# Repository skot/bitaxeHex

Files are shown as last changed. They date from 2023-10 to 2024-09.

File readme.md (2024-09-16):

Warning: the bitaxeHex is unfinished. there may be hardware and firmware bugs. Please see The bitaxeHex channel on the [OSMU Discord](https://discord.gg/osmu) for the latest status

> Closed Source is Antithetical to Bitcoin

# Presenting: The bitaxeHex
bitaxeHex is a follow on to the [bitaxe](https://github.com/skot/bitaxe) that incorporates six BM1366 ASICs from the Antminer S19XP

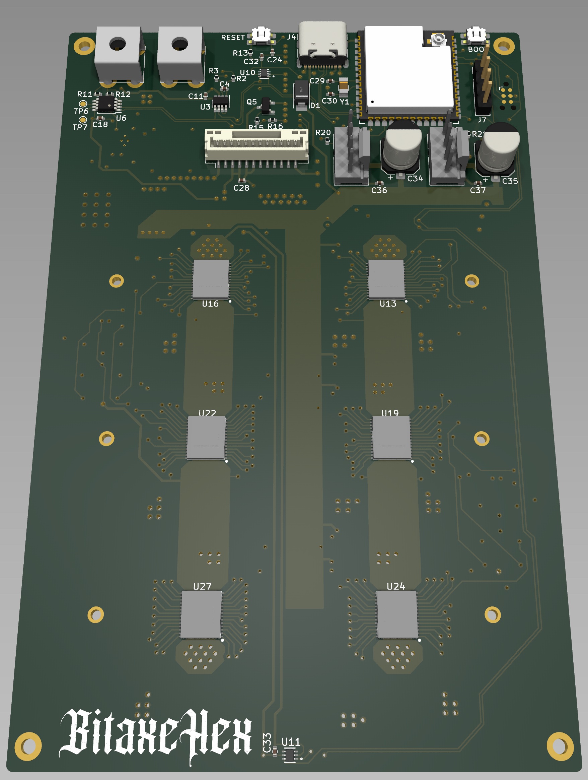
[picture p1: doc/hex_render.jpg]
bitaxeHex render


## Goals
- **Standalone**: can mine directly to your pool over WiFi. No External computer needed.
- **Embedded**: low cost, low maintenance, high availability, high reliability, low power.
- **ASIC**: based on the very efficient BM1366 from Bitmain.
- **Versatile**: solo/pool mining, autotune power/heat/efficiency.
- **Open Source**: All design files are provided.

## Features
- **ESP32-S3-WROOM-1** wifi microcontroller on board
- **TI TPS546D24ARVFR** buck regulator steps down the 12V input to power the chain of BM1366
- **TMP1075** measures inlet and outlet PCB temperature.
- **Microchip EMC2302** Controls dual fans
- Header for optional status LCD

## BM1366
- The BM1366 is a undocumented SHA256 mining ASIC from Bitmain. It's mostly used in the Antminer S19XP and S19K Pro
- Bitmain claims the BM1366 has 21.5 W/TH efficiency
- The BM1366 is available (new) for around $15 each.

## Current Status
- v304 This is going to be the official release candidate, but boards have not been produced yet, this version is not final.
- Power draw is around 50W @12V.
- ESP32 miner firmware will configure the power supply to run at the proper voltage.
- This is an _advanced_ build! If you don't have experience building boards, you should probably go build a single ASIC bitaxe first to get the technique down.

## Notes
- Beware that overclocking doesn't produce a higher hash rate on this board, it only causes more heat generation.
- If you decide to build a pre-release board, be sure to order 2 oz. copper on both the internal and external layers.
- The recommended heatsink is not anodized and very conductive on all surfaces. This _should_ be OK as the ASIC tops are not known to be conductive, but this needs some more investigation.

## Revision List
- v304 is a work in progress, some capacitor changes, additional features
- v303 has some improvements in the layout and the 33R inline resistors have been removed.
- V302 is the current working version of this board.  If you want to build this, pull down this git tag.
- V301 does not work, the power supply maintains voltage, but overheats in a drastic way
- V300 does not work, the power supply cannot maintain voltage when a load is applied

## Hardware
- [BM1366 from NBTC on AliExpress](https://www.aliexpress.us/item/3256803471845503.html). Both the `AL` and `AG` variants have been known to work.
- [Heatsink](https://www.aliexpress.us/item/3256805608902122.html) 90mm long variant. This will need to have threaded M3 mounting holes added. See the KiCad board file for the pattern
- [Fans](https://www.amazon.com/Noctua-NF-A8-PWM-Premium-Quiet/dp/B00NEMG62M) At least one 80x80mm 12V 4-pin fan. Like the Noctua NF-A8 PWM. Possibly two.
- [Enclosure](https://www.aliexpress.us/item/3256806064761702.html) (several sellers) 130mm long variant. The bitaxeHex needs to be run inside an enclosure to force air through the heatsink and effectively cool the BM1366s
- The TPS546 can potentially benefit from a [small self-adhesive heatsink](https://www.amazon.com/gp/product/B093V6RK58/) on the top of the package.
- All of the parts on the board are listed in the KiCad BOM

## Software
- [ESP-Miner-multichip](https://github.com/bitaxeorg/esp-miner-multichip) a fork of esp-miner to support multiple ASICs like on the bitaxeHex.

## Power Supply Requirements
- bitaxeHex takes 12V DC input via screw terminals. Power supply should be capable of 100W
  - This [120W Brick](https://www.amazon.com/gp/product/B07PWZQ33N) technically works, but gets a little warmer than it should. You'll need to change the end.
  - 12V 15A 110V AliExpress [Bare PSU](https://www.aliexpress.us/item/3256805439916551.html)

## Building
- Check out [building.md](building.md) for PCB ordering tips
- Check out [assembly.md](assembly.md) for assembly tips

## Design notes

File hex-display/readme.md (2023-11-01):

# BitaxeHex display adapter board
This adapater board provides a connection from the BitaxeHex to a 
172x320 SPI interface ST7789 Drive OLED graphic display.  This is 
intended for use on the [bitaxeHex](https://github.com/skot/bitaxeHex).
Currently, the firmware to drive it has not been developed, so this is 
provided in order to facilitate that effort.

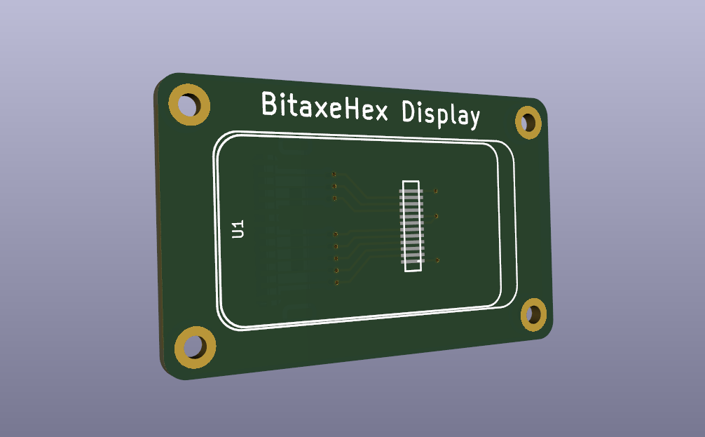
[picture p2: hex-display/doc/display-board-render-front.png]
bitaxeHex display front

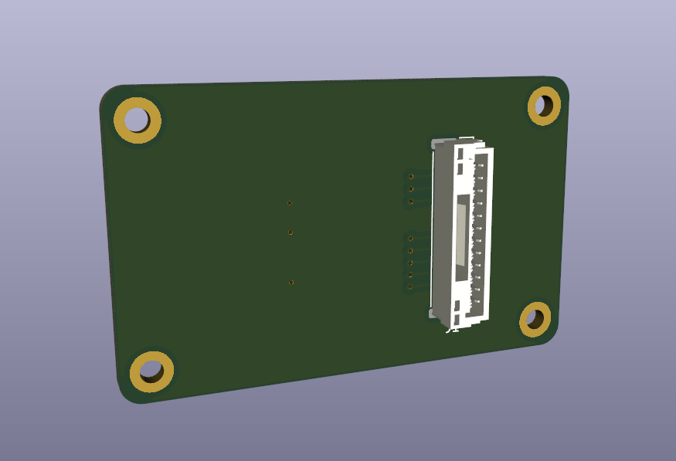
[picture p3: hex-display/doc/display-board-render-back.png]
bitaxeHex display back


The cable to connect it is constructed with a pair of JST-GH 12-pin housings, and 
cables that run straight through.  

## Parts
- [172x320 OLED display](https://www.aliexpress.us/item/3256804691627769.html)
- [JST-GH 12-pin housing](https://www.digikey.com/en/products/detail/jst-sales-america-inc/GHR-12V-S/807824)
- [JST-GH pre-crimped wires](https://www.digikey.com/en/products/detail/jst-sales-america-inc/AGHGH28K305/6009450)

To construct the cable:
- qty 12 of the pre-crimped cables
- qty 2 of the JST-GH housings

Insert the cables into the housings with the locking pin facing the same direction (both towards you)

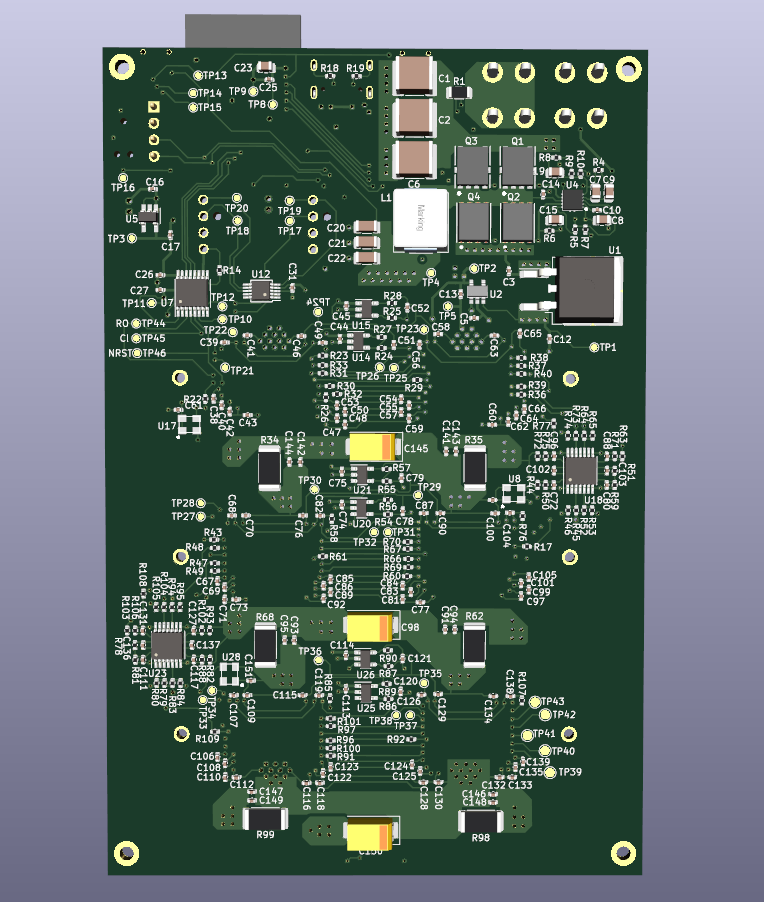
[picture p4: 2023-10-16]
doc/render-back.png

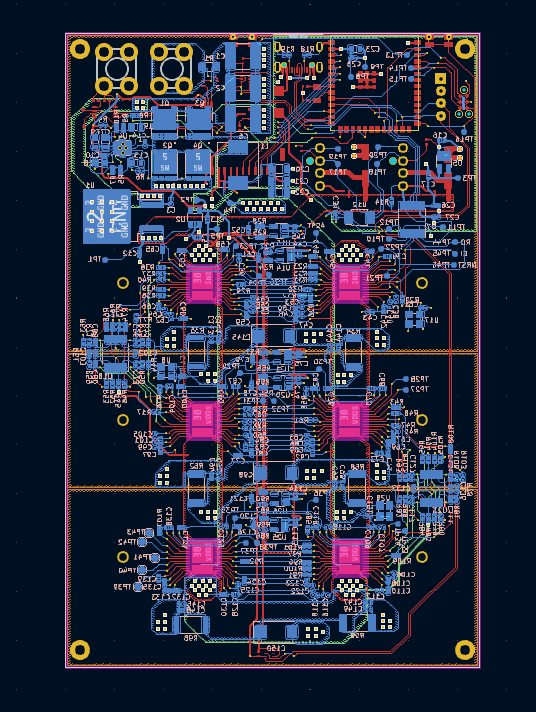
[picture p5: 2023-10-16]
doc/pcb-snapshot.png

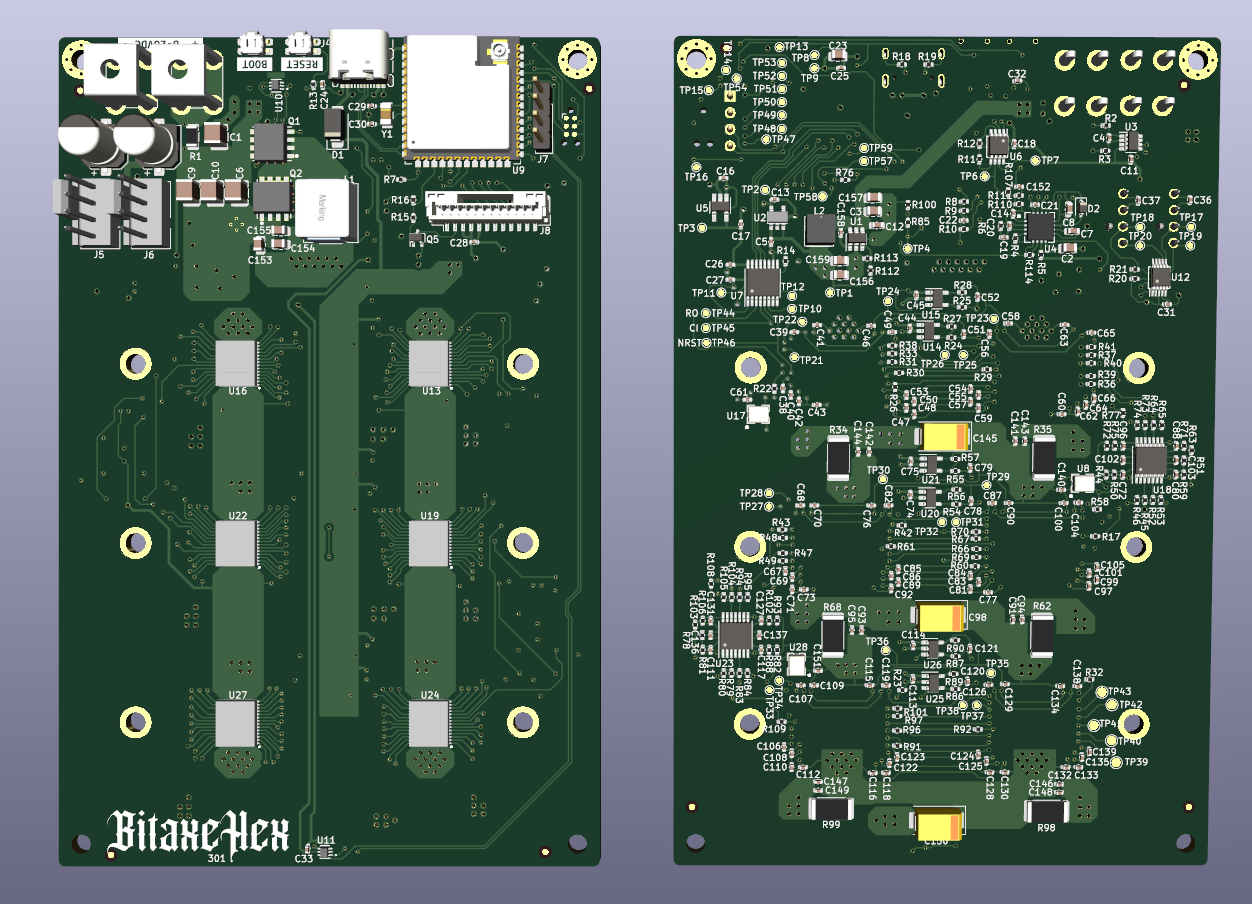
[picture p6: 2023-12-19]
doc/bitaxeHex-301-render.png

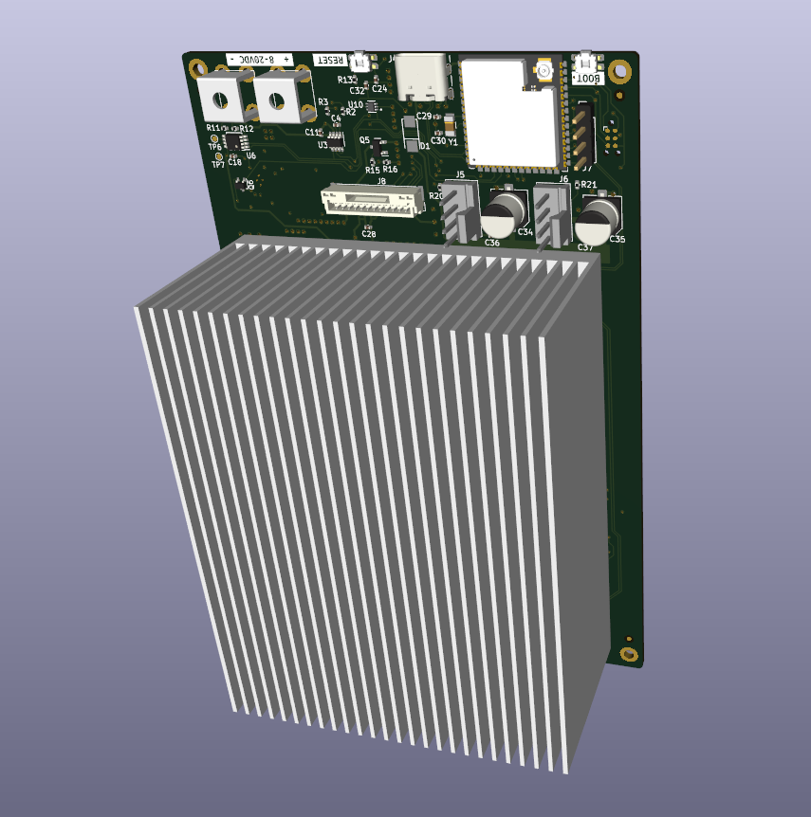
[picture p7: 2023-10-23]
doc/render1-with-heatsink.png

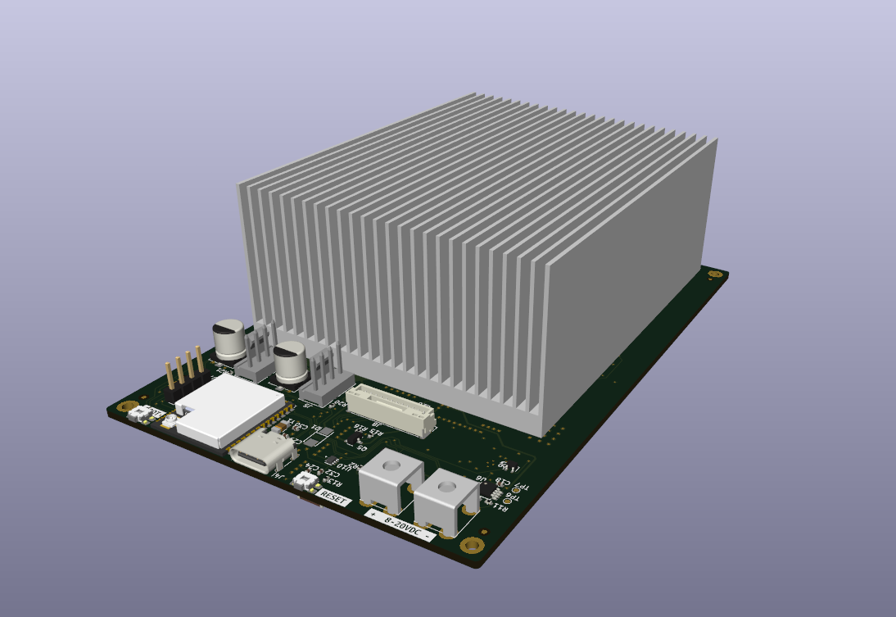
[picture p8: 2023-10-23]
doc/render2-with-heatsink.png

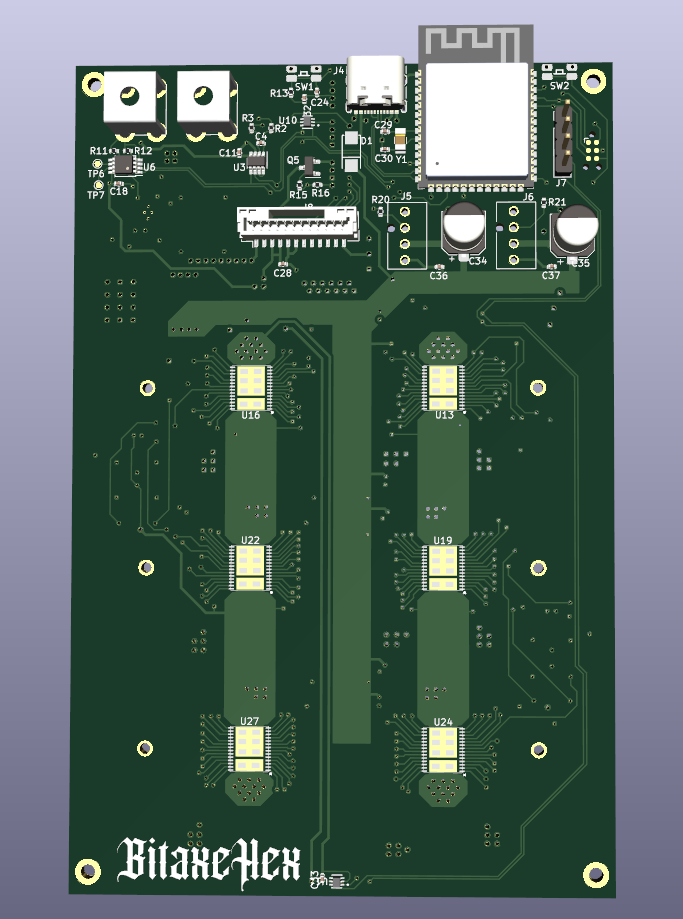
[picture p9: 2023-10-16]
doc/render-front.png

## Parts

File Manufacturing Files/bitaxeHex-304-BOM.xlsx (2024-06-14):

 | Bitaxe Hex v304 BOM
Qty | Reference | Value | Footprint | DK | PARTNO
5 | C1, C3, C18, C20, C31 | 10uF | Capacitor_SMD:C_0805_2012Metric | 490-18664-1-ND | GRM21BR61H106ME43L
1 | C2 | 4.7nF | Capacitor_SMD:C_0402_1005Metric | 490-1309-1-ND | GRM155R71E472KA01D
4 | C4, C7, C8, C10 | 22uF | Capacitor_SMD:C_1206_3216Metric | 445-6000-1-ND | C3216X5R1E226M160AB
1 | C5 | 1uF | Capacitor_SMD:C_0603_1608Metric | 490-1550-1-ND | GRM188R60J105KA01D
1 | C6 | 0.1uF | Capacitor_SMD:C_0603_1608Metric | 478-KGM15BR71H104KTCT-ND | KGM15BR71H104KT
2 | C9, C154 | 47uF | Capacitor_SMD:C_1206_3216Metric | 445-C3216X5R1E476M160DCCT-ND | C3216X5R1E476M160DC
91 | C11, C19, C21, C25, C32, C45, C46, C47, C48, C49, C52, C53, C54, C55, C56, C57, C58, C59, C61, C63, C64, C65, C66, C67, C69, C70, C71, C72, C74, C75, C76, C77, C78, C79, C80, C81, C83, C85, C86, C87, C88, C89, C90, C91, C92, C94, C96, C97, C98, C99, C100, C102, C103, C104, C105, C107, C108, C109, C110, C112, C113, C114, C115, C116, C117, C118, C119, C120, C123, C124, C125, C126, C127, C128, C129, C131, C133, C134, C135, C136, C137, C138, C139, C141, C143, C144, C145, C146, C148, C149, C150 | 1uF | Capacitor_SMD:C_0402_1005Metric | 587-5514-1-ND | EMK105BJ105MV-F
19 | C12, C33, C50, C51, C60, C62, C73, C82, C84, C93, C95, C106, C111, C121, C122, C130, C132, C142, C147 | 0.1uF | Capacitor_SMD:C_0402_1005Metric | 478-KGM05AR71C104KHCT-ND | KGM05AR71C104KH
1 | C13 | 100nF | Capacitor_SMD:C_0402_1005Metric | 490-6321-1-ND | GRM155R71A104KA01D
2 | C14, C15 | 1uF | Capacitor_SMD:C_0805_2012Metric | 587-1291-1-ND | TMK212BJ105KG-T
2 | C16, C26 | 2.2nF | Capacitor_SMD:C_0402_1005Metric | 490-8257-1-ND | GRM155R61H222KA01D
1 | C17 | 4.7uF | Capacitor_SMD:C_0402_1005Metric | 490-14306-1-ND | GRM155R61A475MEAAD
1 | C22 | 1nF | Capacitor_SMD:C_0805_2012Metric | 311-1127-1-ND | CC0805KRX7R9BB102
1 | C23 | 100nF | Capacitor_SMD:C_0805_2012Metric | 478-KGM21NR71E104KTCT-ND | KGM21NR71E104KT
1 | C24 | 100pF | Capacitor_SMD:C_0402_1005Metric | 732-7431-1-ND | 885012000000
3 | C27, C28, C29 | 47uF | Capacitor_SMD:C_1210_3225Metric | 445-1405-1-ND | C3225X5R0J476M250AA
2 | C30, C151 | 100uF | Capacitor_SMD:C_1210_3225Metric | 490-10534-1-ND | GRM32EE70J107ME15L
7 | C34, C35, C38, C39, C40, C43, C44 | 311-3342-1-ND | Capacitor_SMD:C_0402_1005Metric | 478-KGM05AR71C104KHCT-ND | KGM05AR71C104KH
2 | C41, C42 | 220uF | Capacitor_SMD:CP_Elec_6.3x7.7 | 732-8422-1-ND | 865080000000
3 | C68, C101, C140 | 330uF | Capacitor_Tantalum_SMD:CP_EIA-7343-31_Kemet-D_Pad2.25x2.55mm_HandSolder | 718-1028-1-ND | 293D337X9010E2TE3
6 | C152, C153, C160, C161, C162, C163 | 0.01uF | Capacitor_SMD:C_0402_1005Metric | 478-KGM05AR70J103KHCT-ND | KGM05AR70J103KH
1 | J1 | XT30 | bitaxe:XT30PW-M | ~ | XT30PW-M
1 | J3 | Conn_02x05_Odd_Even | Connector_PinHeader_2.54mm:PinHeader_2x05_P2.54mm_Vertical
1 | J6 | Conn_01x06 | Connector_PinHeader_2.54mm:PinHeader_1x06_P2.54mm_Vertical
1 | J7 | USB_C_Receptacle_USB2.0 | Connector_USB:USB_C_Receptacle_GCT_USB4105-xx-A_16P_TopMnt_Horizontal | 2073-USB4105-GF-ACT-ND | USB4105-GF-A
2 | J8, J9 | Conn_01x04 | bitaxe:470531000 | WM4330-ND | 470531000
1 | L1 | 8.2 uH | bitaxe:74438357082 | 732-11745-1-ND | 78438357082
1 | L2 | 680nH | bitaxe:L_Coilcraft_XAL1010-XXX | 2457-XAL1010-681MED-ND | XAL1010-681MED
3 | R1, R2, R3 | 0R | Resistor_SMD:R_0402_1005Metric | 311-0.0JRCT-ND | RC0402JR-070RL
2 | R4, R5 | 17.8K | Resistor_SMD:R_0402_1005Metric | RMCF0402FT17K8CT-ND | RMCF0402FT17K8
22 | R6, R17, R18, R26, R27, R28, R35, R36, R43, R44, R48, R49, R52, R53, R57, R58, R61, R62, R70, R71, R74, R75 | 10k | Resistor_SMD:R_0402_1005Metric | -- mixed values -- | -- mixed values --
1 | R7 | 31.6K | Resistor_SMD:R_0402_1005Metric | YAG3115CT-ND | RC0402FR-0731K6L
1 | R8 | 12.7K | Resistor_SMD:R_0402_1005Metric | YAG2964CT-ND | RC0402FR-0712K7L
2 | R9, R16 | 1.37K | Resistor_SMD:R_0402_1005Metric | YAG3035CT-ND | RC0402FR-071K37L
1 | R10 | 26.1K | Resistor_SMD:R_0402_1005Metric | 311-26.1KLRCT-ND | RC0402FR-0726K1L
1 | R11 | 115k | Resistor_SMD:R_0402_1005Metric | YAG2956CT-ND | RC0402FR-07115KL
4 | R12, R20, R30, R32 | 22.1k | Resistor_SMD:R_0402_1005Metric | 311-22.1KLRCT-ND | RC0402FR-0722K1L
1 | R13 | 10R | Resistor_SMD:R_0402_1005Metric | 311-10.0LRCT-ND | RC0402FR-0710RL
1 | R14 | 1R | Resistor_SMD:R_1206_3216Metric | CSR1206FT1R00CT-ND | CSR1206FT1R00
1 | R15 | 49.9R | Resistor_SMD:R_0402_1005Metric | 311-49.9LRCT-ND | RC0402FR-0749R9L
3 | R19, R29, R31 | 7.87k | Resistor_SMD:R_0402_1005Metric | 311-7.87KLRCT-ND | RC0402FR-077K87L
1 | R21 | 20k | Resistor_SMD:R_0402_1005Metric | 311-20.0KLRCT-ND | RC0402FR-0720KL
4 | R22, R23, R78, R79 | 5.1k | Resistor_SMD:R_0402_1005Metric | 13-RC0402FR-135K1LCT-ND | RC0402FR-135K1L
2 | R24, R25 | 5.6k | Resistor_SMD:R_0402_1005Metric | 13-RC0402FR-135K6LCT-ND | RC0402FR-135K6L
3 | R33, R46, R68 | 2k | Resistor_SMD:R_0402_1005Metric | YAG2303CT-ND | RT0402BRD072KL
18 | R34, R37, R42, R45, R47, R50, R51, R54, R55, R56, R59, R60, R67, R69, R72, R73, R76, R77 | 1k | Resistor_SMD:R_0402_1005Metric | 311-1.00KLRCT-ND | RC0402FR-071KL
2 | SW1, SW2 | SWITCH-SPST | bitaxe:TL3340-switch | EG4627CT-ND | TL3340AF160QG
1 | U1 | LMR54410 | Package_TO_SOT_SMD:SOT-23-6 | 296-LMR54410DBVRCT-ND | LMR54410FDBVR
1 | U2 | RT9080-33GJ5 | bitaxe:RT9080-33GJ5 | 1028-1509-1-ND | RT9080-33GJ5
1 | U3 | TPS546D24ARVFR | bitaxe:LQFN40-CLIP | 296-TPS546D24ARVFRCT-ND | TPS546D24ARVFR
1 | U4 | MIC5504 | Package_TO_SOT_SMD:SOT-23-5_HandSoldering | 576-4879-1-ND | MIC5504-1.8YM5-TR
1 | U5 | SN74AVC4T774 | Package_SO:TSSOP-16_4.4x5mm_P0.65mm | 296-24739-1-ND | SN74AVC4T774PWR
1 | U6 | ESP32-S3-WROOM-1 | bitaxe:ESP32-S3-WROOM-1U | 1965-ESP32-S3-WROOM-1U-N16R8CT-ND | ESP32-S3-WROOM-1U-N16R8
2 | U7, U8 | TMP1075 | bitaxe:HVSSOP-8_3x3mm_P0.65mm | 296-TMP1075DGKRCT-ND | TMP1075DGKR
1 | U9 | EMC2302 | Package_SO:MSOP-10_3x3mm_P0.5mm | EMC2302-2-AIZL-CT-ND | EMC2302-2-AIZL-TR
3 | U10, U17, U23 | SGM2036-0v8 | Package_TO_SOT_SMD:TSOT-23-5
3 | U11, U16, U24 | SGM2036-1v8 | Package_TO_SOT_SMD:TSOT-23-5
4 | U12, U13, U22, U25 | BM1366_mode1 | bitaxe:BM1366
3 | U14, U19, U26 | 25MHz | bitaxe:O 25,0-JO32-B-1V3-1-T1-LF | 1908-O250-JO32-B-1V3-1-T1-LFCT-ND | O 25,0-JO32-B-1V3-1-T1-LF
2 | U15, U21 | TLV3544 | Package_SO:TSSOP-14_4.4x5mm_P0.65mm | 296-45352-1-ND | TLV3544IPWR
2 | U18, U20 | BM1366_mode0 | bitaxe:BM1366

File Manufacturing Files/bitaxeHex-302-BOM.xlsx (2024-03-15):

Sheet: bitaxeHex
Bitaxe Hex v302 BOM
Qty | Reference(s) | Value | Footprint | DK | PARTNO
1 | R1 | DNP | Resistor_SMD:R_0402_1005Metric
1 | R2 | 17.8K | Resistor_SMD:R_0402_1005Metric | RMCF0402FT17K8TR-ND | RMCF0402FT17K8TR
1 | R3 | DNP | Resistor_SMD:R_0402_1005Metric
1 | R4 | 17.8K | Resistor_SMD:R_0402_1005Metric | RMCF0402FT17K8TR-ND | RMCF0402FT17K8
1 | R5 | 10K | Resistor_SMD:R_0402_1005Metric | RMCF0402FT10K0TR-ND | RMCF0402FT10K0
1 | R6 | 31.6K | Resistor_SMD:R_0402_1005Metric | YAG3115TR-ND | RC0402FR-0731K6L
1 | R7 | DNP | Resistor_SMD:R_0402_1005Metric
1 | R10 | 26.1K | Resistor_SMD:R_0402_1005Metric | 311-26.1KLRTR-ND | RC0402FR-0726K1L
22 | R15, R18, R22, R28, R29, R30, R47, R48, R59, R60, R67, R68, R75, R76, R81, R82, R86, R87, R100, R101, R105, R106 | 10k | Resistor_SMD:R_0402_1005Metric | 311-10KJRCT-ND | RC0402JR-0710KL
1 | R8 | 12.7K | Resistor_SMD:R_0402_1005Metric | YAG2964CT-ND | RC0402FR-0712K7L
2 | R9, R17 | 1.37K | Resistor_SMD:R_0402_1005Metric | YAG3035CT-ND | RC0402FR-071K37L
10 | R11, R31, R32, R33, R54, R55, R57, R88, R89, R90 | 115k | Resistor_SMD:R_0402_1005Metric | YAG2956CT-ND | RC0402FR-07115KL
2 | R12, R20 | 22.1k | Resistor_SMD:R_0402_1005Metric | 311-22.1KLRCT-ND | RC0402FR-0722K1L
1 | R13 | 10R | Resistor_SMD:R_0402_1005Metric | 311-10.0LRCT-ND | RC0402FR-0710RL
1 | R14 | 1R | Resistor_SMD:R_1206_3216Metric | CSR1206FT1R00CT-ND | CSR1206FT1R00
1 | R16 | 49.9R | Resistor_SMD:R_0402_1005Metric | 311-49.9LRCT-ND | RC0402FR-0749R9L
1 | R19 | 7.87k | Resistor_SMD:R_0402_1005Metric | 311-7.87KLRCT-ND | RC0402FR-077K87L
1 | R21 | 20k | Resistor_SMD:R_0402_1005Metric | 311-20.0KLRCT-ND | RC0402FR-0720KL
19 | R23, R46, R52, R58, R62, R66, R71, R74, R77, R79, R80, R84, R85, R94, R99, R102, R104, R107, R108 | 1k | Resistor_SMD:R_0402_1005Metric | 311-1.00KLRCT-ND | RC0402FR-071KL
2 | R24, R25 | 5.1k | Resistor_SMD:R_0402_1005Metric | 13-RC0402FR-135K1LCT-ND | RC0402FR-135K1L
2 | R26, R27 | 5.6k | Resistor_SMD:R_0402_1005Metric | 13-RC0402FR-135K6LCT-ND | RC0402FR-135K6L
3 | R34, R56, R91 | 402K | Resistor_SMD:R_0402_1005Metric | YAG3151CT-ND | RC0402FR-07402KL
20 | R35, R36, R37, R41, R43, R44, R45, R49, R50, R51, R61, R69, R70, R72, R78, R83, R92, R93, R95, R103 | 33 | Resistor_SMD:R_0402_1005Metric | 311-33.0LRCT-ND | RC0402FR-0733RL
6 | R38, R39, R63, R65, R96, R98 | 1 | Resistor_SMD:R_2512_6332Metric | CRM2512-JW-1R0ELFCT-ND | CRM2512-JW-1R0ELF
3 | R40, R64, R97 | 2k | Resistor_SMD:R_0402_1005Metric | YAG2303CT-ND | RT0402BRD072KL
6 | R42, R53, R73, R109, R110, R111 | 0 | Resistor_SMD:R_0402_1005Metric | 311-0.0JRCT-ND | RC0402JR-070RL
1 | C1 | 4.7nF | Capacitor_SMD:C_0402_1005Metric | 490-1309-1-ND | GRM155R71E472KA01D
2 | C2, C29 | 180uF | Capacitor_SMD:CP_Elec_6.3x5.9 | P16479CT-ND | 16SVPF180M
5 | C3, C11, C19, C20, C30 | 10uF | Capacitor_SMD:C_0805_2012Metric | 490-18664-1-ND | GRM21BR61H106ME43L
4 | C4, C7, C8, C10 | 22uF | Capacitor_SMD:C_1210_3225Metric | 490-3889-1-ND | GRM32ER61E226KE15L
1 | C5 | 1uF | Capacitor_SMD:C_0603_1608Metric | 490-1550-1-ND | GRM188R60J105KA01D
1 | C6 | 0.1uF | Capacitor_SMD:C_0603_1608Metric | 478-KGM15BR71H104KTCT-ND | KGM15BR71H104KT
99 | C9, C17, C21, C24, C31, C45, C46, C47, C48, C51, C52, C53, C54, C55, C56, C57, C58, C59, C61, C63, C64, C65, C66, C67, C69, C70, C71, C72, C74, C75, C76, C77, C78, C79, C80, C81, C83, C85, C86, C87, C88, C89, C90, C91, C92, C93, C94, C96, C98, C99, C100, C101, C102, C104, C105, C106, C107, C108, C110, C111, C112, C113, C114, C116, C117, C118, C119, C120, C121, C122, C123, C124, C125, C128, C129, C130, C131, C132, C133, C134, C135, C137, C139, C140, C141, C142, C143, C144, C145, C146, C148, C150, C151, C152, C153, C154, C156, C157, C158 | 1uF | Capacitor_SMD:C_0402_1005Metric | 587-5514-1-ND | EMK105BJ105MV-F
27 | C12, C32, C33, C34, C35, C38, C39, C40, C43, C44, C49, C50, C60, C62, C73, C82, C84, C95, C97, C109, C115, C126, C127, C136, C138, C149, C155 | 0.1uF | Capacitor_SMD:C_0402_1005Metric | 478-KGM05AR71C104KHCT-ND | KGM05AR71C104KH
1 | C13 | 100nF | Capacitor_SMD:C_0402_1005Metric | 490-6321-1-ND | GRM155R71A104KA01D
2 | C14, C15 | 1uF | Capacitor_SMD:C_0805_2012Metric | 587-1291-1-ND | TMK212BJ105KG-T
2 | C16, C26 | 2.2nF | Capacitor_SMD:C_0402_1005Metric | 490-8257-1-ND | GRM155R61H222KA01D
1 | C18 | 4.7uF | Capacitor_SMD:C_0402_1005Metric | 490-14306-1-ND | GRM155R61A475MEAAD
1 | C22 | 1nF | Capacitor_SMD:C_0805_2012Metric | 311-1127-1-ND | CC0805KRX7R9BB102
1 | C23 | 100nF | Capacitor_SMD:C_0805_2012Metric | 478-KGM21NR71E104KTCT-ND | KGM21NR71E104KT
1 | C25 | 100pF | Capacitor_SMD:C_0402_1005Metric | 732-7431-1-ND | 885012005013
2 | C27, C28 | 47uF | Capacitor_SMD:C_1210_3225Metric | 490-6539-1-ND | GRM32ER61C476KE15L
2 | C41, C42 | 220uF | Capacitor_SMD:CP_Elec_6.3x7.7 | 732-8422-1-ND | 865080345012
3 | C68, C103, C147 | 330uF | Capacitor_Tantalum_SMD:CP_EIA-7343-31_Kemet-D_Pad2.25x2.55mm_HandSolder | 718-1028-1-ND | 293D337X9010E2TE3
1 | L1 | 8.2 uH | bitaxe:74438357082 | 732-11745-1-ND | 78438357082
1 | L2 | 680nH | Inductor_SMD:L_Coilcraft_XAL1010-XXX | 2457-XAL1010-681MED-ND | XAL1010-681MED
1 | Q1 | 2N7002K | Package_TO_SOT_SMD:SOT-323_SC-70 | 2N7002KWCT-ND | 2N7002KW
1 | D1 | SS310 | Diode_SMD:D_SMA | SK310A-LTPMSCT-ND | SK310A-LTP
1 | U1 | LMR54410 | Package_TO_SOT_SMD:SOT-23-6 | 296-LMR54410DBVRCT-ND | LMR54410FDBVR
1 | U2 | RT9080-33GJ5 | bitaxe:RT9080-33GJ5 | 1028-1509-1-ND | RT9080-33GJ5
1 | U3 | TPS546D24ARVFR | bitaxe:LQFN40-CLIP | 296-TPS546D24ARVFRCT-ND | TPS546D24ARVFR
1 | U4 | MIC5504 | Package_TO_SOT_SMD:SOT-23-5_HandSoldering | 576-4879-1-ND | MIC5504-1.8YM5-TR
1 | U5 | SN74AVC4T774 | Package_SO:TSSOP-16_4.4x5mm_P0.65mm | 296-24739-1-ND | SN74AVC4T774PWR
1 | U6 | ESP32-S3-WROOM-1 | bitaxe:ESP32-S3-WROOM-1U | 1965-ESP32-S3-WROOM-1U-N16R8CT-ND | ESP32-S3-WROOM-1U-N16R8
2 | U7, U8 | TMP1075 | bitaxe:SOT5X3-6_DRL_TEX | 296-TMP1075NDRLRCT-ND | TMP1075NDRLR
1 | U9 | EMC2302 | Package_SO:MSOP-10_3x3mm_P0.5mm | EMC2302-2-AIZL-CT-ND | EMC2302-2-AIZL-TR
6 | U10, U11, U16, U17, U23, U24 | AP7331 | Package_TO_SOT_SMD:TSOT-23-5 | AP7331-WG-7DICT-ND | AP7331-WG-7
6 | U12, U13, U18, U20, U22, U25 | BM1366 | bitaxe:BM1366
3 | U14, U19, U26 | 25MHz | bitaxe:O 25,0-JO32-B-1V3-1-T1-LF | 1908-O250-JO32-B-1V3-1-T1-LFCT-ND | O 25,0-JO32-B-1V3-1-T1-LF
2 | U15, U21 | TLV3544 | Package_SO:TSSOP-14_4.4x5mm_P0.65mm | 296-45352-1-ND | TLV3544IPWR
2 | SW1, SW2 | SWITCH-SPST | bitaxe:EVQ9P701P-switch | P19095CT-ND | EVQ-9P701P
2 | J1, J2 | Screw Terminal | bitaxe:7771-screw-terminal | 36-7771-ND | 36-7771
1 | J3 | Conn_02x05 | Connector_PinHeader_2.54mm:PinHeader_2x05_P2.54mm_Vertical
1 | J4 | Connector-12x1 | bitaxe:JST_GH_BM12B-GHS-TBT_1x12-1MP_P1.25mm_Vertical | 455-BM12B-GHS-TBTCT-ND | BM12B-GHS-TBT
1 | J7 | USB_C_Receptacle | Connector_USB:USB_C_Receptacle_GCT_USB4105-xx-A_16P_TopMnt_Horizontal | 2073-USB4105-GF-ACT-ND | USB4105-GF-A
2 | J8, J9 | Conn_01x04 | bitaxe:470531000 | WM4330-ND | 470531000

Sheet: Config
Config resistors
Pin |  |  | RefDes | Code | Rvalue
MSEL2 | Rmsel2t | top | R1
 | Rmsel2b | bottom | R5 |  | 0R
VSEL | Rvselt | top | R2 | 10 | 2.05K
 | Rvselb | bottom | R6 | 0 | 4.64K
ADRSEL | Radrt | top | R3 | 6 | 10K
 | Radrb | bottom | R7 | 4 | 10K
MSEL1 | Rmsel1t | top | R4 | 2 | 205.0K
 | Rmsel1b | bottom | R10 | 15 | 82.5K

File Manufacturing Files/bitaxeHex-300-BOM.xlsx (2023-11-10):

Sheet: BOM
Qty | Ref Des | Value | DK | Manufacturer | PARTNO | DNP
3 | C1, C2, C6 | 22uF | 445-1655-1-ND |  | CKG57NX5R1H226M500JH
1 | C3 | 0.33uF | 490-GRM155R61J334ME01JCT-ND |  | GRM155R61J334ME01J
1 | C4 | 1uF | 587-5514-1-ND |  | EMK105BJ105MV-F | DNP
101 | C5, C11, C13, C16, C17, C18, C24, C38, C39, C40, C41, C42, C43, C46, C47, C48, C49, C50, C51, C52, C53, C54, C55, C56, C57, C58, C59, C60, C62, C63, C64, C65, C66, C67, C68, C69, C70, C71, C72, C73, C76, C77, C78, C79, C80, C81, C82, C83, C84, C85, C86, C87, C88, C89, C90, C92, C94, C95, C96, C97, C99, C100, C101, C103, C104, C105, C106, C107, C108, C109, C110, C111, C112, C115, C116, C117, C118, C119, C120, C121, C122, C123, C124, C125, C126, C127, C128, C129, C130, C131, C132, C133, C134, C135, C137, C138, C139, C143, C144, C148, C149 | 1uF | 587-5514-1-ND |  | EMK105BJ105MV-F
1 | C7 | 270pF | 399-C0805C271J5GAC7800CT-ND |  | C0805C271J5GAC7800
1 | C8 | 1uF | 1276-6471-1-ND |  | CL21B105KOFNNNG
1 | C9 | 5600pF | 445-6944-1-ND |  | CGA4C2C0G1H562J060AA
1 | C10 | 3300pF | 1276-1552-1-ND |  | CL05B332KB5NNNC
28 | C12, C14, C25, C26, C27, C28, C31, C32, C33, C36, C37, C44, C45, C61, C74, C75, C91, C93, C102, C113, C114, C136, C140, C141, C142, C146, C147, C151 | 0.1uF | 1292-1639-1-ND |  | 0402X104K100CT
1 | C15 | 4.7uF | 490-14466-1-ND |  | GRM21BR71C475KE51L
1 | C19 | 680pF | 311-1126-1-ND |  | CC0805KRX7R9BB681
3 | C20, C21, C22 | 10uF | 1276-6641-1-ND |  | CL31B106MOHNNNE
1 | C23 | 10uF | 1276-1096-1-ND |  | CL21A106KOQNNNE
2 | C29, C30 | 6.8pF | 399-C0402C689C5GAC7867CT-ND |  | C0402C689C5GAC7867
2 | C34, C35 | 220uF | 732-8422-1-ND |  | 865080345012
3 | C98, C145, C150 | 330uF | 718-1028-1-ND |  | 293D337X9010E2TE3
1 | D1 | SS310 | SK310A-LTPMSCT-ND |  | SK310A-LTP
1 | J1 | Screw Terminal | 36-7770-ND |  | 36-7770
1 | J2 | Conn_01x01 | A100886CT-ND |  | 63862-1
1 | J4 | USB_C_Receptacle_USB2.0 | 2073-USB4105-GF-ACT-ND |  | USB4105-GF-A
2 | J5, J6 | Conn_01x04 | WM4330-ND |  | 0470531000
1 | J8 | ST7789 176x320 | 455-BM12B-GHS-TBTCT-ND |  | BM12B-GHS-TBT
1 | L1 | 470nH | 732-7221-1-ND |  | 744373580047
2 | Q1, Q3 | NTMFS5C673NLT1G | NTMFS5C673NLT1GOSCT-ND |  | NTMFS5C673NLT1G
2 | Q2, Q4 | CSD17577Q5A | 296-39996-1-ND |  | CSD17577Q5A
1 | Q5 | BSS123 | 4530-BSS123CT-ND |  | BSS123
1 | Q6 | 2N7002K | 2N7002KWCT-ND |  | 2N7002KW
1 | R1 | 2m | 13-PA1206FRE7W0R002ZCT-ND |  | PA1206FRE7W0R002Z
5 | R2, R3, R36, R43, R70 | 0 | 311-0.0JRCT-ND |  | RC0402JR-070RL
1 | R4 | 1.33k | 311-1.33KLRCT-ND |  | RC0402FR-071K33L
1 | R5 | 100k | 311-100KJRCT-ND |  | RC0402JR-07100KL | DNP
1 | R6 | 6.49k | 311-6.49KLRCT-ND |  | RC0402FR-076K49L
20 | R7, R9, R13, R16, R22, R46, R52, R53, R64, R65, R73, R74, R79, R80, R83, R84, R94, R95, R104, R105 | 10k | 311-10KJRCT-ND |  | RC0402JR-0710KL
1 | R8 | 487 | YAG2373CT-ND |  | RC0402FR-07487RL
1 | R10 | 1.54k | YAG3040CT-ND |  | RC0402FR-071K54L
1 | R11 | 80k | 311-80.6KLRCT-ND |  | RC0402FR-0780K6L
1 | R12 | DNP |  |  |  | DNP
1 | R14 | 20K | 311-20.0KLRCT-ND |  | RC0402FR-0720KL
20 | R15, R44, R45, R50, R51, R59, R63, R71, R72, R75, R77, R78, R81, R82, R88, R93, R102, R103, R106, R108 | 1k | 311-1.00KLRCT-ND |  | RC0402FR-071KL
20 | R17, R29, R30, R31, R33, R37, R39, R40, R47, R48, R49, R61, R66, R67, R69, R92, R96, R97, R101, R109 | 33 | 311-33.0LRCT-ND |  | RC0402FR-0733RL
2 | R18, R19 | 5.1k | 13-RC0402FR-135K1LCT-ND |  | RC0402FR-135K1L
2 | R20, R21 | 5.6k | 13-RC0402FR-135K6LCT-ND |  | RC0402FR-135K6L
6 | R23, R32, R38, R41, R42, R58 | 33 | 311-33.0LRCT-ND |  | RC0402FR-0733RL | DNP
3 | R24, R54, R86 | 309k 1% | YAG3108CT-ND |  | RC0402FR-07309KL
3 | R25, R55, R87 | 69.8k 1% | YAG3216CT-ND |  | RC0402FR-0769K8L
3 | R26, R60, R91 | 2k | YAG2303CT-ND |  | RT0402BRD072KL
6 | R27, R28, R56, R57, R89, R90 | 182k 1% | YAG3015CT-ND |  | RC0402FR-07182KL
6 | R34, R35, R62, R68, R98, R99 | 1R 2W | CRM2512-JW-1R0ELFCT-ND |  | CRM2512-JW-1R0ELF
2 | SW1, SW2 | EVQ-9P701P | P19095CT-ND | G-Switch(品赞) | EVQ-9P701P
1 | U1 | uA7805 | 296-20796-1-ND |  | UA7805CKTTR
1 | U2 | RT9080-33GJ5 | 1028-1509-1-ND |  | RT9080-33GJ5
1 | U3 | INA219AID | 296-33291-5-ND | TI(德州仪器) | INA219AID
1 | U4 | TPS40305 | 296-37445-1-ND |  | TPS40305DRCR
1 | U5 | MIC5504 | 576-4879-1-ND |  | MIC5504-1.8YM5-TR
1 | U6 | DS4432U+ | DS4432U+-ND |  | DS4432U+
1 | U7 | SN74AVC4T774 | 296-24739-1-ND |  | SN74AVC4T774PWR
3 | U8, U17, U28 | 25MHz | 1908-O250-JO32-B-1V3-1-T1-LFCT-ND |  | O 25,0-JO32-B-1V3-1-T1-LF
1 | U9 | ESP32-S3-WROOM-1 | 1965-ESP32-S3-WROOM-1U-N16R8CT-ND |  | ESP32-S3-WROOM-1U-N16R8
1 | U10 | TMP1075 | 296-TMP1075NDRLRCT-ND |  | TMP1075NDRLR
1 | U11 | TMP1075 | 296-TMP1075NDRLRCT-ND |  | TMP1075NDRLR
1 | U12 | EMC2302 | EMC2302-2-AIZL-CT-ND |  | EMC2302-2-AIZL-TR
2 | U13, U24 | BM1366_mode1
6 | U14, U15, U20, U21, U25, U26 | ADP171AUJ-R7 | 505-ADP171AUJZ-R7CT-ND |  | ADP171AUJZ-R7
2 | U16, U27 | BM1366_mode1
2 | U18, U23 | TLV3544 | 296-45352-1-ND |  | TLV3544IPWR
1 | U19 | BM1366_mode0
1 | U22 | BM1366_mode0
1 | Y1 | 32.768kHz | 728-1074-1-ND |  | SC32S-7PF20PPM

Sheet: DK Order
Qty | Ref Des | DK
3 | C1, C2, C6 | 445-1655-1-ND
1 | C3 | 490-GRM155R61J334ME01JCT-ND
101 | C5, C11, C13, C16, C17, C18, C24, C38, C39, C40, C41, C42, C43, C46, C47, C48, C49, C50, C51, C52, C53, C54, C55, C56, C57, C58, C59, C60, C62, C63, C64, C65, C66, C67, C68, C69, C70, C71, C72, C73, C76, C77, C78, C79, C80, C81, C82, C83, C84, C85, C86, C87, C88, C89, C90, C92, C94, C95, C96, C97, C99, C100, C101, C103, C104, C105, C106, C107, C108, C109, C110, C111, C112, C115, C116, C117, C118, C119, C120, C121, C122, C123, C124, C125, C126, C127, C128, C129, C130, C131, C132, C133, C134, C135, C137, C138, C139, C143, C144, C148, C149 | 587-5514-1-ND
1 | C7 | 399-C0805C271J5GAC7800CT-ND
1 | C8 | 1276-6471-1-ND
1 | C9 | 445-6944-1-ND
1 | C10 | 1276-1552-1-ND
28 | C12, C14, C25, C26, C27, C28, C31, C32, C33, C36, C37, C44, C45, C61, C74, C75, C91, C93, C102, C113, C114, C136, C140, C141, C142, C146, C147, C151 | 1292-1639-1-ND
1 | C15 | 490-14306-1-ND
1 | C19 | 311-1126-1-ND
3 | C20, C21, C22 | 445-7592-1-ND
1 | C23 | 1276-1096-1-ND
2 | C29, C30 | 399-C0402C689C5GAC7867CT-ND
2 | C34, C35 | 732-8422-1-ND
3 | C98, C145, C150 | 718-1028-1-ND
1 | D1 | SK310A-LTPMSCT-ND
1 | J1 | 36-7770-ND
1 | J2 | A100886CT-ND
1 | J4 | 2073-USB4105-GF-ACT-ND
2 | J5, J6 | WM4330-ND
1 | J8 | 455-BM12B-GHS-TBTCT-ND
1 | L1 | 732-7221-1-ND
2 | Q1, Q3 | NTMFS5C673NLT1GOSCT-ND
2 | Q2, Q4 | 296-39996-1-ND
1 | Q5 | 4530-BSS123CT-ND
1 | Q6 | 2N7002KWCT-ND
1 | R1 | 13-PA1206FRE7W0R002ZCT-ND
5 | R2, R3, R36, R43, R70 | 311-0.0JRCT-ND
1 | R4 | 311-1.33KLRCT-ND
1 | R5 | 311-100KJRCT-ND
1 | R6 | 311-6.49KLRCT-ND
20 | R7, R9, R13, R16, R22, R46, R52, R53, R64, R65, R73, R74, R79, R80, R83, R84, R94, R95, R104, R105 | 311-10KJRCT-ND
1 | R8 | YAG2373CT-ND
1 | R10 | YAG3040CT-ND
1 | R11 | 311-80.6KLRCT-ND
1 | R14 | 311-20.0KLRCT-ND
20 | R15, R44, R45, R50, R51, R59, R63, R71, R72, R75, R77, R78, R81, R82, R88, R93, R102, R103, R106, R108 | 311-1.00KLRCT-ND
20 | R17, R29, R30, R31, R33, R37, R39, R40, R47, R48, R49, R61, R66, R67, R69, R92, R96, R97, R101, R109 | 311-33.0LRCT-ND
2 | R18, R19 | 13-RC0402FR-135K1LCT-ND
2 | R20, R21 | 13-RC0402FR-135K6LCT-ND
3 | R24, R54, R86 | YAG3108CT-ND
3 | R25, R55, R87 | YAG3216CT-ND
3 | R26, R60, R91 | YAG2303CT-ND
6 | R27, R28, R56, R57, R89, R90 | YAG3015CT-ND
6 | R34, R35, R62, R68, R98, R99 | 118-CR2512-F/-1R00ELFCT-ND
2 | SW1, SW2 | P19095CT-ND
1 | U1 | 296-20796-1-ND
1 | U2 | 1028-1509-1-ND
1 | U3 | 296-33291-5-ND
1 | U4 | 296-37445-1-ND
1 | U5 | 576-4879-1-ND
1 | U6 | DS4432U+-ND
1 | U7 | 296-24739-1-ND
3 | U8, U17, U28 | 1908-O250-JO32-B-1V3-1-T1-LFCT-ND
1 | U9 | 1965-ESP32-S3-WROOM-1U-N16R8CT-ND
1 | U10 | 296-TMP1075NDRLRCT-ND
1 | U11 | 296-TMP1075NDRLRCT-ND
1 | U12 | EMC2302-2-AIZL-CT-ND
2 | U13, U24
6 | U14, U15, U20, U21, U25, U26 | 505-ADP171AUJZ-R7CT-ND
2 | U16, U27
2 | U18, U23 | 296-45352-1-ND
1 | U19
1 | U22
1 | Y1 | 728-1074-1-ND

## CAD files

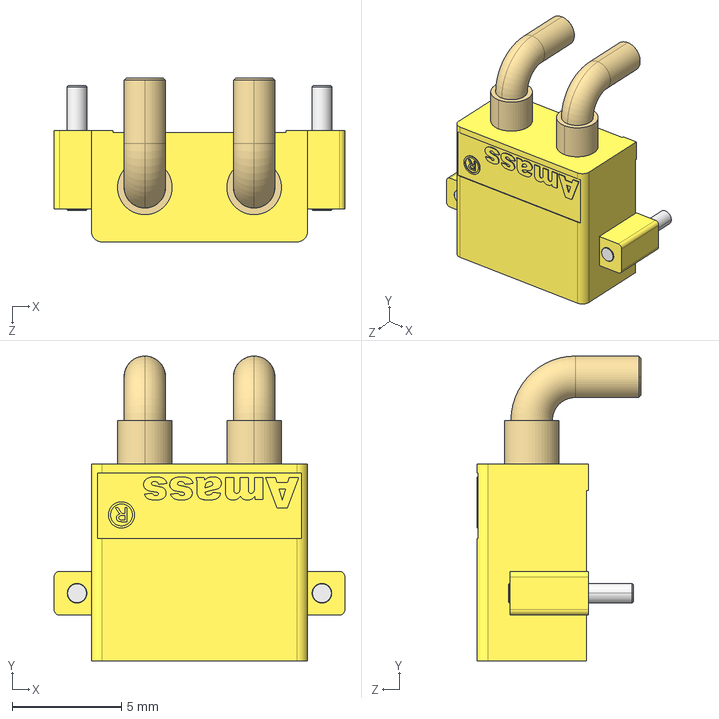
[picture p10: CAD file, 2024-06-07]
3d/XT30PW-M.stp
13.3 x 13.9 x 7.50 mm

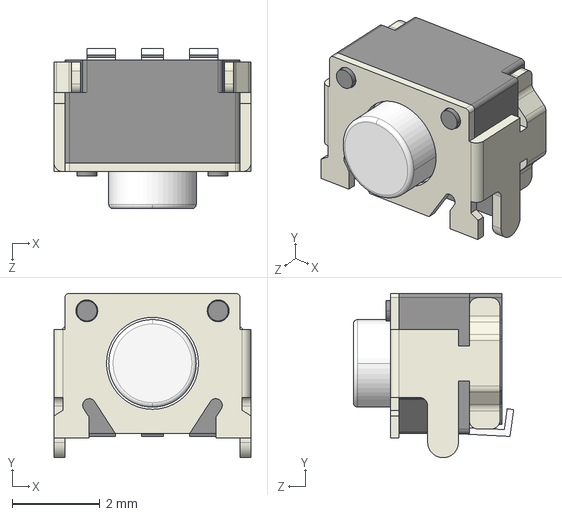
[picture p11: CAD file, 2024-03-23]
3d/TL3340AF160QG.step
4.50 x 3.76 x 3.67 mm

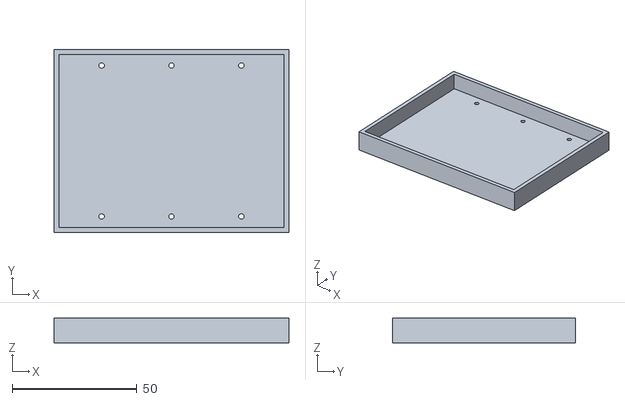
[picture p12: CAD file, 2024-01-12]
3d/heatsink-drill-guide.stl
94.2 x 73.3 x 10.0

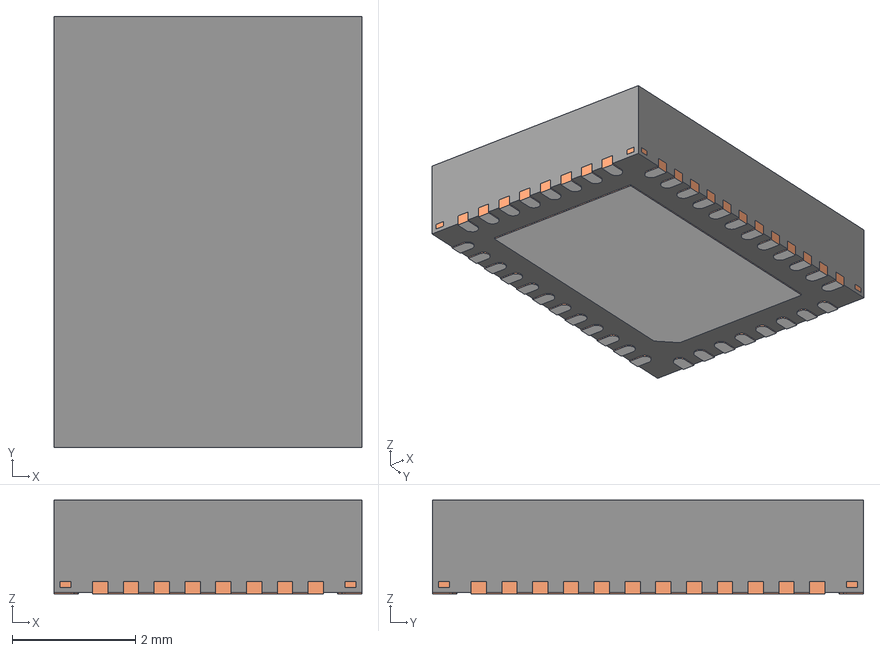
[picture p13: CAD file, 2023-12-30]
3d/RVF0040A.stp
5.00 x 7.00 x 1.52 mm
BODY-QFN
FRAME-RVF0040A
PIN1-ID

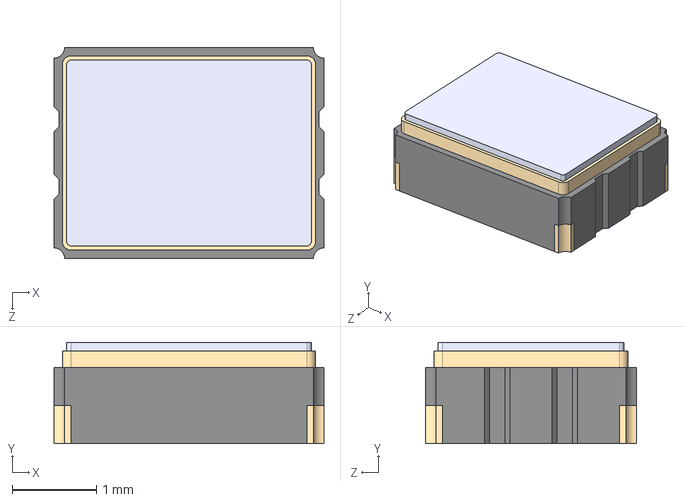
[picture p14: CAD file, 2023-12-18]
3d/3225-oscillator.step
3.20 x 1.20 x 2.50 mm

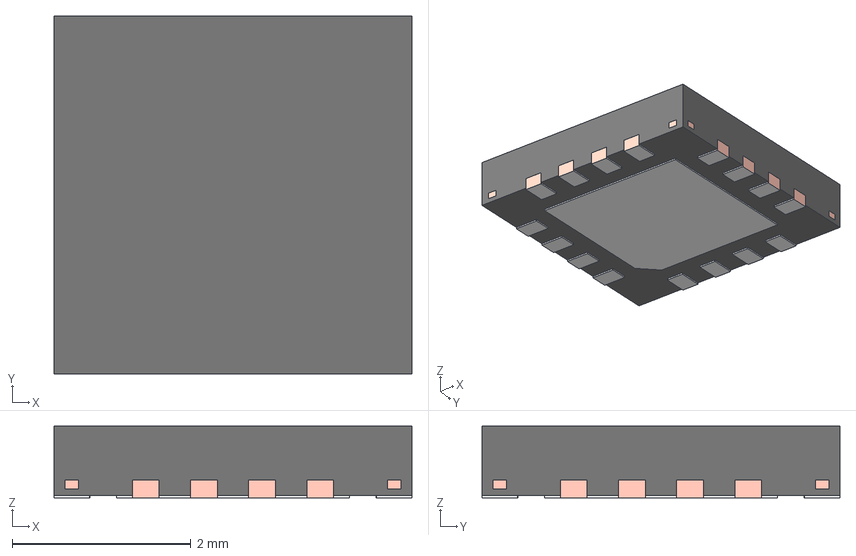
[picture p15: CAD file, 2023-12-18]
3d/RUM0016A.stp
4.00 x 4.00 x 0.8 mm
FRAME
PIN1_AREA

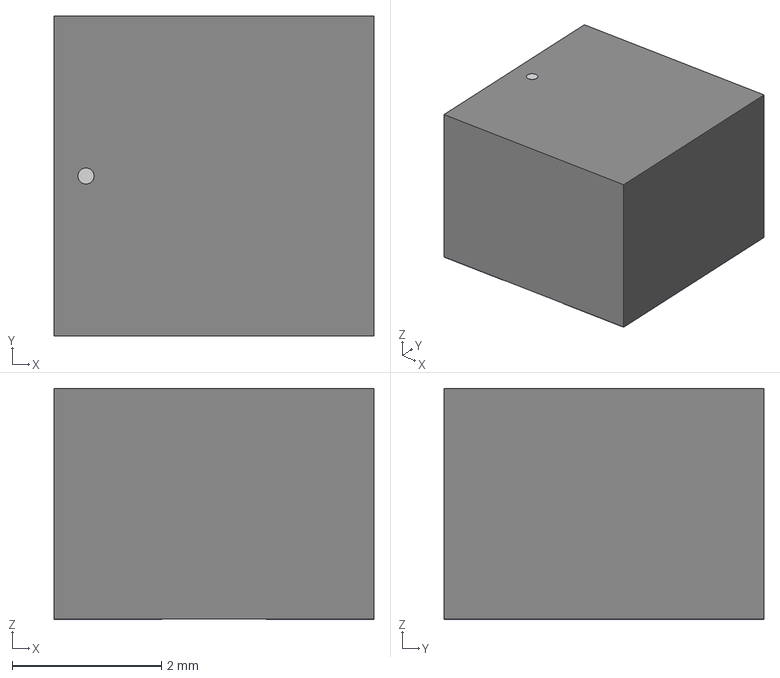
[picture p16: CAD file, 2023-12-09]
3d/IND_4030-WE-MAPI_WRE.step
4.29 x 4.29 x 3.10 mm

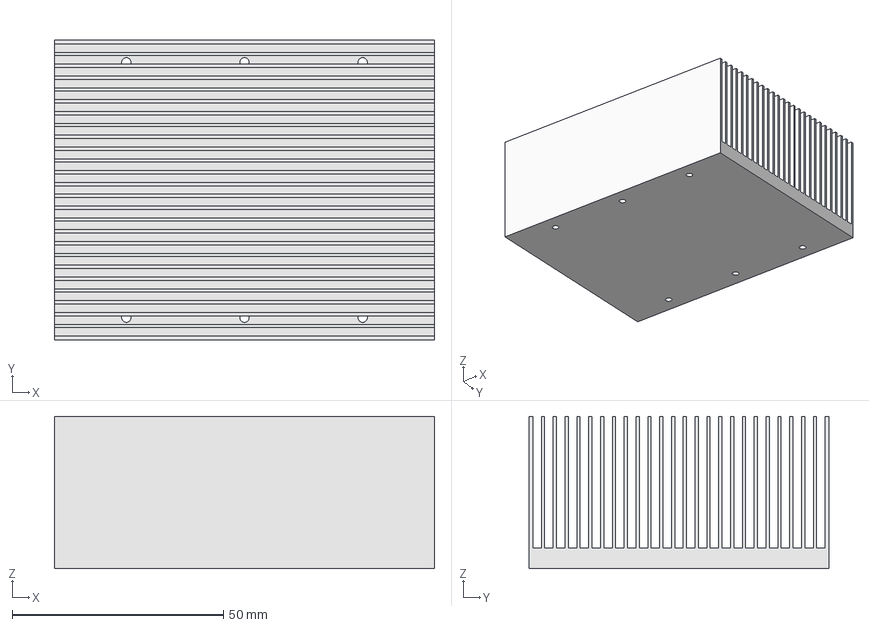
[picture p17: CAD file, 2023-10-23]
3d/heatsink.step
90.0 x 71.0 x 36.0 mm

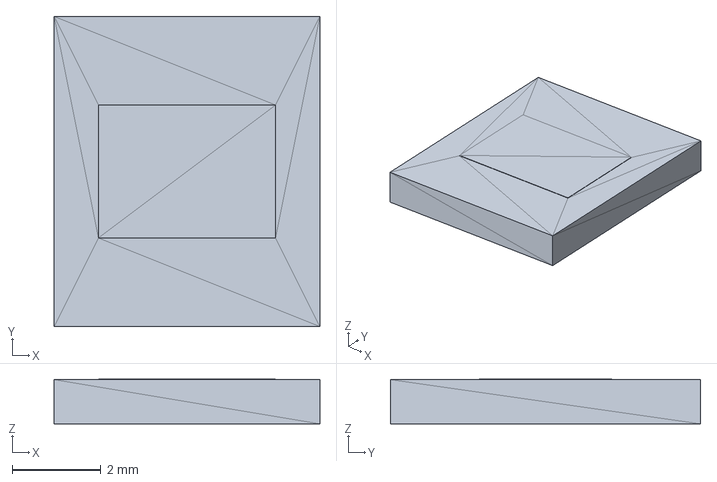
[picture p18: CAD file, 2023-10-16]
3d/bm1366.STP
6.00 x 7.00 x 1.01 mm

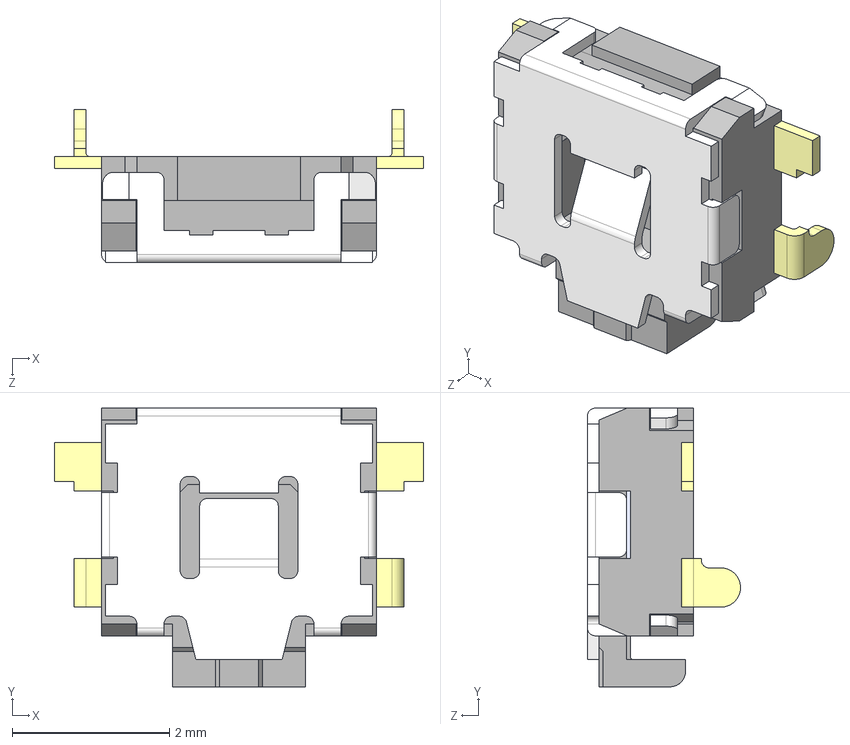
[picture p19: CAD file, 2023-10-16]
3d/EVQ-9P701P.stp
4.70 x 3.55 x 1.95 mm

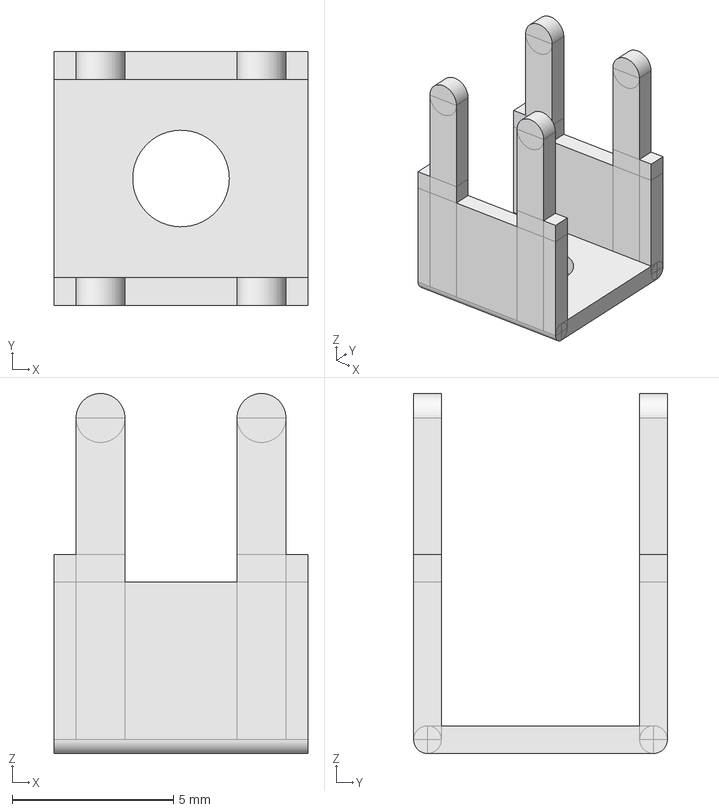
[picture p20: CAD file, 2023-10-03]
3d/7770-ScrewTerminal.step
7.88 x 7.88 x 11.2 mm

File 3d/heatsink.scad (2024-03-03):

//BitAxeHex Heatsink
module heatsink() {
  difference() {
    translate([-45,-35.5,0]) cube([90,71,36]);

    // Center cutout
    translate([-50,-1,4.8]) cube([100,2,50]);

    // minus Y cutouts
    translate([-50,-3.8,4.8]) cube([100,2,50]);
    translate([-50,-6.6,4.8]) cube([100,2,50]);
    translate([-50,-9.4,4.8]) cube([100,2,50]);
    translate([-50,-12.2,4.8]) cube([100,2,50]);
    translate([-50,-15.0,4.8]) cube([100,2,50]);
    translate([-50,-17.8,4.8]) cube([100,2,50]);
    translate([-50,-20.6,4.8]) cube([100,2,50]);
    translate([-50,-23.4,4.8]) cube([100,2,50]);
    translate([-50,-26.2,4.8]) cube([100,2,50]);
    translate([-50,-29.0,4.8]) cube([100,2,50]);
    translate([-50,-31.8,4.8]) cube([100,2,50]);
    translate([-50,-34.6,4.8]) cube([100,2,50]);

    // plus Y cutouts
    translate([-50,1.8,4.8]) cube([100,2,50]);
    translate([-50,4.6,4.8]) cube([100,2,50]);
    translate([-50,7.4,4.8]) cube([100,2,50]);
    translate([-50,10.2,4.8]) cube([100,2,50]);
    translate([-50,13.0,4.8]) cube([100,2,50]);
    translate([-50,15.8,4.8]) cube([100,2,50]);
    translate([-50,18.6,4.8]) cube([100,2,50]);
    translate([-50,21.4,4.8]) cube([100,2,50]);
    translate([-50,24.2,4.8]) cube([100,2,50]);
    translate([-50,27.0,4.8]) cube([100,2,50]);
    translate([-50,29.8,4.8]) cube([100,2,50]);
    translate([-50,32.6,4.8]) cube([100,2,50]);

    // mounting holes
    translate([0,30.25,-0.1]) cylinder(r=1.1, h=5, $fn=24);
    translate([0,-30.25,-0.1]) cylinder(r=1.1, h=5, $fn=24);
    translate([28,30.25,-0.1]) cylinder(r=1.1, h=5, $fn=24);
    translate([28,-30.25,-0.1]) cylinder(r=1.1, h=5, $fn=24);
    translate([-28,30.25,-0.1]) cylinder(r=1.1, h=5, $fn=24);
    translate([-28,-30.25,-0.1]) cylinder(r=1.1, h=5, $fn=24);
  }
}

module drill_guide() {
  difference() {
    translate([-47.1,-36.65,28]) cube([94.2,73.3,10]);     
    translate([-45.6,-35,0]) cube([91.2,70,36]);
    // mounting holes
    translate([0,30.25,35]) cylinder(r=1.1, h=5, $fn=24);
    translate([0,-30.25,35]) cylinder(r=1.1, h=5, $fn=24);
    translate([28,30.25,35]) cylinder(r=1.1, h=5, $fn=24);
    translate([28,-30.25,35]) cylinder(r=1.1, h=5, $fn=24);
    translate([-28,30.25,35]) cylinder(r=1.1, h=5, $fn=24);
    translate([-28,-30.25,35]) cylinder(r=1.1, h=5, $fn=24);
    translate([-40,-25,30]) cube([80,50,10]);
  }    
}

// For modeling
heatsink();
//drill_guide();

// For printing
//translate([0,0,38]) rotate([0,180,0]) drill_guide();

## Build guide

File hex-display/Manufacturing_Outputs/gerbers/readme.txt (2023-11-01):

BitaxeHex Display gerber files

2 copper layers
silkscreen on top only

hex-display-Edge_Cuts.gbr      -Board outline
hex-display-F_Cu.gbr           -Top copper
hex-display-B_Cu.gbr           -Bottom copper
hex-display-F_Mask.gbr         -Top solder mask
hex-display-B_Mask.gbr         -Bottom solder mask
hex-display-F_Silkscreen.gbr   -Top silkscreen
hex-display-PTH.drl            -drill plated-through holes

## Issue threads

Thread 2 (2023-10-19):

USB-C port needs clearance for plug enclosure

skot, 2023-10-19:
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

USB-C plug enclosures can be pretty chunky sometimes. I think we need some more clearance between the USB-C receptacle and the ESP32. Especially if anyones uses the built-in antenna variant.

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

benalleng, 2023-10-20:
What about using an upright receptacle?
https://www.molex.com/en-us/products/part-detail/2169890001 certainly not as many options as a standard unit but not any more expensive.

macphyter, 2023-12-17:
@benalleng This could be an option if we are desperate, but I worry a little about durability.  That looks like it could get broken with enough sideways force.  In any case, I think we have room to move the existing connector over a little.  Thanks for your comment!

macphyter, 2023-12-19:
I moved the USB-C connector away from the ESP32 as much as I could.  I think we should be good now.

macphyter, 2023-12-19:
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

Closed 2024-02-04.

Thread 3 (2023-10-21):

Extender Voltage Range

Mairex2000, 2023-10-21:
As this would be a perfect Rig for PV powered mining wouldn't it be a good idea to have a greater Voltage In Range so that it could be powered from a 24 Volt Solar System? In this system you would have lower amps and it would have a better overall performance.

skot, 2023-10-21:
That seems like a good idea to me; do you have a buck regulator in mind that can do this? We need an adjustable 4.5V output.

Mairex2000, 2023-10-22:
To be honest: No, but I think it could be worth thinking about an PV moppt tracker instead.

macphyter, 2023-12-17:
This is a cool idea... but the vast majority of users will be plugging this into a wall socket.  It also complicates the fan supply voltage, which use 12V now.  Lets put this on the back burner for now, and once things are working maybe consider doing a special "solar version"?

macphyter, 2024-06-06:
No plans for extended voltage range at this time.

Closed 2024-06-06.

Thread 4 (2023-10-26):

3d model

jeca32, 2023-10-26:
is it possible to add the 3d model of the PCB assembled with all these components in order to draw (step) the box with the cooling circuit?

jeca32, 2023-11-01:
the 3d model can be manufactured directly with KiCad

Closed 2023-11-01.

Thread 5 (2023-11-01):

Heatsink hole spacing

jeca32, 2023-11-01:
can we spread the mounting holes of the PCB Heatsink  from 60.5 mm to 59,5 mm. there is a high risk of breaking the drill bit when drilling.
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

macphyter, 2023-12-17:
The CAD model of the heatsink is not a perfect representation of the fin spacing, so those holes may or may not end up between fins.  In any case, the holes should not be drilled that deep.  Just enough to tap some threads in the base.

Closed 2024-02-04.

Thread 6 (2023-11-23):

U1 footprint is missing a pin

skot, 2023-11-23:

macphyter, 2023-12-17:
Not applicable to us now that we have changed the 5V regulator to a buck.

Closed 2023-12-17.

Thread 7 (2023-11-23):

C20-22 are the wrong footprint

skot, 2023-11-23:
footprint is 1206, part is 0805

macphyter, 2023-12-17:
Not applicable now since the entire regulator circuit has been changed.

Closed 2023-12-17.

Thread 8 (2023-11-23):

C15 is wrong part size

skot, 2023-11-23:
C15 part is 0402 and should be 0805.

it should also be a little higher voltage. BP is 6V and the part is rated for 10V

macphyter, 2023-12-17:
Not applicable since the entire regulator circuit has changed.

Closed 2023-12-17.

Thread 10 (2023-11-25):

core voltage is too high for ESP32 ADC measurement

skot, 2023-11-25:
The ESP32 measures the ASIC core voltage (TPS40305 output) via an ADC pin. 4.5V is too high to measure directly. put a voltage divider in there.

macphyter, 2023-12-17:
I changed this input to a voltage divider, and I used two 10K resistors as placeholders until I could go figure out the real values.  Looks like I forgot to set the new values.  Keeping this issue open until I do that.

skot, 2023-12-18:
How about 100k and 226k for a 0.7 voltage divider? this makes VDD_SAMPLE = 2.5V for VDD = 3.6V and VDD_SAMPLE = 3.12V for VDD = 4.5V

macphyter, 2023-12-19:
I chose 69.8K and 182K just because we are already using those values and we wouldn't have to add any unique parts to the BOM.  This gives us VDD_SAMPLE = 2.6V for VDD = 3.6V, and VDD_SAMPLE = 3.25V for VDD = 4.5V.
In any case, its a simple resistor swap to change this.

Closed 2024-03-14.

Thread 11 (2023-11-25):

change nominal TPS40305 output to 3.6V

skot, 2023-11-25:
the BM1366 wants 1.2V core voltage. for 3 in series this should be 3.6V.

the easy way to do this is change R10 from 1.54k -> 2k in the TPS40305 feedback circuit

macphyter, 2023-12-17:
The new voltage regulator has been designed with a nominal output of 3.6V.

Closed 2023-12-17.

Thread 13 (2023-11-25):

change PN for power connector to one that includes screws.

skot, 2023-11-25:
they even make cool colored screws;

[datasheet](https://mm.digikey.com/Volume0/opasdata/d220001/medias/docus/581/Metric_PCB_Screw_Terminals.pdf)

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

macphyter, 2023-12-19:
I changed the part number to the 7771 part with the non-colored screw.  The colored screws are harder to find.

Closed 2024-03-14.

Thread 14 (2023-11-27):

C8 needs higher voltage rating

skot, 2023-11-27:
it's currently rated for 16V, which is very close to the nominal 12V and no good for 20V..

macphyter, 2023-12-17:
Our core voltage regulator circuit has changed, this is no longer applicable.

Closed 2023-12-17.

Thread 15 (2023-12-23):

Fan PWM may need a 5V pullup

macphyter, 2023-12-23:
Some fans require a 5V pullup on the PWM signal.  Probably change layout to allow a 3.3V and/or 5V pullup... or maybe just a 5V pullup.  Need to look into it.

macphyter, 2024-03-14:
5V pullup is in use now.

Closed 2024-03-14.

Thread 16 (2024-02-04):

Fan connector interferes with OLED

macphyter, 2024-02-04:
The fan connector is blocking the OLED display, preventing it from sitting flush.

macphyter, 2024-03-14:
Moved the fan connector so it doesn't collide with the OLED.  Fixed in v303.

Closed 2024-03-14.

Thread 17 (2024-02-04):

Provide 3.3V to TPS546 for configuration

macphyter, 2024-02-04:
The TPS546 regulator will run on 3.3V without trying to start regulation.  This mode is used for configuring the registers in the chip.  If we route 3.3V over to AVIN on the TPS546, then we can use USB only to power up boards to flash the ESP32, and then reboot to allow the ESP32 to configure the TPS546 registers before applying main 12V power.  Probably need a diode to prevent backfeed from the 12V rail.

macphyter, 2024-03-22:
Since we are removing the USB 5V supply and diode, this will no longer be possible.  Its not a big deal, the TPS546 can still be configured using main power.  Closing this issue.

Closed 2024-03-22.

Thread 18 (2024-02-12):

Need diode on 5V regulator output

macphyter, 2024-02-12:
When USB is plugged in without the main power supply attached, 5V gets fed back through the 5V regulator to VIN.  This results in the 12V fans being powered by the USB 5V.  The 5V regulator should have a diode after the output caps to prevent this.

benjamin-wilson, 2024-02-12:
On the 205 we just removed the USB power, it also removes a part.

macphyter, 2024-03-23:
Removed USB power.

Closed 2024-03-23.

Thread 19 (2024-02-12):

rackable version !

phil31, 2024-02-12:
Hi

i just discover your project and imagin already a rackable version ..
i mean a daughter board with 8 ASICS and PSU and a connector to chain several boards ..
we can design a "mother board" with a single ESP32, a TFT screen and something to share / buffer links with each daughter boards..
maybe an FPGA, with 8 UARTs inside and some fifo ..
or use 8 software UART in the ESP32 ..?

a watercooling system maybe a better option too.. avoid some noise !

what is the actual status of your design ?

regards
phil

warchiefmarkus, 2024-03-23:
Yes, just want to say the same, 6 chips on board - not enough ! We need the ability to add a few hundreds 😁 maybe via increasing size of pcb (maybe a few level  pcbs stack?) or via adding some type of connectors to main control pcb with esp32 and ability to connect additional pcbs with Asics to it

macphyter, 2024-03-24:
These are all great ideas, but they involve a new project, not for the Hex board.  There may be projects like this down the road.  If not, feel free to start your own, its fun!

phil31, 2024-03-24:
yes ! i started my fork project with a rackable architecture ..
work in progress, will keep you in touch when/if something materializes !

but anyway, this project is for fun... no profitability expected !

regards

Closed 2024-03-24.

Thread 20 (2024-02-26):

More heatsink mounting holes

benjamin-wilson, 2024-02-26:
More mounting holes are needed to prevent pcb bending and increase mounting pressure

macphyter, 2024-03-14:
Added a center column of 3 more heatsink mounting holes on v303.

Closed 2024-03-14.

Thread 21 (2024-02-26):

Add BAP to Hex

benjamin-wilson, 2024-02-26:
Add the Bitaxe Accessory Port to the Hex so it's cross compatible with the Bitaxe

macphyter, 2024-03-23:
Removed the old display connector and replaced it with the Bitaxe Accessory Port.

Closed 2024-03-23.

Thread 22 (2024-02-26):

SMD Buttons are too small

skot, 2024-02-26:
not very practical to press. Maybe something bigger like [TL3330AF260QG](https://www.digikey.com/en/products/detail/e-switch/TL3330AF260QG/1426836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)

macphyter, 2024-03-22:
The buttons mentioned by skot were too wide to fit in the available space.  However I found some SMD buttons that have a nice round actuator and are narrow enough for the location.
https://www.digikey.com/en/products/detail/e-switch/TL3340AF160QG/1885973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
I've removed the old buttons and added theses to the PCB layout.

Closed 2024-03-22.

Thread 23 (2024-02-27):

Add Efuse

benjamin-wilson, 2024-02-27:
For power monitoring and safety

macphyter, 2024-03-24:
This is not so easy to do, given the limited amount of space around the main power input.  We'll have to think about this one.

nguyentruong190, 2024-03-28:
It is not really necessary, if needed, a fuse can be used in series with the wire
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

macphyter, 2024-06-06:
It was decided that the eFuse is too much of a burden at this point, since the TPS core voltage regulator already has shutdown capability for overcurrent and overvoltage.

Closed 2024-06-06.

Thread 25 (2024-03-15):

ESP-Miner dev status

GTCLive, 2024-03-15:
Hi Skot. Way too remarkable to fit into accurate wordings about what I think of your project, and so I'll skip that part!

I'm going to press-on and go all-in this one. Getting ready to order the components so to rig a development board to follow along. Are we good to go on the tag:hex_v302 contribs or you advise us to wait until you've ironed it out more?

Power delivery stable on the v302? All good to go?

skot, 2024-03-15:
v302 works, but it requires a number of changes. You should probably wait for v303 (master branch) which is _almost_ ready.

If you want to discuss this more, please checkout the bitaxeHex channel on the OSMU discord: https://osmu.bitaxe.org

GTCLive, 2024-03-15:
I'll crack on ordeing the passives and other core parts, however will standby for the pcbfab part as per advice. Grateful for the quick reply, Skot. Catch you guys on DS.

Closed 2024-03-15.

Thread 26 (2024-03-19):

Replace DigiKey Tape & Reel part numbers with Cut Tape ones in BOM

sarog, 2024-03-19:
The current BOM references DigiKey part numbers for Tape & Reel (TR) packages with minimum order quantities of 10,000+. They can be easily substituted with the Cut Tape (CT) ones.

| Ref | Current | Substitute |
|---|---|---|
| R2, R4 | RMCF0402FT17K8TR-ND | RMCF0402FT17K8CT-ND |
| R5 | RMCF0402FT10K0TR-ND | RMCF0402FT10K0CT-ND |
| R6 | YAG3115TR-ND | YAG3115CT-ND |
| R10 | 311-26.1KLRTR-ND | 311-26.1KLRCT-ND |

macphyter, 2024-03-24:
Done!

Closed 2024-03-24.

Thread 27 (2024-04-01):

Document efficiency compared to other ASICs

brandonros, 2024-04-01:
I don't think this is fully accurate but I wonder if something like this could be added to the README to help users understand how this ranks compared to other ASICs:

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

The bitaxeHex actually seems super efficiency from a watts/terrahash perspective if it truly can hit 3.0TH/s on 50w power consumption at the wall.

I'm not sure if the $250 estiamte to build one is accurate with power supply.

My next question would be, if it really is $250 for 3.0 TH/s, what could be done to make it more efficent from a "cost input -> hash output" perspective? What would it take to support more then 6 BM1366 on a single board? Are there currently plans to support more?

skot, 2024-04-01:
There are several other factors to consider when calculating the total $/TH/s. For example, the Compac-F requires a separate controller. All of those big industrial miners require industrial power, and likely something to mitigate the heat and noise.

brandonros, 2024-04-01:
Worded another way: why did you pick 6 ASICs on the board instead of 12 for example? What constraints were you up against? Could the "total $/TH/s" be improved significantly by simply copy and pasting/upsizing the schematic? Obviously not I'm sure.

What does a schematic that can do 12, 24, 48, 96 look like? Just for fun obviously :D

Tyberyus, 2024-04-01:
When i was Reviewing the scematic i was wondering if it would be possible to put 10 bm1366 in series. If we run them at 1.2V each. Than we could get rid of the step down Part. At least for 12v Systems. But would need 7 times more lvl shifters and some kind of fixed 12v supply. Luckily there are a lot of 12V 10A modules out there.

macphyter, 2024-05-13:
> When i was Reviewing the scematic i was wondering if it would be possible to put 10 bm1366 in series. If we run them at 1.2V each. Than we could get rid of the step down Part. At least for 12v Systems. But would need 7 times more lvl shifters and some kind of fixed 12v supply. Luckily there are a lot of 12V 10A modules out there.

Came across your comment while scrubbing issues.  This approach has been considered, but we didn't go that route for 2 reasons:
1- This was the first open source board to run multiple ASICs, and ASICs are expensive.  We didn't want to jump right into a board with lots of ASICs right away until we got some more understanding around how to run multiple ASICs.
2- Most 12V supplies are not exactly 12.0V, they tend to be close by 5% or so.  This means we wouldn't have exactly 1.2V per domain.  Also, we like having some fine control over the core voltage to provide for overclocking and rate tuning.  With an external 12V supply we don't have an easy way to control the core voltage level.

Since the time the Hex was created, there have been other projects crop up that take several different approaches to core voltage supply.  Eventually there will be someone who tries this, and it might turn out to be very effective.

macphyter, 2024-06-09:
I don't see any immediate action items here, so I'm closing this issue.

Closed 2024-06-09.

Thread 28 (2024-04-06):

bitaxeHex-303-schematic.pdf missing

GTCLive, 2024-04-06:
Hey guys, received all the passives and other components for assembly (less the BM1366 ofc). I've noticed the 303 gerbers are avail, which is great as I can get a dev board fab'd to follow-up with this project, however its ref schematic is missing. Any chance to have that uploaded or emailed?

skot, 2024-04-07:
The latest is always available in KiCad..

Closed 2024-04-07.

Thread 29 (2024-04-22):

optimize voltage regulator input and output capacitors

skot, 2024-04-22:
From a Discord chat today, there are some things on the TPS546 input and output cap filter sections that could be improved.

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

Switch electrolytic caps to ceramic. This isn't super straight forward because there aren't direct ceramic replacements for the 180uF el caps.
- Try checking the OUTPUT_CAP_TYPE = ceramic option in Webench and see what they reccommend
- check out this PDF from K1, especially the bit about Antiresonance
[emi-murata.pdf](https://github.com/skot/bitaxeHex/files/15066768/emi-murata.pdf)
- LCSC has some [100uF 16V ceramic](https://www.lcsc.com/product-detail/Multilayer-Ceramic-Capacitors-MLCC-SMD-SMT_Chinocera-HGC1210R5107M160NSVK_C7432790.html) capacitors that could work?

macphyter, 2024-06-04:
Replaced 180 uF electrolytic capacitors with 2x 100 uF ceramic capacitors.  Rearranged some regulator caps to get them out from under the heatsink.  Selected new low-ESR caps all around.
Fixed in v304.

Closed 2024-06-04.

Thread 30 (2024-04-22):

Level shifter Opamp Vs is outside recommended operating range

skot, 2024-04-22:
The [TLV3544](https://www.ti.com/lit/ds/symlink/tlv3544.pdf) used as the cross-domain level shifter is powered by VDD and -VDD which is most cases is 2.4V. The TLV3544 says the min Vs is 2.5V. (Although max operating doesn't have a min).
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

pmaxuw recommends setting Vs to 5V. This should be checked against the datasheet and/or tested.

shufps, 2024-04-23:
OP should be powered with 5V and GND. Seems Nine9Seven already tested it and confirmed that the level shifting still works.

macphyter, 2024-05-24:
Fixed on schematic and layout on v304

Closed 2024-05-24.

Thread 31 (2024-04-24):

Use fixed LDOs and get rid of some resistors.

benjamin-wilson, 2024-04-24:
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

macphyter, 2024-05-24:
Fixed on schematic and layout on v304

Closed 2024-05-24.

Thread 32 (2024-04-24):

Dedicated DC converter for each BM1366?

nikwest, 2024-04-24:
Sorry, that I use the issue tracker for this kind of generic question, but I don't know where else to put this.
I am about to build a bitaxeHex and was looking into more detail in the design and also other designs like the 0xaxe.
Everybody seems to go with a monolithic approach for providing power to all the ASICS from one source. But this doesn't seem to scale well to me. Wouldn't an approach to use a dedicated power of load regulator be more flexible and easier? Something like a 6A converter with programmable output (e.g. https://www.mouser.de/datasheet/2/1458/DS6203E_00-3104633.pdf). Costwise I don't think it makes a significant difference and it would open up the possibility to individually tune each BM1366 (not sure if that's possible at all though)?

dmillard-TD, 2024-04-29:
@nikwest Why do you think this approach doesn't scale well?  Using a dedicated DC converter for each BM1366 sounds like a nightmare to scale up.  Also, this approach follows the Bitmain design which puts 70-100 ASICs on each hashboard, that seems like it scales pretty well to me.
The hex is one of the first open source multi ASIC boards to be created, its just a starting point.  There are improvements coming in the future.

nikwest, 2024-05-03:
never mind. I guess you've been through all of that thinking before ;-)
Anyways the referenced part probably has to less Amperage anyways.

Closed 2024-05-03.

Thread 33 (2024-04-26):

update BM1366 footprint with latest from bitaxe v206 library

skot, 2024-04-26:

macphyter, 2024-05-25:
@skot I don't see a v206 in the git repo for bitaxe.  Am I missing something?

macphyter, 2024-05-31:
BM1366 footprint updated to version from Ultra 206.
Fixed on Hex v304

Closed 2024-05-31.

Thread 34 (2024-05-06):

Change the silkscreen for L1 and L2 by considering the "start of winding"

aaron3481, 2024-05-06:
Pro tips from the doc said L1 and L2 should consider the EMI issue. i.e. the "start of winding" end should attach closer to the switch node.

macphyter, 2024-05-31:
Fixed on Hex v304

Closed 2024-05-31.

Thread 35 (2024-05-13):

Change temperature sensors to a larger package

macphyter, 2024-05-13:
Some people have trouble soldering the tiny footprint of the temperature sensor.  Change the temperature sensor to this part:
https://www.digikey.com/en/products/detail/texas-instruments/TMP1075DGKR/9692553
It's the same part, but a larger footprint.  The software drivers can stay the same, no changes, and the larger footprint will be easier to solder.

macphyter, 2024-05-31:
Fixed on Hex v304

Closed 2024-05-31.

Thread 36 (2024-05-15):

Add voltage sensing to each domain in order to check voltage balance

macphyter, 2024-05-15:
Add a voltage divider on each domain core voltage, and feed it back into the ESP32 so the firmware can measure the domain voltage balance and report it to the GUI.

macphyter, 2024-05-25:
This has been added on the schematic and layout for v304

Closed 2024-05-25.

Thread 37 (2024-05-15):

Reset signals connected in parallel instead of series

macphyter, 2024-05-15:
As suggested on the Discord channel, perhaps we should connect the ASIC reset signal to each ASIC individually within the voltage domain instead of passing it through the ASIC chain.  This should avoid any delays on the reset and have all the ASICs come out of reset at the same time.

macphyter, 2024-05-25:
I eliminated all the RESET signal passthroughs on all the ASICs by connecting the signal in parallel within the domains, and directly through the level translators.  The RESET signal should get propagated to all ASICs at once now.
Fixed on Hex v304.

macphyter, 2024-05-25:
This change was reverted back to the serial passthrough reset signals.  After some discussion, it was decided that the serial passthrough reset works just fine, and there's no reason to change it.  There may even be a good reason that Bitmain uses this scheme, besides layout convenience.  In any case, there's no need to introduce risk to the design.

Closed 2024-05-25.

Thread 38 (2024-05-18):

Change power input to XT30

macphyter, 2024-05-18:
Replace the screw terminals with a PCB mount XT30

macphyter, 2024-06-04:
Added XT30 for power input.
Fixed on v304.

Closed 2024-06-04.

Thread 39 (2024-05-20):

Add pullup resistors to the I2C signals

macphyter, 2024-05-20:
It appears that the I2C signals from the ESP32 might already have pullups, but they are extremely weak.  We should add our own pullups because the I2C signal goes across the entire board from end to end.  Also, the PMBus spec calls out stronger pullups.

macphyter, 2024-05-20:
Added to v304 schematic, still needs to be added to PCB layout.

macphyter, 2024-06-04:
Finished I2C pullup resistors on PCB layout
Fixed on v304

Closed 2024-06-04.

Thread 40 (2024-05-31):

Draw voltage domain boundaries on silkscreen

macphyter, 2024-05-31:
It would aid hardware debugging if the voltage domain boundaries were shown on the silkscreen. Also point to important test points.

macphyter, 2024-06-06:
Added clearly marked testpoints for domain power and clocks.
Fixed in v304

Closed 2024-06-06.

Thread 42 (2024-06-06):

ADC inputs for domain voltage sense need dividers

macphyter, 2024-06-06:
The domain voltage sense line on the top domain could go as high as 3.6V or higher.  Need to add resistor dividers to the domain voltage sense to keep them in the range of the ESP32 ADC inputs.

macphyter, 2024-06-09:
Added resistor dividers to domain voltage sense signals to both schematic and PCB layout.
Fixed on v304.

Closed 2024-06-09.

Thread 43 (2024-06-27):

unrouted tracks on board

chenyang2151, 2024-06-27:
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

chenyang2151, 2024-06-27:
U15 /vdd1 have hole
![Uploading 屏幕截图 2024-06-27 081106.png…]()

chenyang2151, 2024-06-27:
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

chenyang2151, 2024-06-27:
U15 /vdd1 have hole

skot, 2024-06-30:
Another airwire 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

chenyang2151, 2024-07-01:
hex use espminer 2.1.9 direct？ what is named broad version ？

macphyter, 2024-07-02:
This is very strange.  Those missing connections don't show up on my KiCad DRC.  I don't know why.

macphyter, 2024-07-02:
Fixed.

chenyang2151, 2024-07-02:
the next table is not connects'

aaron3481, 2024-07-03:
same, my drc does not notice me too. we found this airwrie by eye T_X

chenyang2151, 2024-07-03:
is here
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

Closed 2024-07-02.

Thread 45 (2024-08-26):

CPL Files please

Dan-Rdd, 2024-08-26:
Hi any chance of adding the CPL files so we can just submit for assembly :)

skot, 2024-08-26:
No, these are PCB assembler specific.

Closed 2024-08-26.

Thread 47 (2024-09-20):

Heatsink mounting holes

IsaacFurlani, 2024-09-20:
There are currently no known processors with the mounting screw dimensions of 60x56mm.
This can make it difficult to find pre-existing solutions for temperature.

Some components on the gerber could be shuffled slightly to optimise for more common heatsink mounting dimensions.

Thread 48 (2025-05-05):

BOM list position 3 ceramic capacitor same as position 1 ? ? ?

andre301283, 2025-05-05:
planing for DIY HEX

why are the capacitors on position 3 not same as psotition 1 ? C34, C35, C38, C39, C40, C43, C44 are 0.1 uF as the other ones on position ... and the value in the list is missing.... instead there is  would be nice to find there... found out by the part number: KGM05AR71C104KH

Kondensator aus mehreren Keramikschichten MLCC - SMD/SMT 16V .1uF X7R 0402 10 %

this is confusing... is there something i´m gettin wrong?

by the way: do you think it´s possible to use the same curcuit board driving BM1397 instead of BM1366 ? i would try it... layout should be same.... in Antminer T17+ and S17 series the only difference on hasboard is a 33 ohm resistor between RO and RI .... layout is absolutely same... would it be possible by just configuring the cfg fimrware files?

thanks.... very thankfull for all this work !

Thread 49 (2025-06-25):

BM1366 mode versions

VoltMike, 2025-06-25:
Hello all,

what is the difference between the BM1366_mode0 and BM1366_mode1 ASICs in the BOM list?
The schematic shows completely diffrent pinouts for the both chip versions.

Is the difference in the difference given in the parts label AL and AG? If yes which one is mode_0 and mode_1?

Thx in advance.

BR
Mike

skot, 2025-06-25:
The PIN_MODE pin controls which signals are on which pins. It essentially controls which side of the chip the inputs and outputs are on. We have different schematic symbols for the two modes so that the pin names match up

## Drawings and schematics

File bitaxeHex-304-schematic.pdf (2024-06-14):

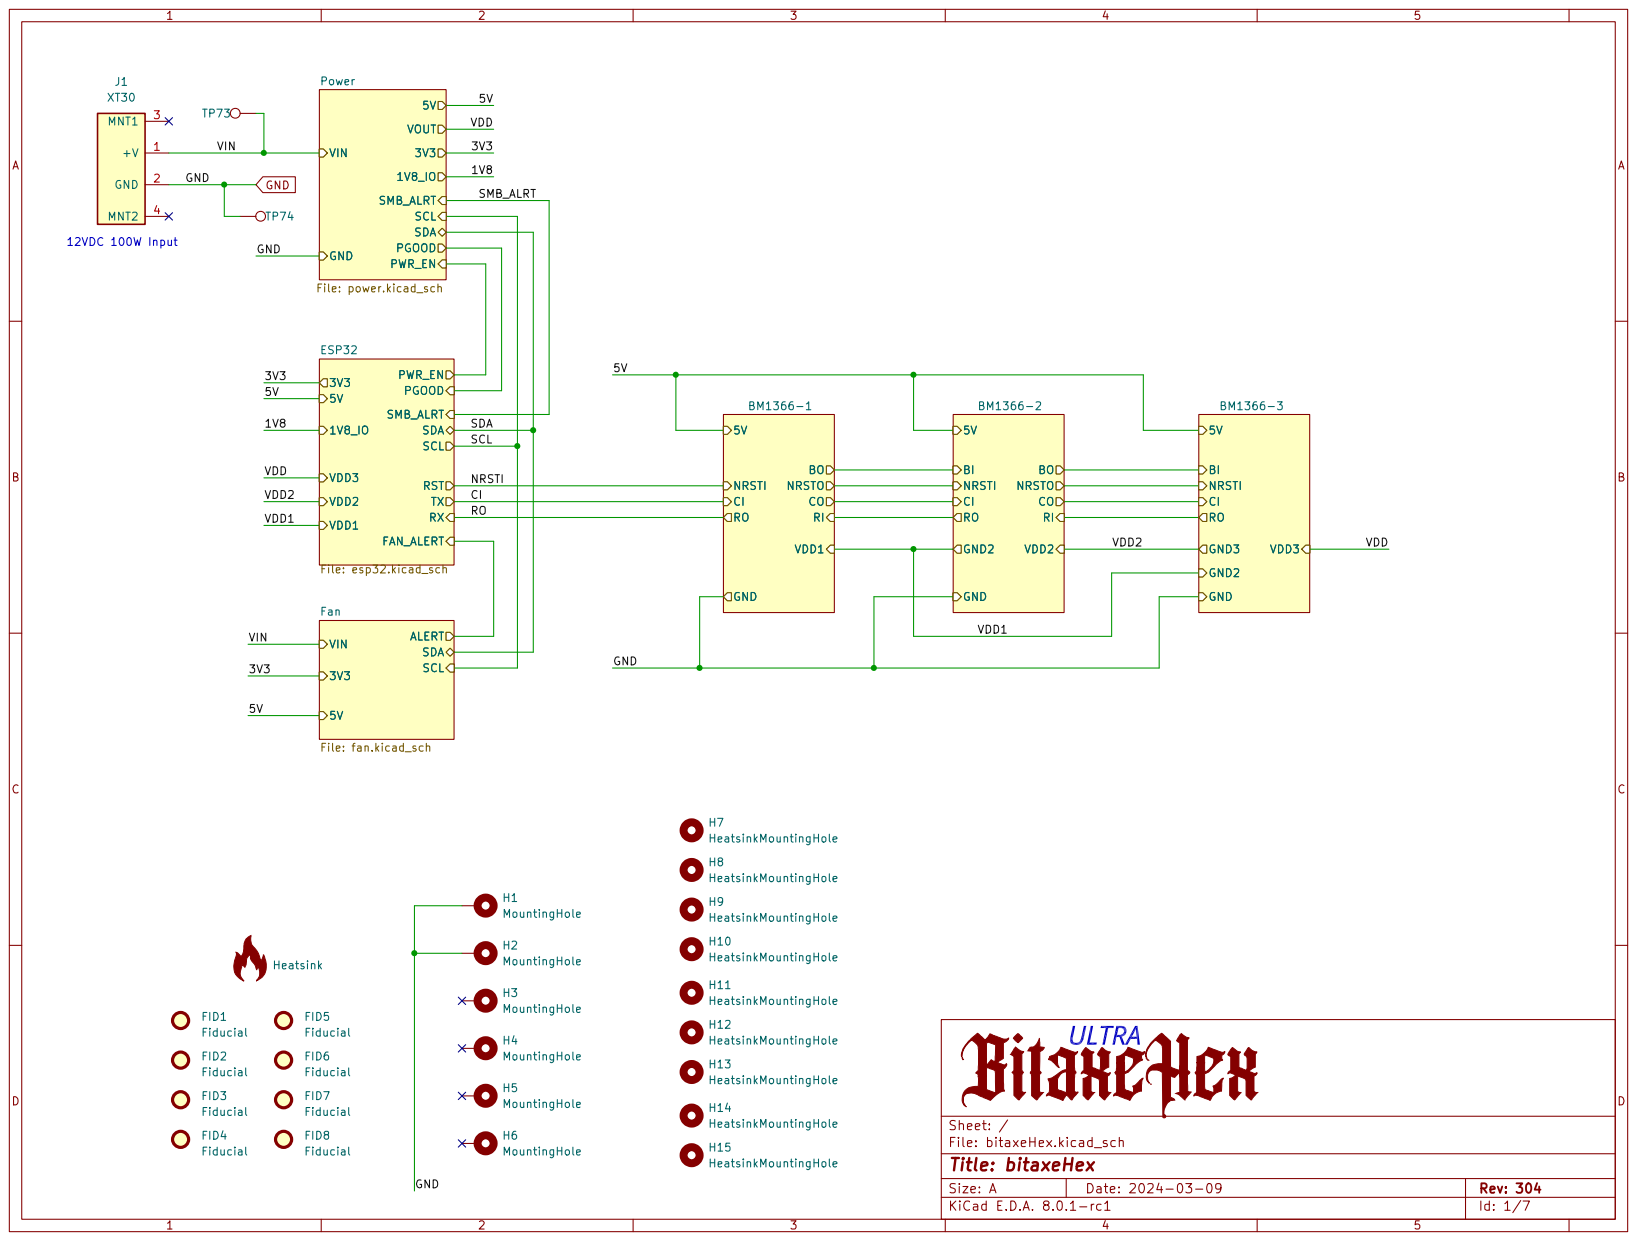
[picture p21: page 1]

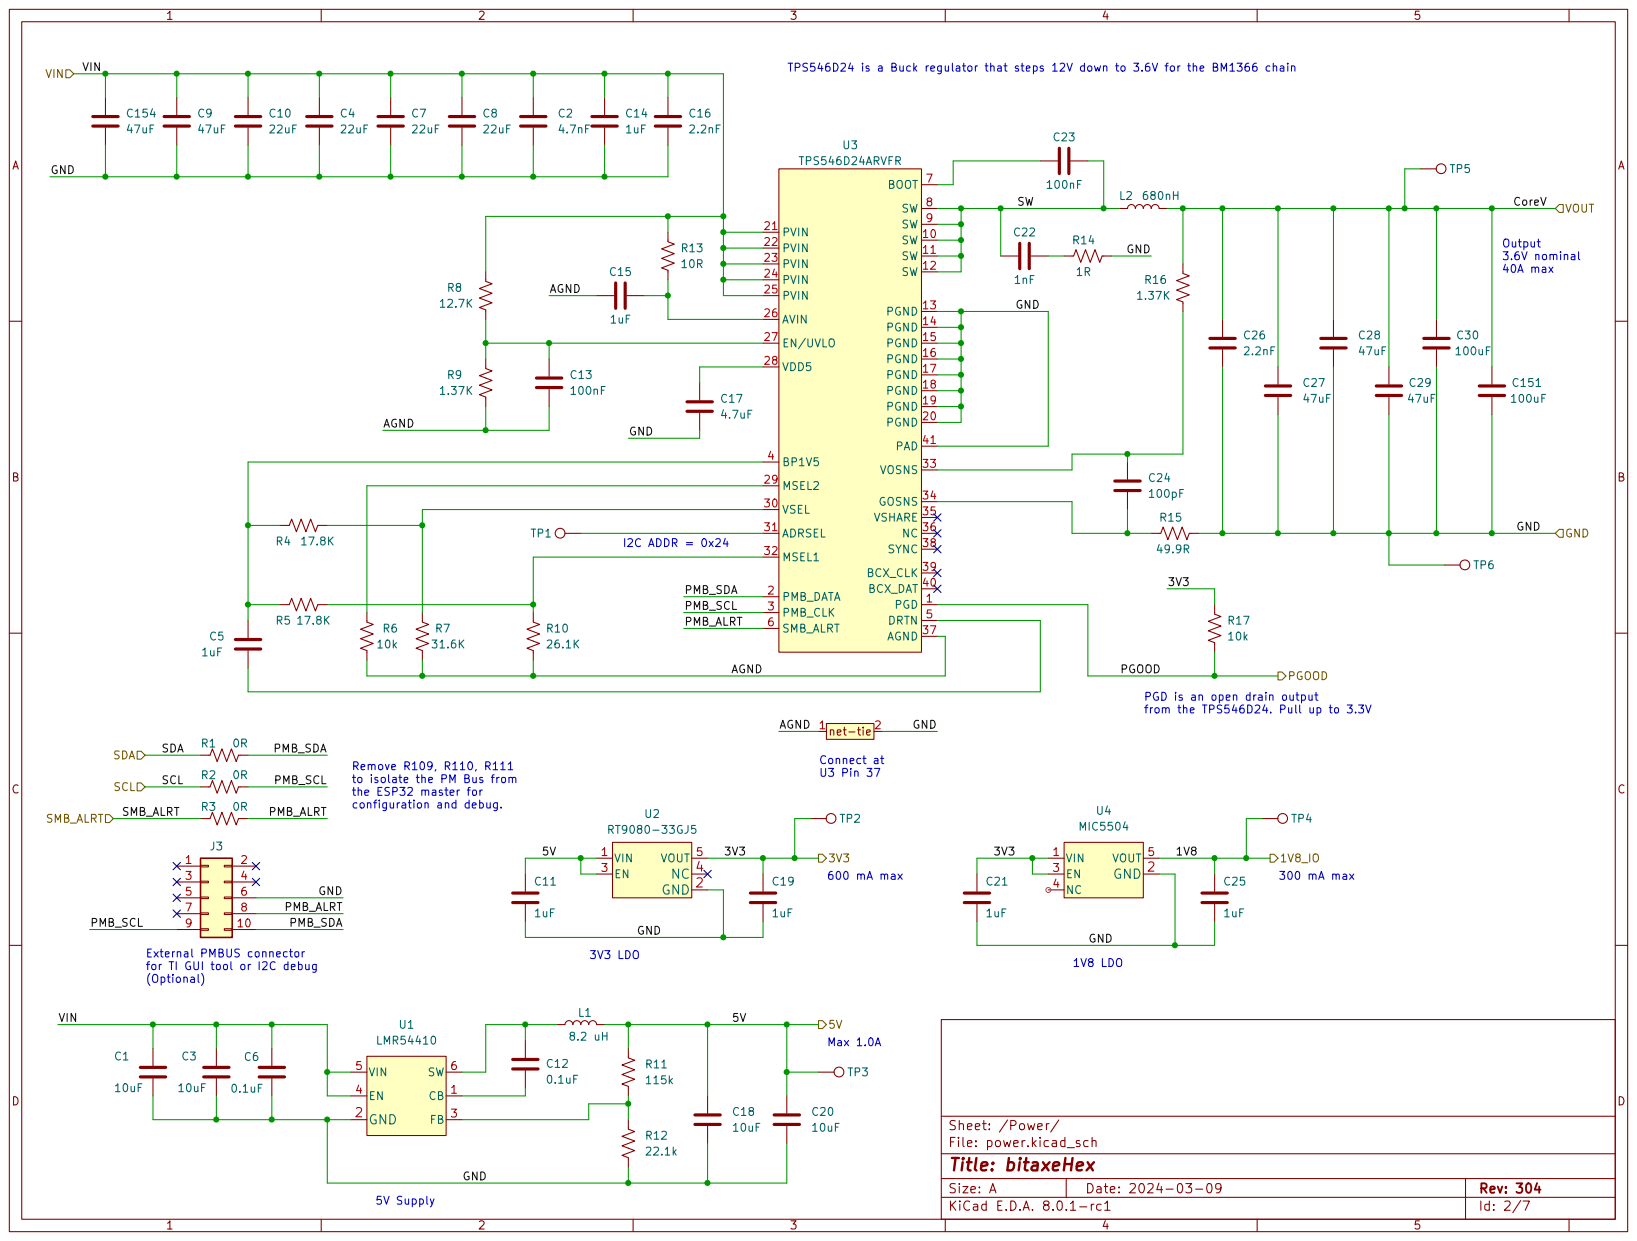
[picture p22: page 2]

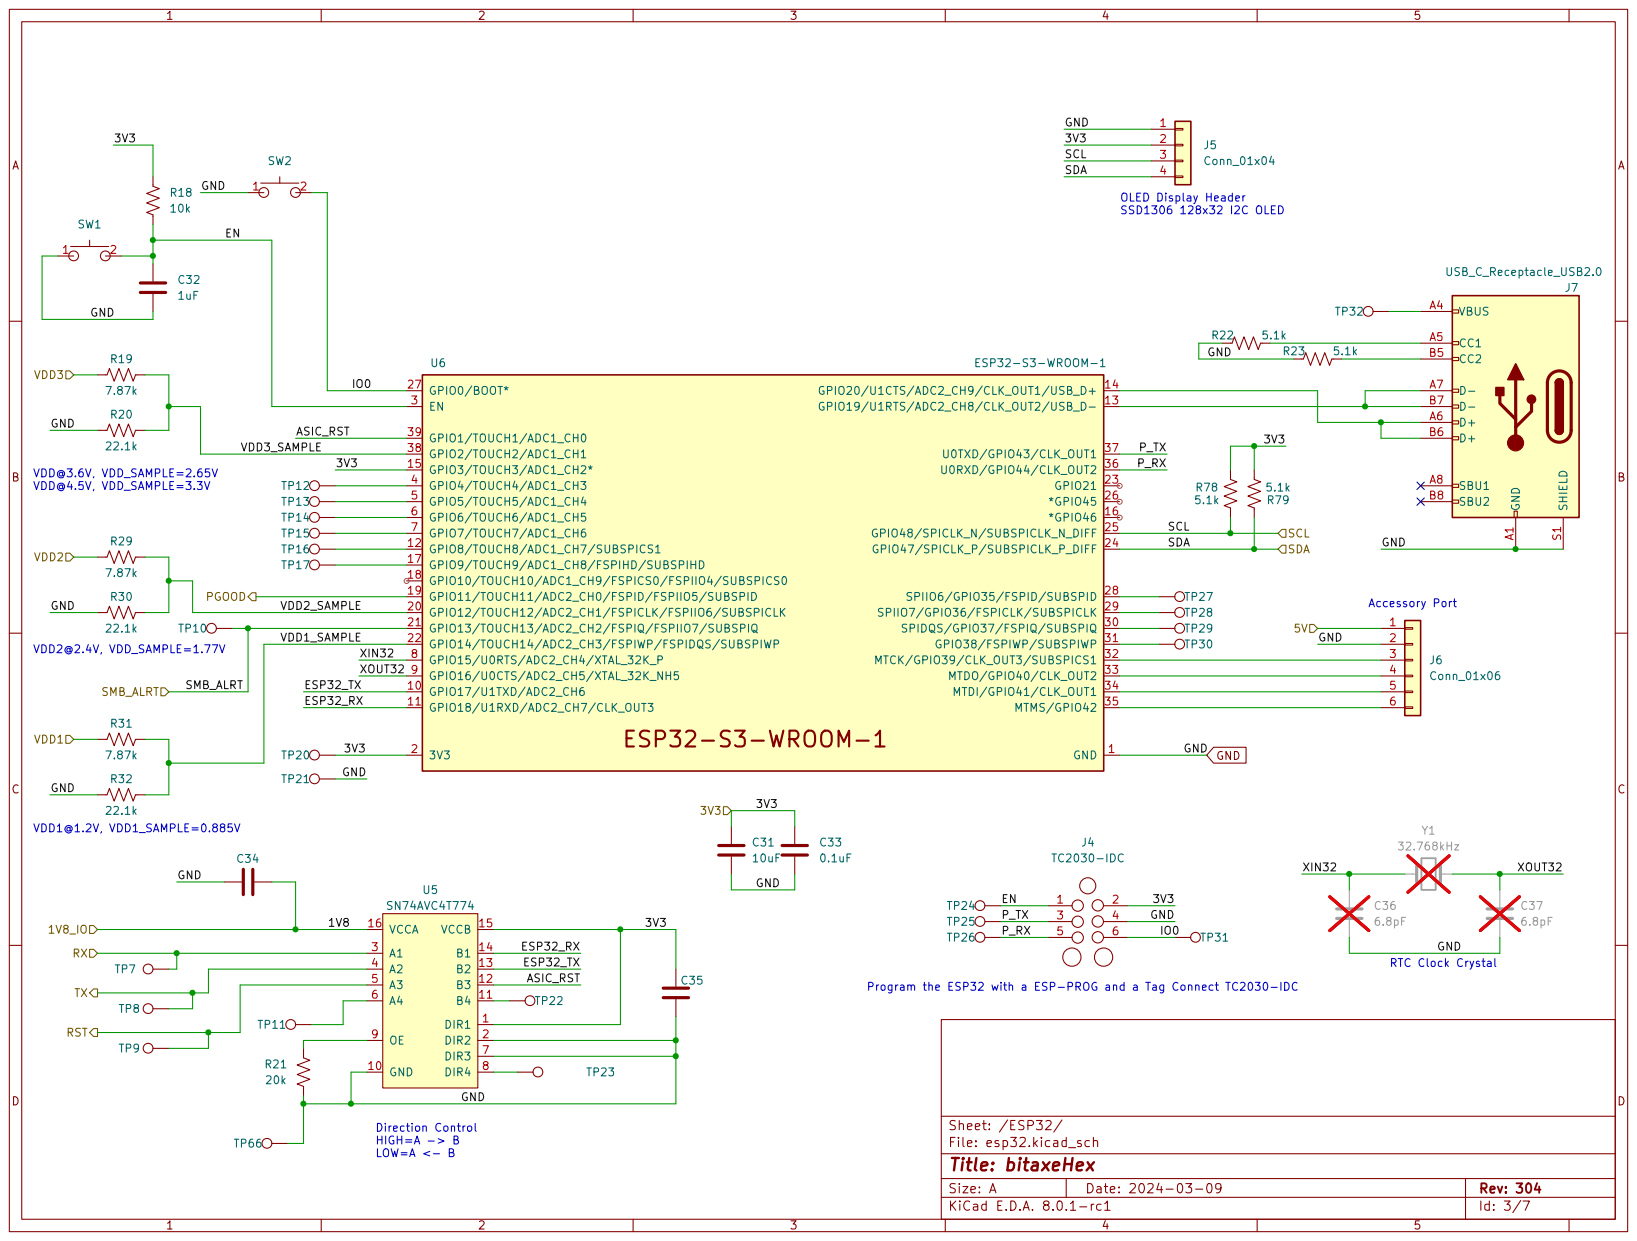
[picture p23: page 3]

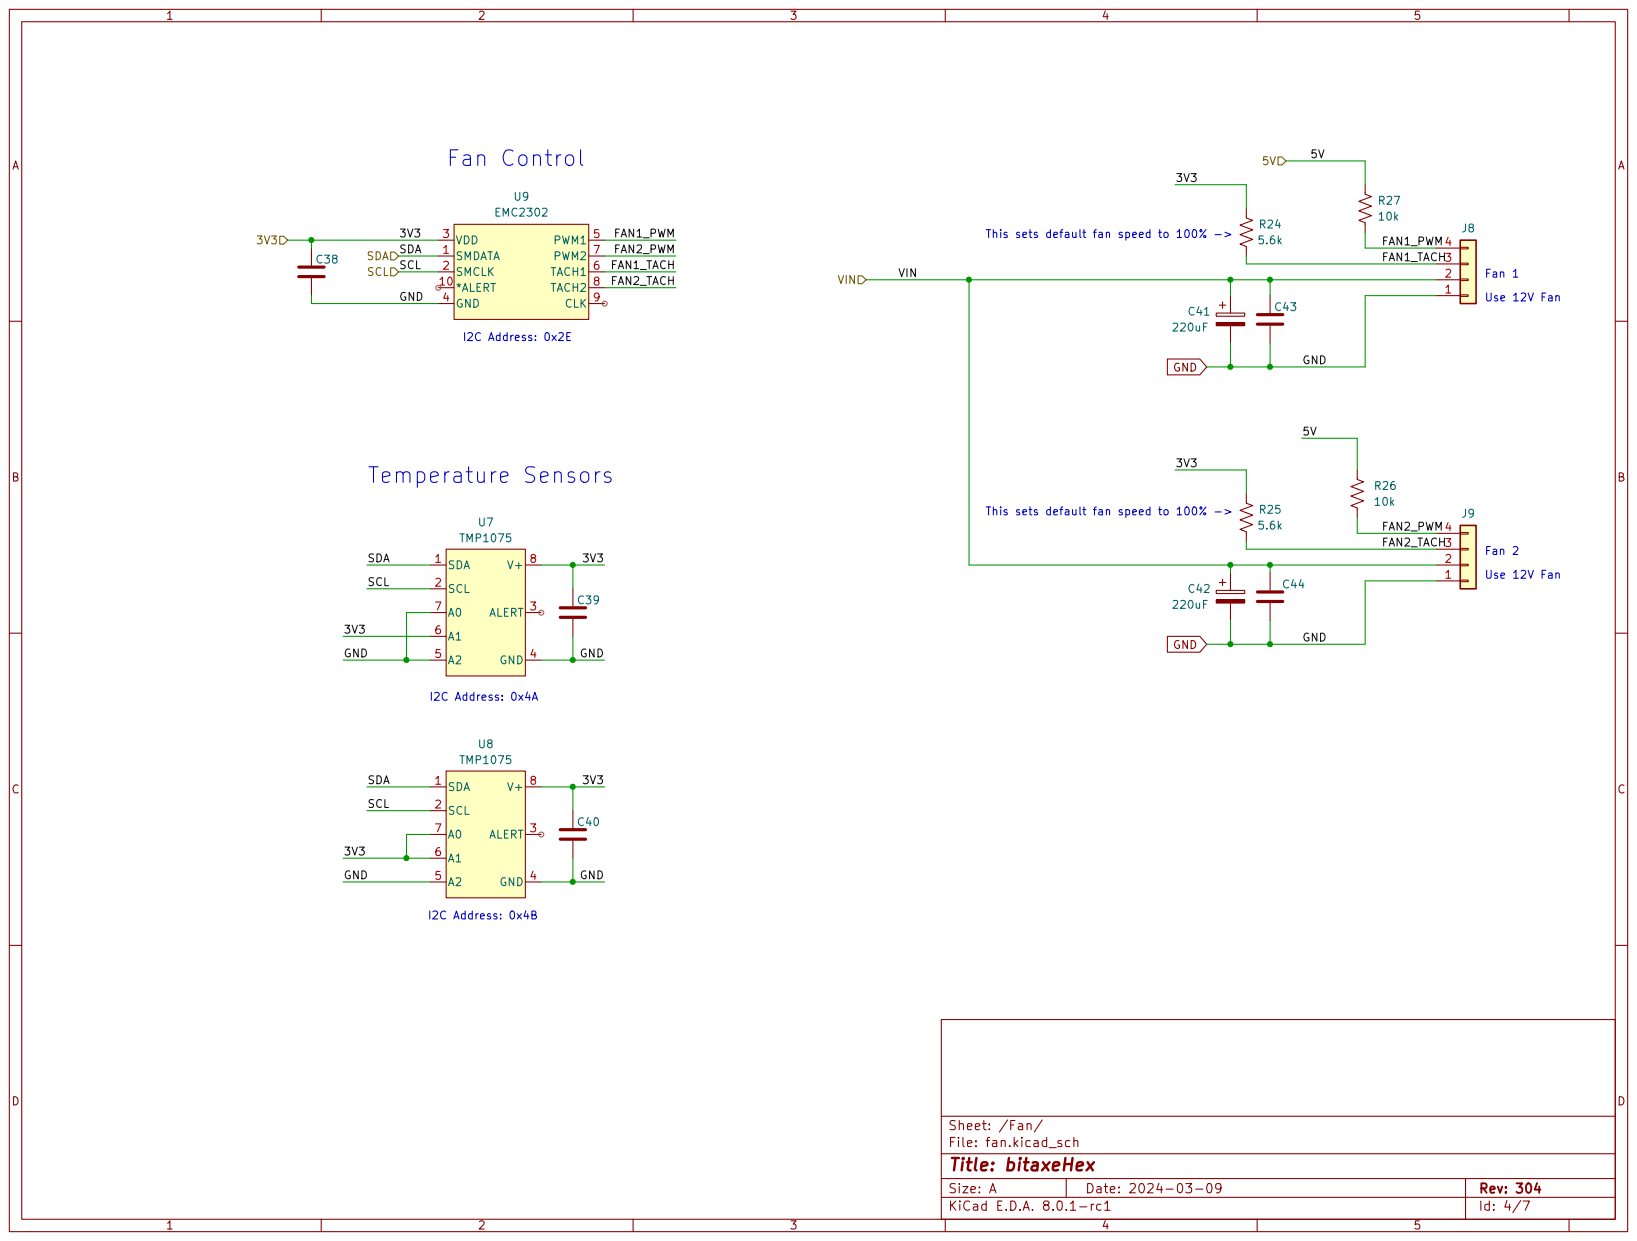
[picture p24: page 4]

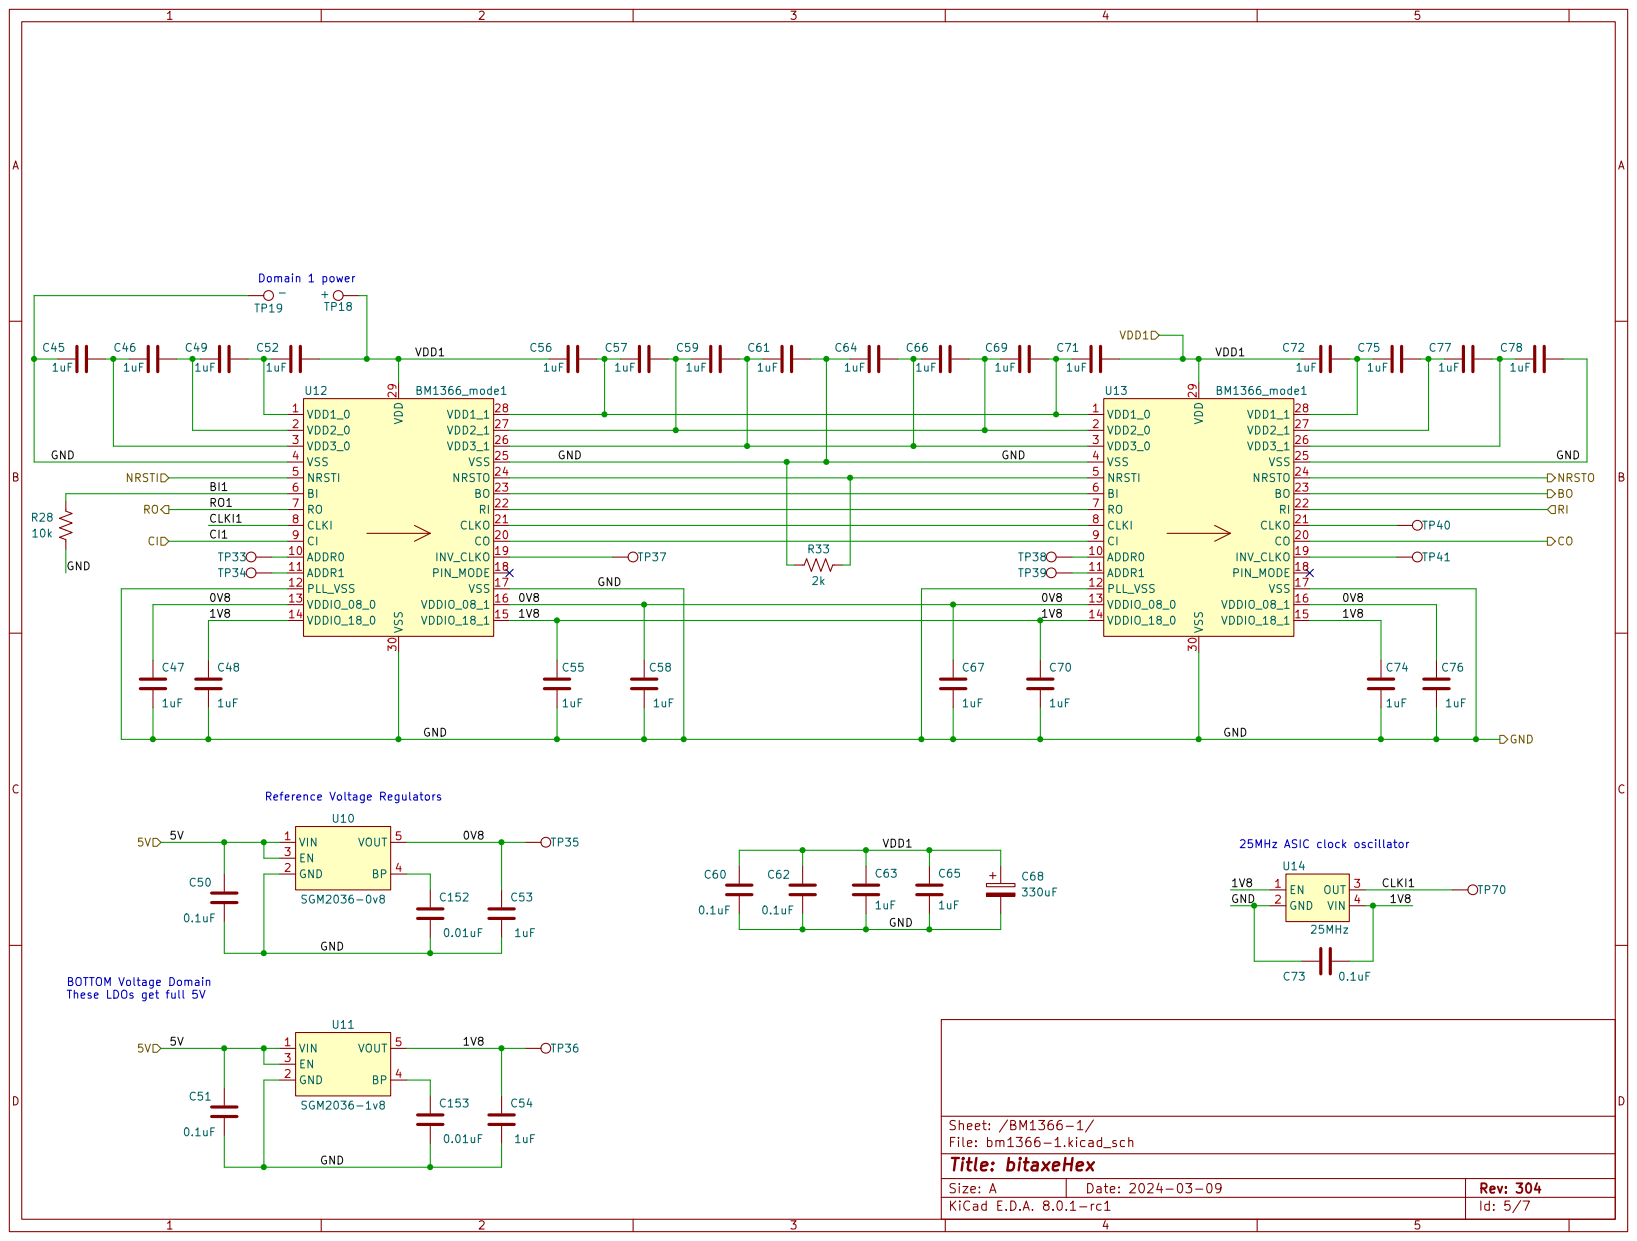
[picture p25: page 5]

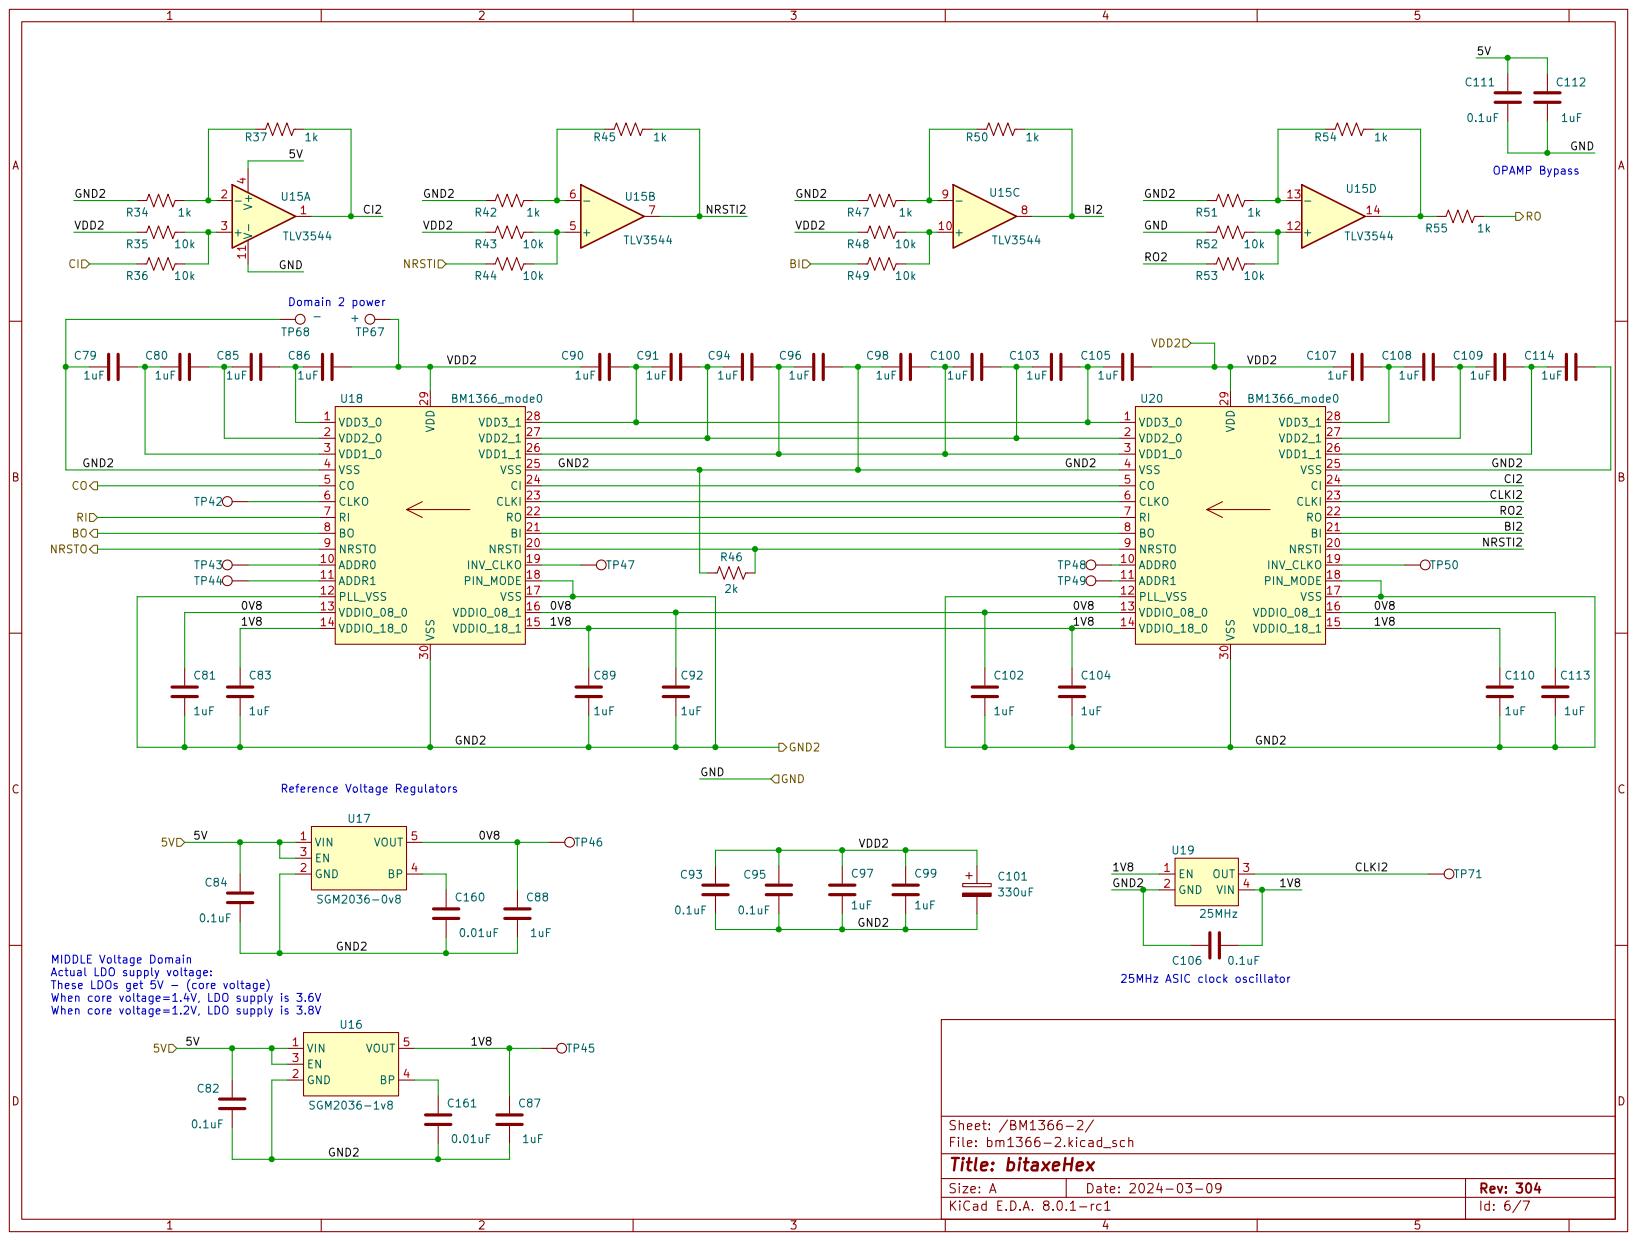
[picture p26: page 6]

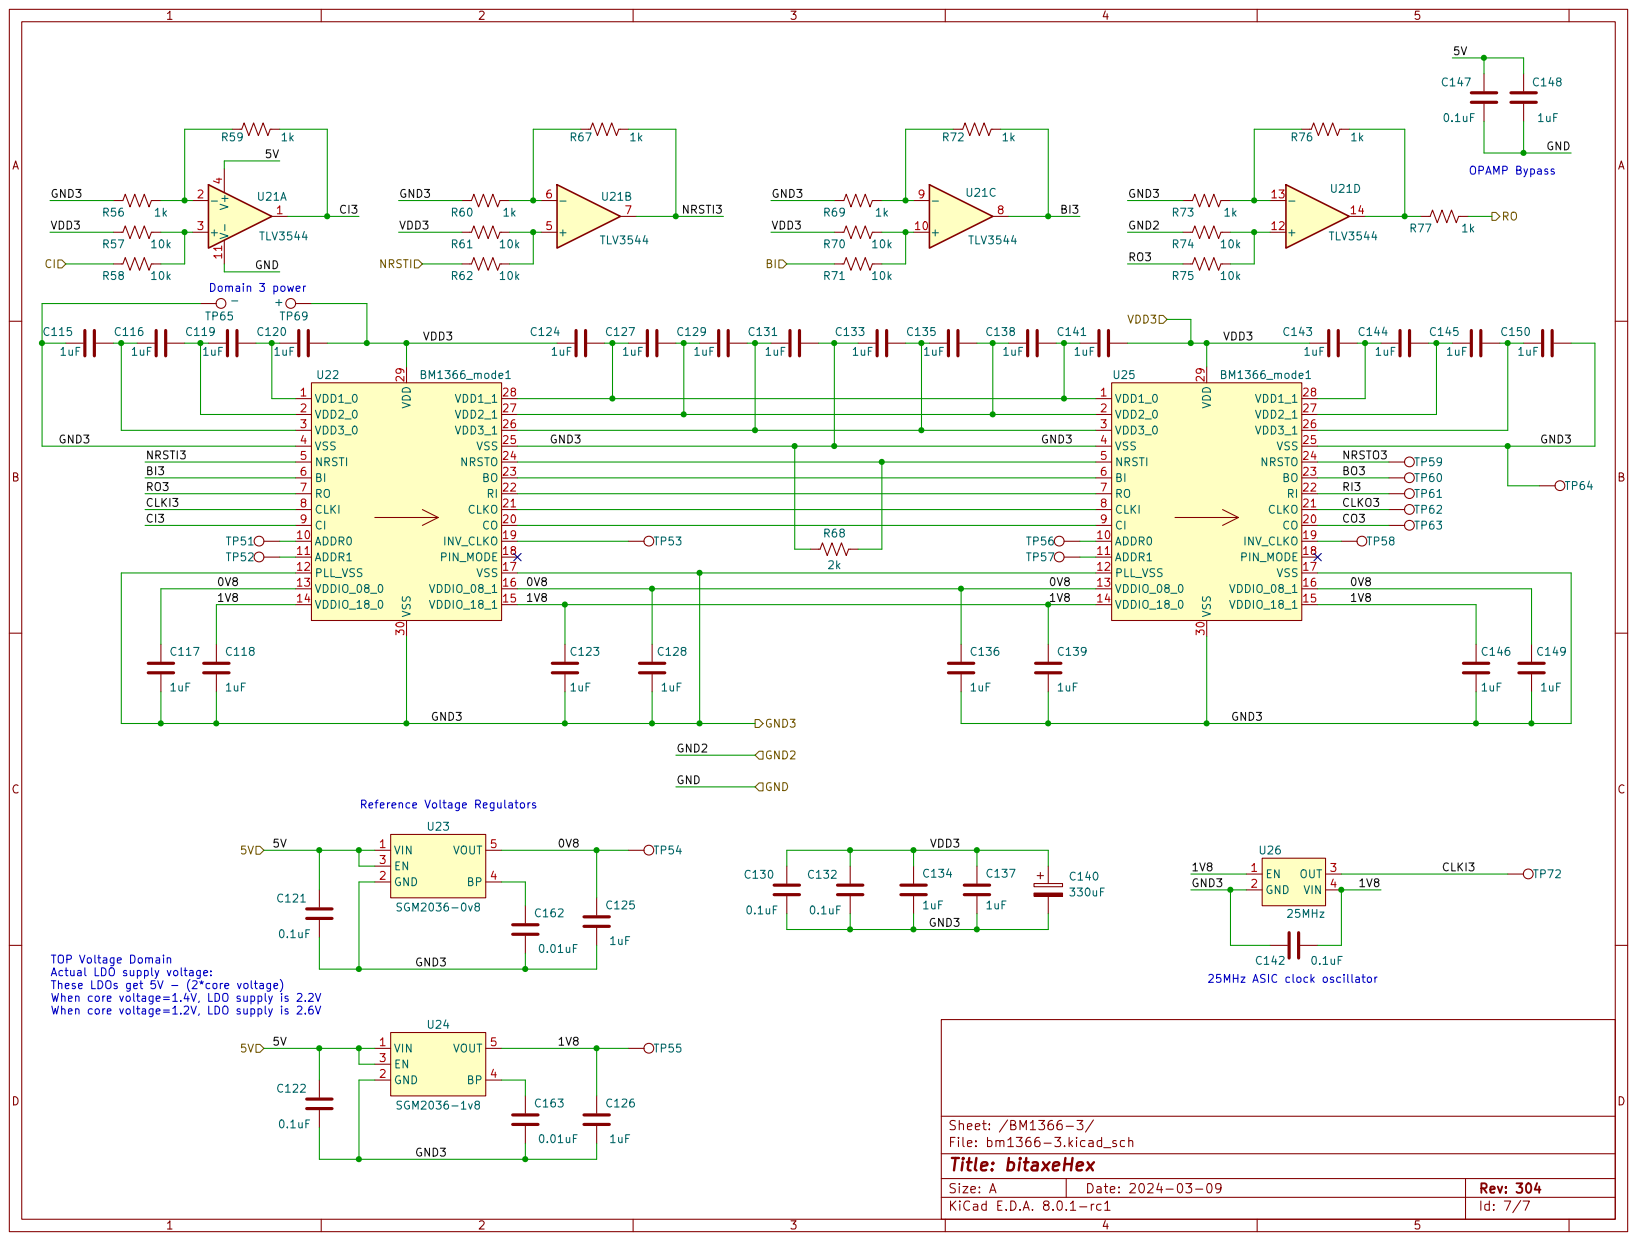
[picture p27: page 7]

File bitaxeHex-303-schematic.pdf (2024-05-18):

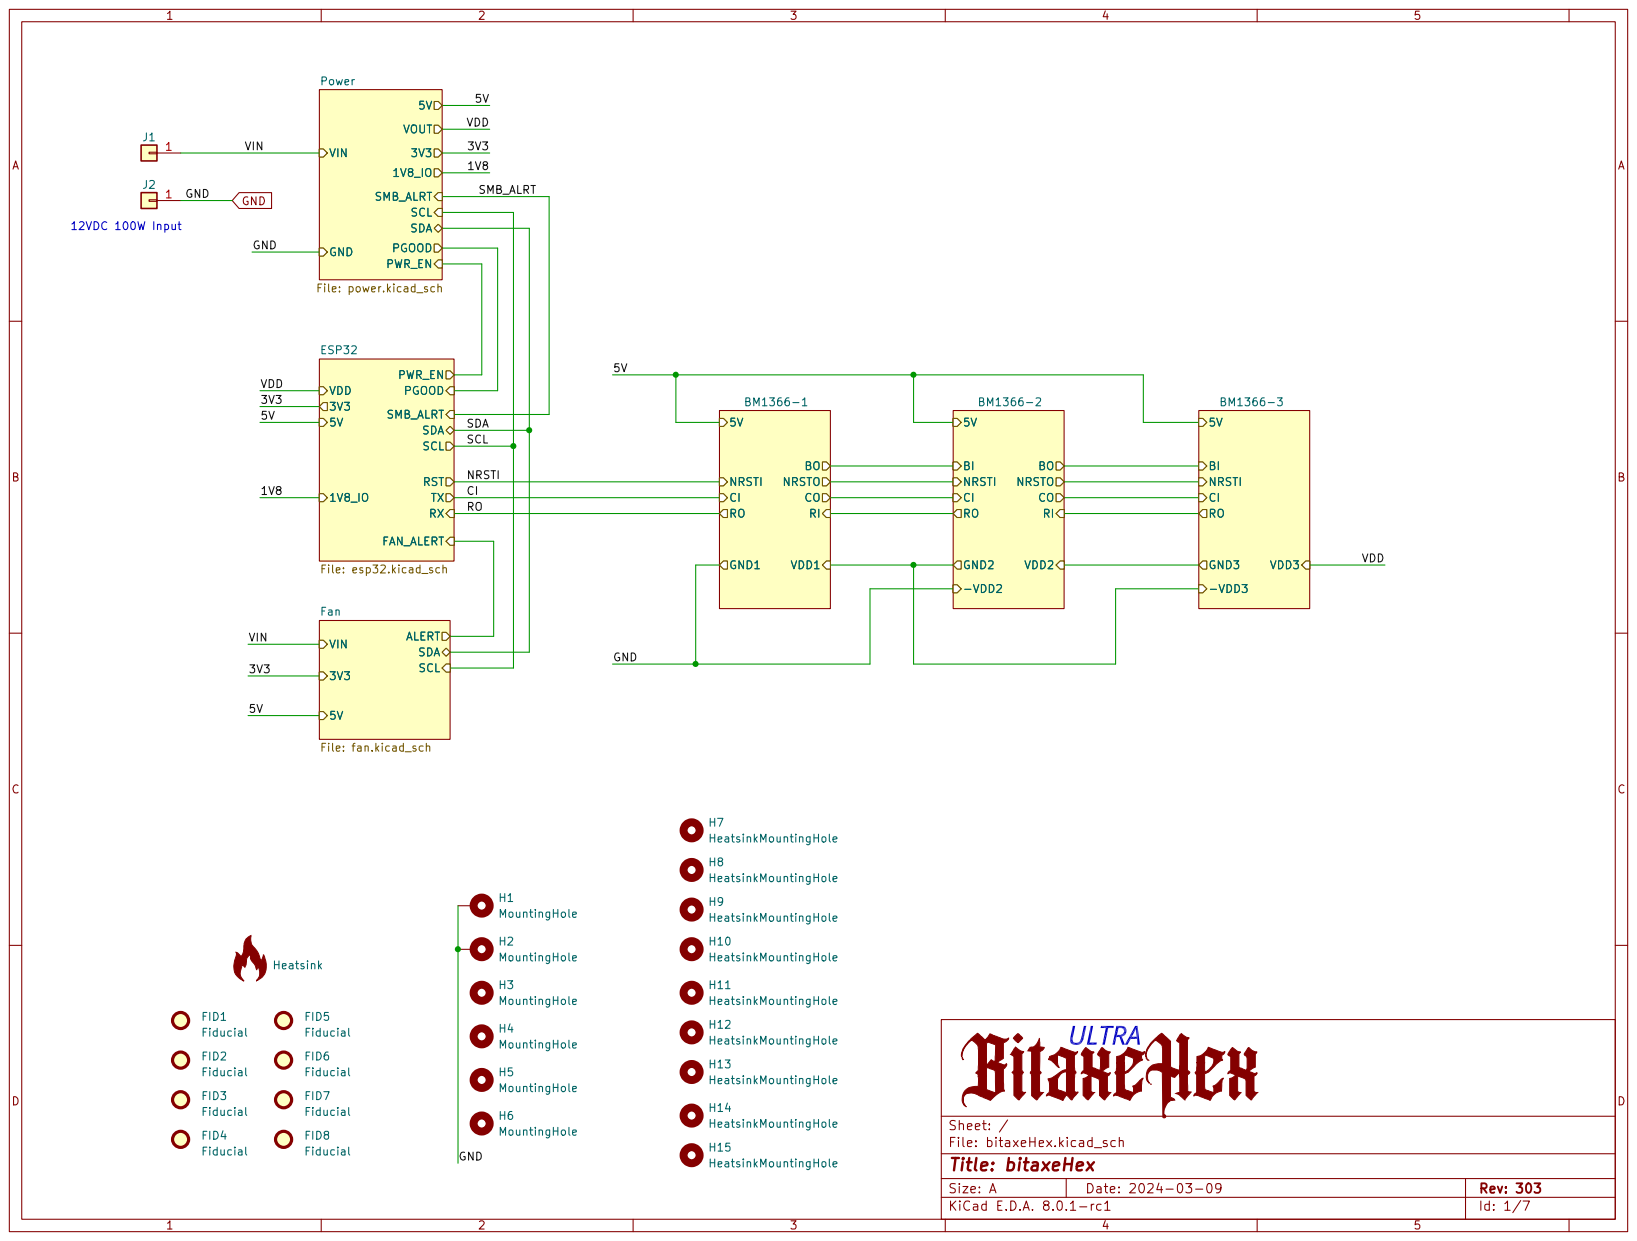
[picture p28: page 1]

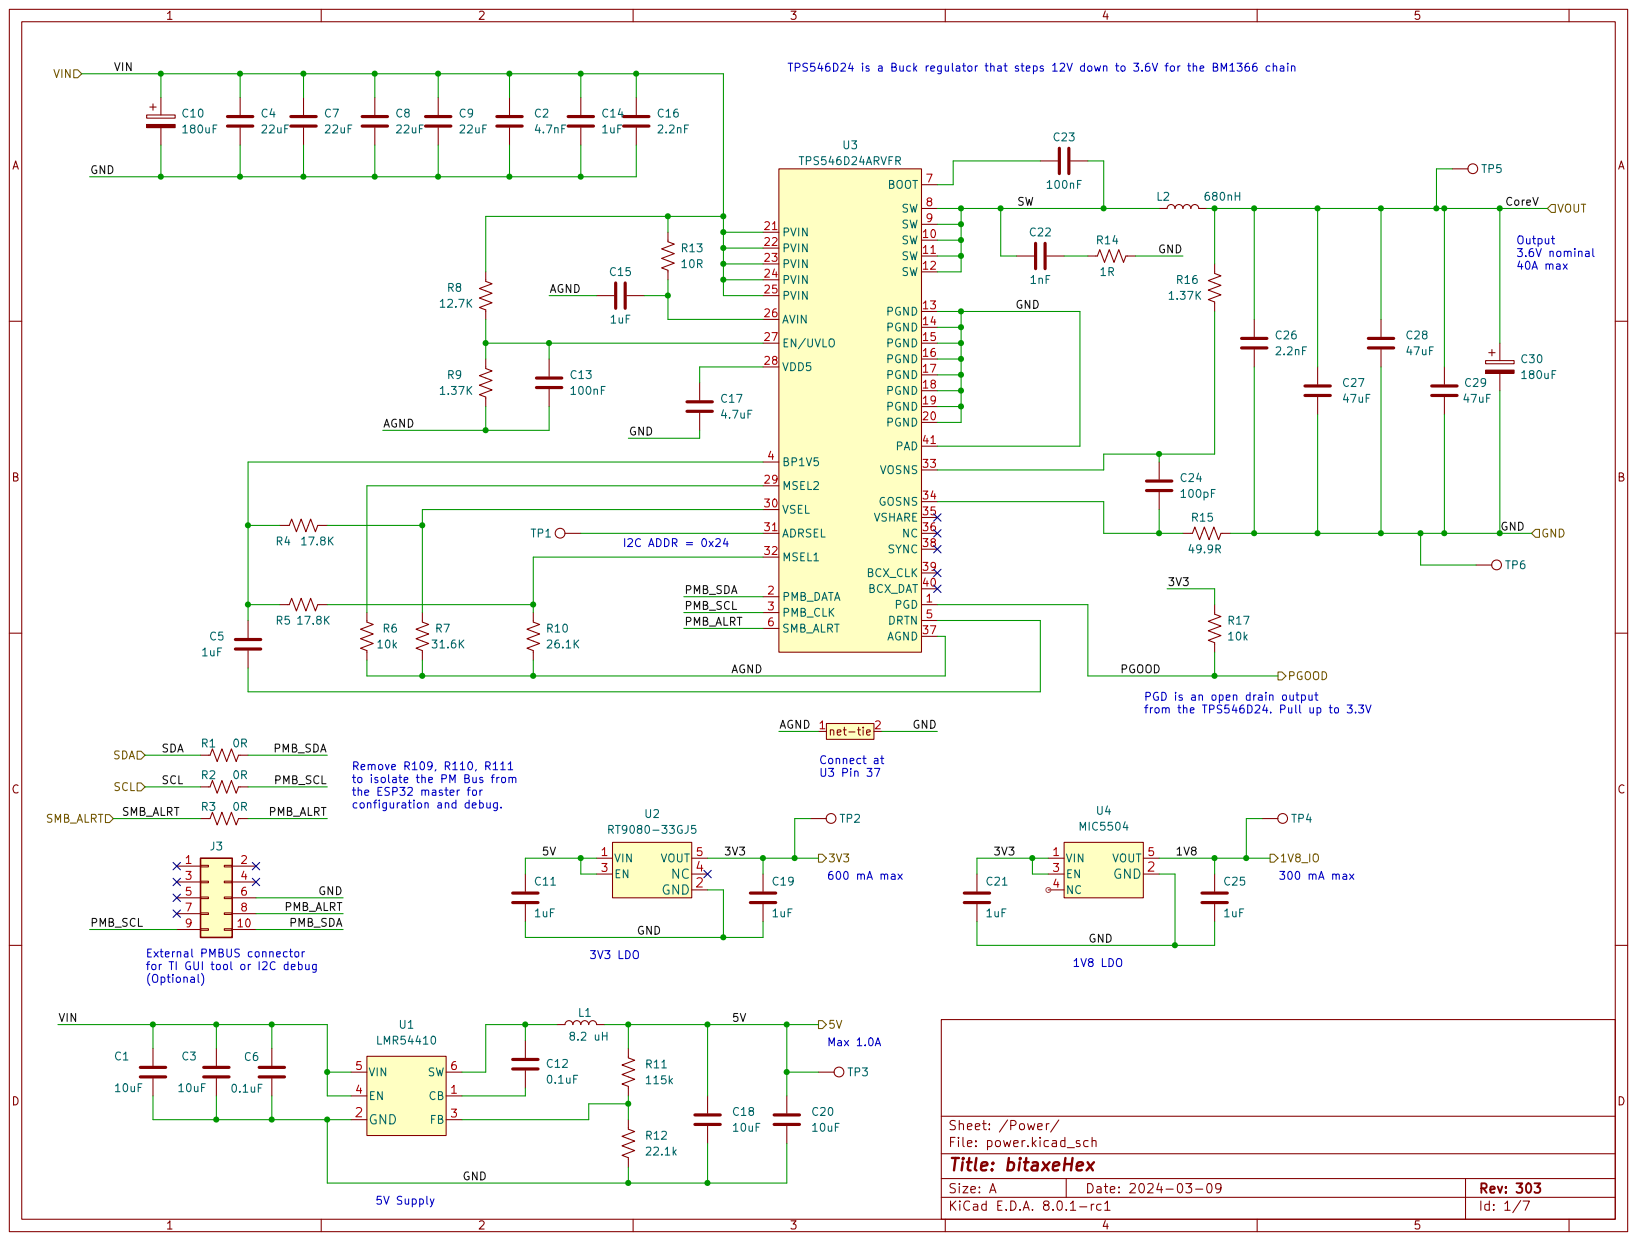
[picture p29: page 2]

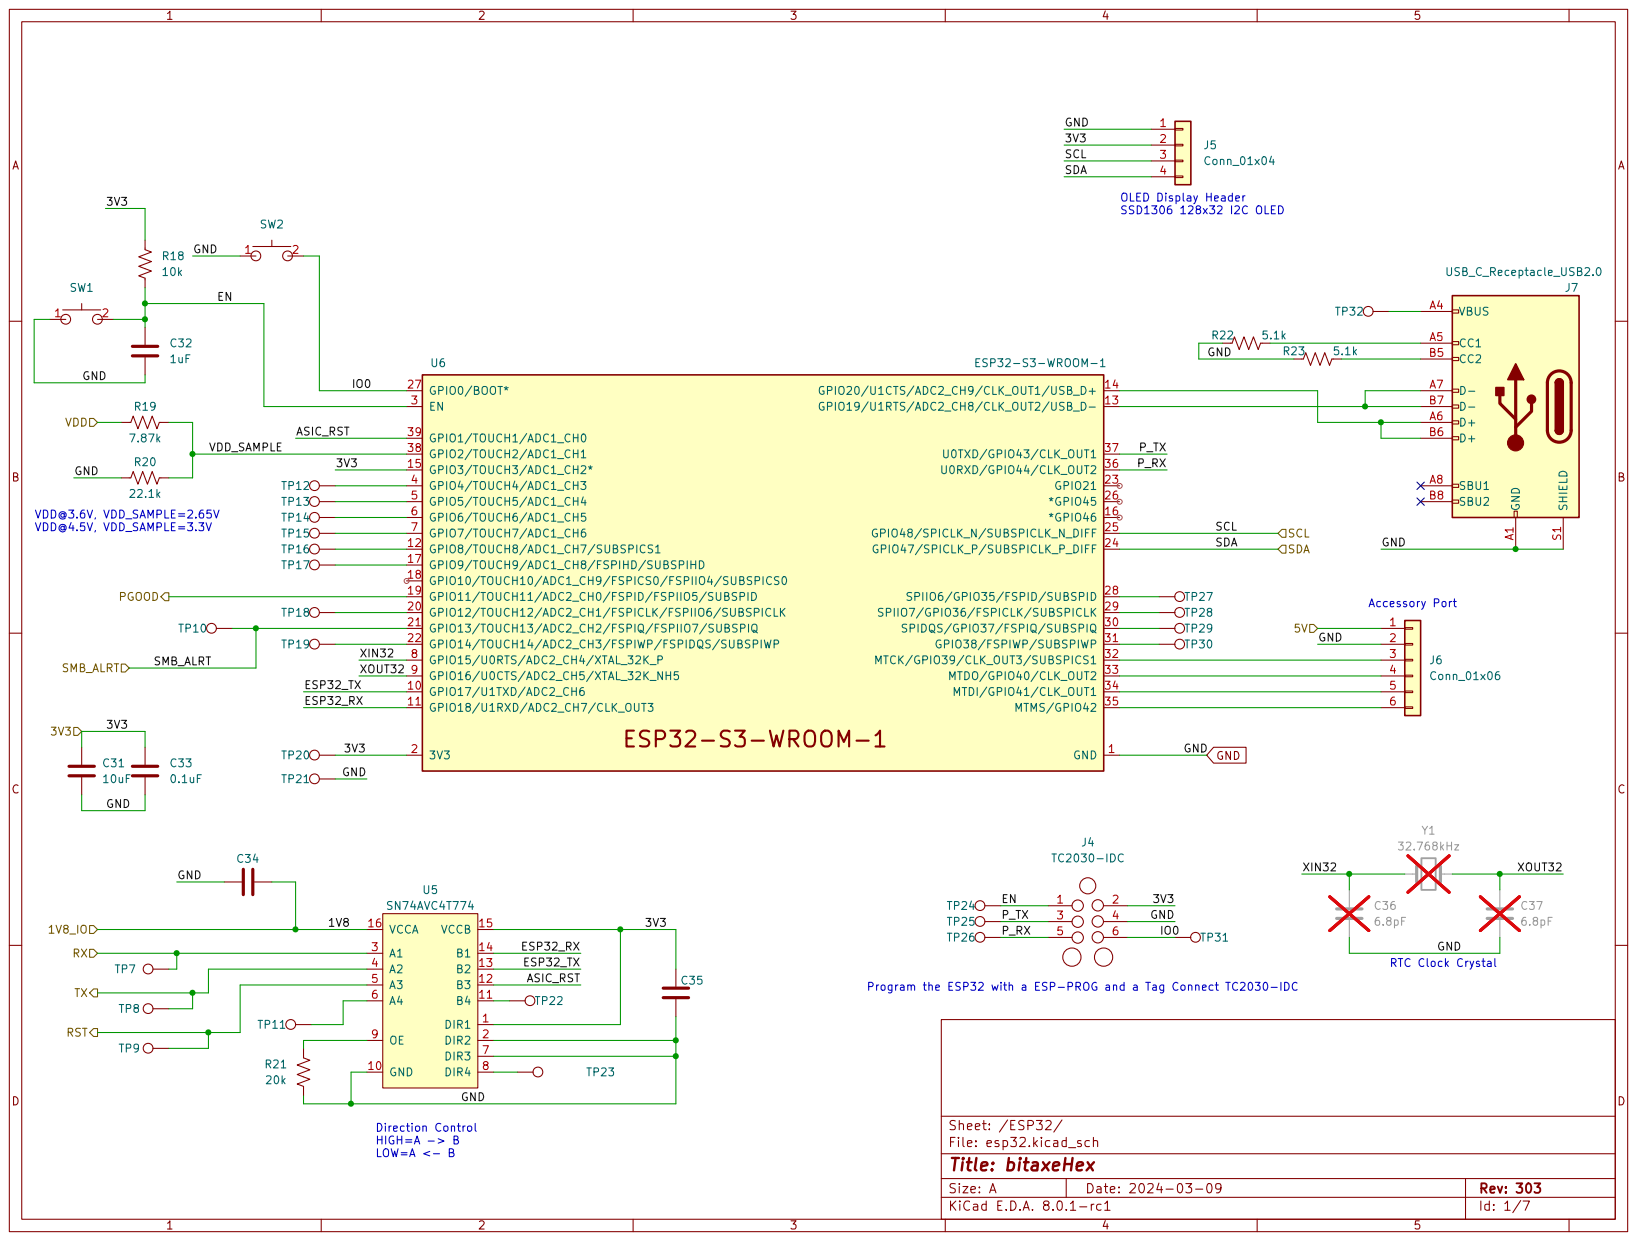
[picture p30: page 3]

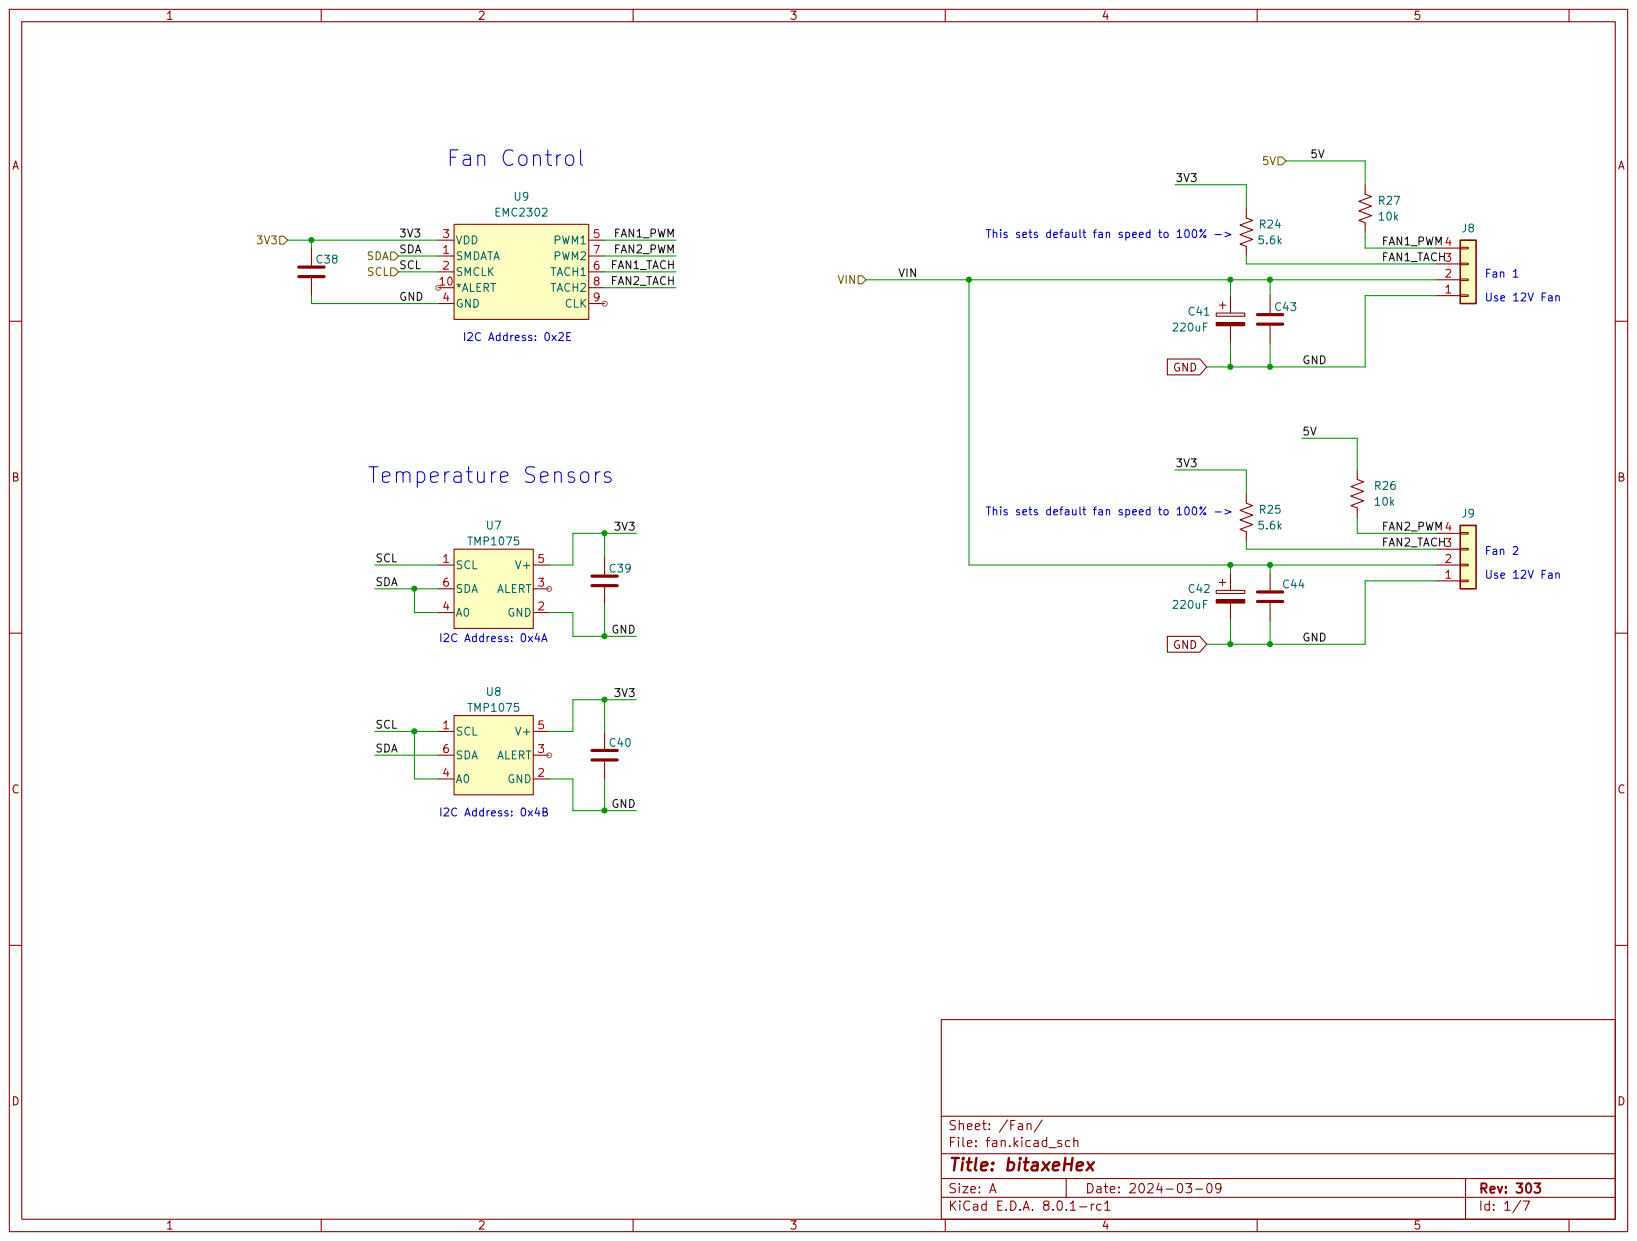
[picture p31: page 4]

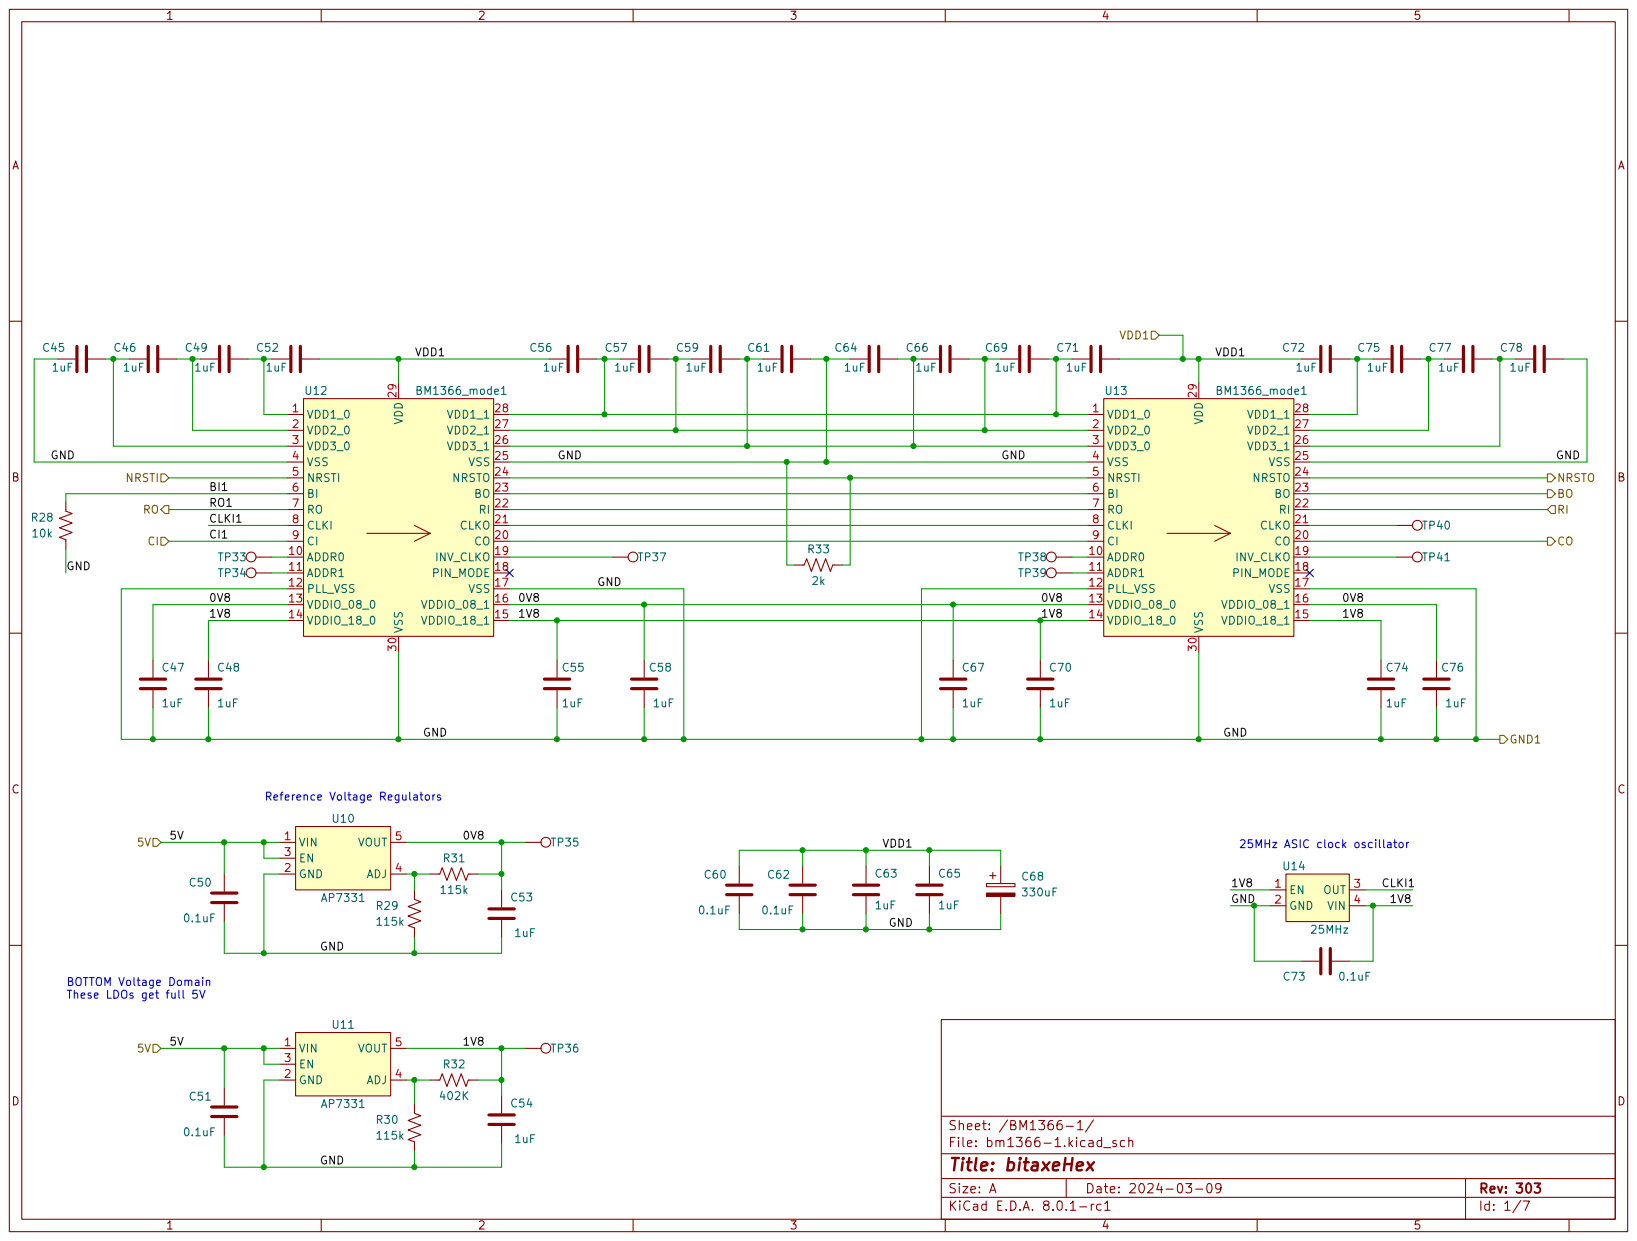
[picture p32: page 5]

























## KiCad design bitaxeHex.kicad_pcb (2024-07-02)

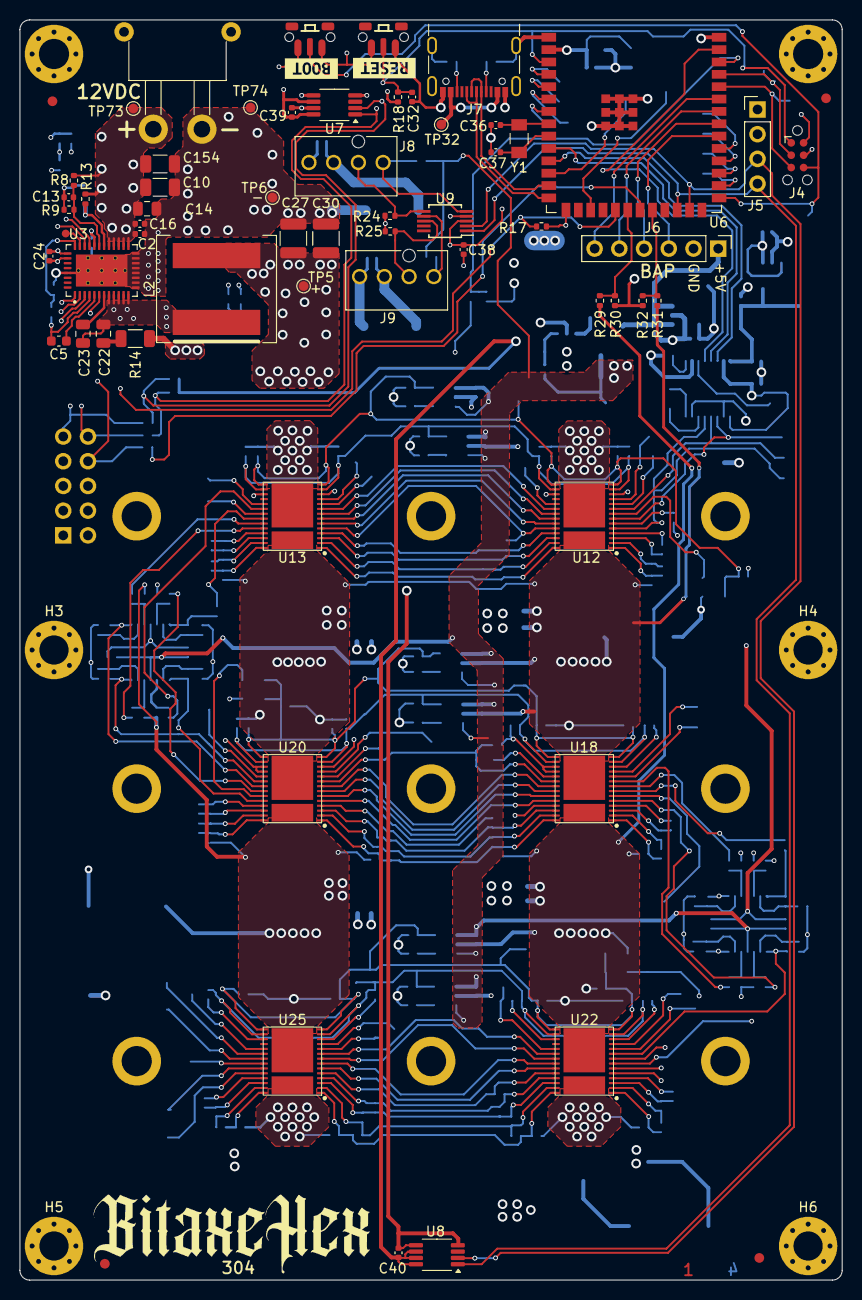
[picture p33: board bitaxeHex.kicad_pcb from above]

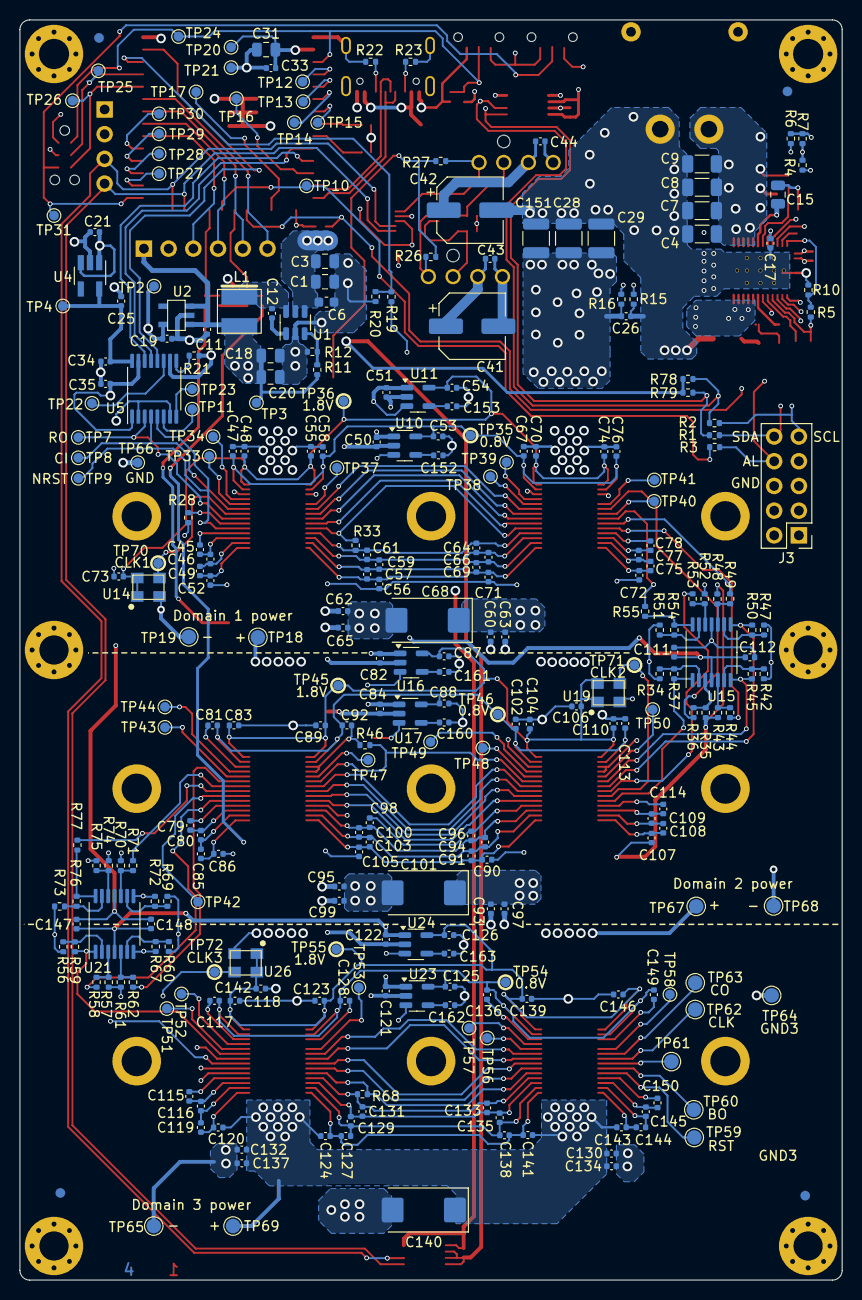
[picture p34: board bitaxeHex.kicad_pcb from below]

Board: 4 copper layers, 84.5 x 129.5 mm, 368 parts (288 on the bottom side), 192 nets.

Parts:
C1, C3, C18, C20, C31: 10uF; C_0805_2012Metric
C2: 4.7nF; C_0402_1005Metric
C4, C7, C8, C10: 22uF; C_1206_3216Metric
C5: 1uF; C_0603_1608Metric
C6: 0.1uF; C_0603_1608Metric
C9, C154: 47uF; C_1206_3216Metric
C11, C19, C21, C25, C32, C45, C46, C47, C48, C49, C52, C53, C54, C55, C56, C57, C58, C59, C61, C63, C64, C65, C66, C67, C69, C70, C71, C72, C74, C75, C76, C77, C78, C79, C80, C81, C83, C85, C86, C87, C88, C89, C90, C91, C92, C94, C96, C97, C98, C99, C100, C102, C103, C104, C105, C107, C108, C109, C110, C112, C113, C114, C115, C116, C117, C118, C119, C120, C123, C124, C125, C126, C127, C128, C129, C131, C133, C134, C135, C136, C137, C138, C139, C141, C143, C144, C145, C146, C148, C149, C150: 1uF; C_0402_1005Metric
C12, C33, C50, C51, C60, C62, C73, C82, C84, C93, C95, C106, C111, C121, C122, C130, C132, C142, C147: 0.1uF; C_0402_1005Metric
C13: 100nF; C_0402_1005Metric
C14, C15: 1uF; C_0805_2012Metric
C16, C26: 2.2nF; C_0402_1005Metric
C17: 4.7uF; C_0402_1005Metric
C22: 1nF; C_0805_2012Metric
C23: 100nF; C_0805_2012Metric
C24: 100pF; C_0402_1005Metric
C27, C28, C29: 47uF; C_1210_3225Metric
C30, C151: 100uF; C_1210_3225Metric
C34, C35, C38, C39, C40, C43, C44: 311-3342-1-ND; C_0402_1005Metric
C36, C37: 6.8pF; C_0402_1005Metric
C41, C42: 220uF; CP_Elec_6.3x7.7
C68, C101, C140: 330uF; CP_EIA-7343-31_Kemet-D_Pad2.25x2.55mm_HandSolder
C152, C153, C160, C161, C162, C163: 0.01uF; C_0402_1005Metric
FID1, FID2, FID3, FID4, FID5, FID6, FID7, FID8: Fiducial; Fiducial_1mm_Mask2mm
H1, H2, H3, H4, H5, H6: MountingHole; MountingHole_3mm_Pad_Via
H7, H8, H9, H10, H11, H12, H13, H14, H15: HeatsinkMountingHole; 3.1mm_mounting
HS1: Heatsink; hex-heatsink
J1: XT30; XT30PW-M
J3: Conn_02x05_Odd_Even; PinHeader_2x05_P2.54mm_Vertical
J4: TC2030-IDC; Tag-Connect_TC2030-IDC-NL_2x03_P1.27mm_Vertical
J5: Conn_01x04; PinHeader_1x04_P2.54mm_Vertical
J6: Conn_01x06; PinHeader_1x06_P2.54mm_Vertical
J7: USB_C_Receptacle_USB2.0; USB_C_Receptacle_GCT_USB4105-xx-A_16P_TopMnt_Horizontal
J8, J9: Conn_01x04; 470531000
L1: 8.2 uH; 74438357082
L2: 680nH; L_Coilcraft_XAL1010-XXX
R1, R2, R3: 0R; R_0402_1005Metric
R4, R5: 17.8K; R_0402_1005Metric
R6, R17, R18, R26, R27, R28, R35, R36, R43, R44, R48, R49, R52, R53, R57, R58, R61, R62, R70, R71, R74, R75: 10k; R_0402_1005Metric
R7: 31.6K; R_0402_1005Metric
R8: 12.7K; R_0402_1005Metric
R9, R16: 1.37K; R_0402_1005Metric
R10: 26.1K; R_0402_1005Metric
R11: 115k; R_0402_1005Metric
R12, R20, R30, R32: 22.1k; R_0402_1005Metric
R13: 10R; R_0402_1005Metric
R14: 1R; R_1206_3216Metric
R15: 49.9R; R_0402_1005Metric
R19, R29, R31: 7.87k; R_0402_1005Metric
R21: 20k; R_0402_1005Metric
R22, R23, R78, R79: 5.1k; R_0402_1005Metric
R24, R25: 5.6k; R_0402_1005Metric
R33, R46, R68: 2k; R_0402_1005Metric
R34, R37, R42, R45, R47, R50, R51, R54, R55, R56, R59, R60, R67, R69, R72, R73, R76, R77: 1k; R_0402_1005Metric
SW1, SW2: SWITCH-SPST; TL3340-switch
TP1: TestPoint; TestPoint_Pad_D0.8mm
TP2, TP3, TP4, TP5, TP6, TP7, TP8, TP9, TP10, TP11, TP12, TP13, TP14, TP15, TP16, TP17, TP20, TP21, TP22, TP23, TP24, TP25, TP26, TP27, TP28, TP29, TP30, TP31, TP32, TP33, TP34, TP37, TP38, TP39, TP40, TP41, TP42, TP43, TP44, TP47, TP48, TP49, TP50, TP51, TP52, TP53, TP56, TP57, TP58, TP66, TP73, TP74: TestPoint; TestPoint_Pad_D1.0mm
TP18, TP67, TP69: +; TestPoint_Pad_D1.5mm
TP19, TP65, TP68: -; TestPoint_Pad_D1.5mm
TP35, TP36, TP45, TP46, TP54, TP55, TP70, TP71, TP72: TestPoint; TestPoint_Pad_D1.0mm_highlight
TP59, TP60, TP61, TP62, TP63, TP64: TestPoint; TestPoint_Pad_D1.5mm
U1: LMR54410; SOT-23-6
U2: RT9080-33GJ5
U3: TPS546D24ARVFR; LQFN40-CLIP
U4: MIC5504; SOT-23-5_HandSoldering
U5: SN74AVC4T774; TSSOP-16_4.4x5mm_P0.65mm
U6: ESP32-S3-WROOM-1; ESP32-S3-WROOM-1U
U7, U8: TMP1075; HVSSOP-8_3x3mm_P0.65mm
U9: EMC2302; MSOP-10_3x3mm_P0.5mm
U10, U17, U23: SGM2036-0v8; TSOT-23-5
U11, U16, U24: SGM2036-1v8; TSOT-23-5
U12, U13, U22, U25: BM1366_mode1; BM1366
U14, U19, U26: 25MHz; O 25,0-JO32-B-1V3-1-T1-LF
U15, U21: TLV3544; TSSOP-14_4.4x5mm_P0.65mm
U18, U20: BM1366_mode0; BM1366
Y1: 32.768kHz; SC32S-7PF20PPM
kibuzzard-65356D4E: G***; kibuzzard-65356D4E
kibuzzard-65356D5C: G***; kibuzzard-65356D5C

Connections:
/1V8: C25.1, C34.2, TP4.1, U4.5 (VOUT), U5.16 (VCCA)
/3V3: C19.1, C21.1, C31.1, C33.1, C35.1, C38.1, C39.1, C40.1, J4.2, J5.2, R17.2, R18.1, R24.2, R25.2, R78.2, R79.1, TP2.1, TP20.1, U2.5 (VOUT), U4.1 (VIN), U4.3 (EN), U5.1 (DIR1), U5.15 (VCCB), U6.2 (3V3), U6.15 (GPIO3/TOUCH3/ADC1_CH2*), U7.6 (A1), U7.8 (V+), U8.6 (A1), U8.7 (A0), U8.8 (V+), U9.3 (VDD)
/5V: C11.1, C18.1, C20.1, C50.2, C51.2, C82.2, C84.2, C111.2, C112.2, C121.2, C122.2, C147.2, C148.2, J6.1, L1.2, R11.1, R26.2, R27.2, TP3.1, U2.1 (VIN), U2.3 (EN), U10.1 (VIN), U10.3 (EN), U11.1 (VIN), U11.3 (EN), U15.4 (V+), U16.1 (VIN), U16.3 (EN), U17.1 (VIN), U17.3 (EN), U21.4 (V+), U23.1 (VIN), U23.3 (EN), U24.1 (VIN), U24.3 (EN)
/BM1366-1/0V8: C47.1, C53.1, C58.1, C67.1, C76.1, TP35.1, U10.5 (VOUT), U12.13 (VDDIO_08_0), U12.16 (VDDIO_08_1), U13.13 (VDDIO_08_0), U13.16 (VDDIO_08_1)
/BM1366-1/1V8: C48.1, C54.1, C55.1, C70.1, C73.1, C74.1, TP36.1, U11.5 (VOUT), U12.14 (VDDIO_18_0), U12.15 (VDDIO_18_1), U13.14 (VDDIO_18_0), U13.15 (VDDIO_18_1), U14.1 (EN), U14.4 (VIN)
/BM1366-1/BI1: R28.2, U12.6 (BI)
/BM1366-1/BO: R49.1, U13.23 (BO)
/BM1366-1/CLKI1: TP70.1, U12.8 (CLKI), U14.3 (OUT)
/BM1366-1/CO: R36.1, U13.20 (CO)
/BM1366-1/NRSTO: R44.1, U13.24 (NRSTO)
/BM1366-1/RI: R55.1, U13.22 (RI)
/BM1366-2/0V8: C81.1, C88.1, C92.1, C102.1, C113.1, TP46.1, U17.5 (VOUT), U18.13 (VDDIO_08_0), U18.16 (VDDIO_08_1), U20.13 (VDDIO_08_0), U20.16 (VDDIO_08_1)
/BM1366-2/1V8: C83.1, C87.1, C89.1, C104.1, C106.1, C110.1, TP45.1, U16.5 (VOUT), U18.14 (VDDIO_18_0), U18.15 (VDDIO_18_1), U19.1 (EN), U19.4 (VIN), U20.14 (VDDIO_18_0), U20.15 (VDDIO_18_1)
/BM1366-2/BI2: R50.1, U15.8, U20.21 (BI)
/BM1366-2/BO: R71.1, U18.8 (BO)
/BM1366-2/CI2: R37.1, U15.1, U20.24 (CI)
/BM1366-2/CLKI2: TP71.1, U19.3 (OUT), U20.23 (CLKI)
/BM1366-2/CO: R58.1, U18.5 (CO)
/BM1366-2/NRSTI2: R45.1, U15.7, U20.20 (NRSTI)
/BM1366-2/NRSTO: R62.1, U18.9 (NRSTO)
/BM1366-2/RI: R77.1, U18.7 (RI)
/BM1366-2/RO2: R53.1, U20.22 (RO)
/BM1366-3/0V8: C117.1, C125.1, C128.1, C136.1, C149.1, TP54.1, U22.13 (VDDIO_08_0), U22.16 (VDDIO_08_1), U23.5 (VOUT), U25.13 (VDDIO_08_0), U25.16 (VDDIO_08_1)
/BM1366-3/1V8: C118.1, C123.1, C126.1, C139.1, C142.1, C146.1, TP55.1, U22.14 (VDDIO_18_0), U22.15 (VDDIO_18_1), U24.5 (VOUT), U25.14 (VDDIO_18_0), U25.15 (VDDIO_18_1), U26.1 (EN), U26.4 (VIN)
/BM1366-3/BI3: R72.1, U21.8, U22.6 (BI)
/BM1366-3/BO3: TP60.1, U25.23 (BO)
/BM1366-3/CI3: R59.1, U21.1, U22.9 (CI)
/BM1366-3/CLKI3: TP72.1, U22.8 (CLKI), U26.3 (OUT)
/BM1366-3/CLKO3: TP62.1, U25.21 (CLKO)
/BM1366-3/CO3: TP63.1, U25.20 (CO)
/BM1366-3/NRSTI3: R67.1, U21.7, U22.5 (NRSTI)
/BM1366-3/NRSTO3: TP59.1, U25.24 (NRSTO)
/BM1366-3/RI3: TP61.1, U25.22 (RI)
/BM1366-3/RO3: R75.1, U22.7 (RO)
/CI: TP8.1, U5.4 (A2), U12.9 (CI)
/ESP32/ASIC_RST: U5.12 (B3), U6.39 (GPIO1/TOUCH1/ADC1_CH0)
/ESP32/EN: C32.1, J4.1, R18.2, SW1.2, TP24.1, U6.3 (EN)
/ESP32/ESP32_RX: U5.14 (B1), U6.11 (GPIO18/U1RXD/ADC2_CH7/CLK_OUT3)
/ESP32/ESP32_TX: U5.13 (B2), U6.10 (GPIO17/U1TXD/ADC2_CH6)
/ESP32/IO0: J4.6, SW2.2, TP31.1, U6.27 (GPIO0/BOOT*)
/ESP32/P_RX: J4.5, TP26.1, U6.36 (U0RXD/GPIO44/CLK_OUT2)
/ESP32/P_TX: J4.3, TP25.1, U6.37 (U0TXD/GPIO43/CLK_OUT1)
/ESP32/VDD1_SAMPLE: R31.1, R32.2, U6.22 (GPIO14/TOUCH14/ADC2_CH3/FSPIWP/FSPIDQS/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)
/ESP32/VDD2_SAMPLE: R29.1, R30.2, U6.20 (GPIO12/TOUCH12/ADC2_CH1/FSPICLK/FSPIIO6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)
/ESP32/VDD3_SAMPLE: R19.1, R20.2, U6.38 (GPIO2/TOUCH2/ADC1_CH1)
/ESP32/XIN32: C36.1, U6.8 (GPIO15/U0RTS/ADC2_CH4/XTAL_32K_P), Y1.1
/ESP32/XOUT32: C37.1, U6.9 (GPIO16/U0CTS/ADC2_CH5/XTAL_32K_NH5), Y1.2
/Fan/FAN1_PWM: J8.4, R27.1, U9.5 (PWM1)
/Fan/FAN1_TACH: J8.3, R24.1, U9.6 (TACH1)
/Fan/FAN2_PWM: J9.4, R26.1, U9.7 (PWM2)
/Fan/FAN2_TACH: J9.3, R25.1, U9.8 (TACH2)
/NRSTI: TP9.1, U5.5 (A3), U12.5 (NRSTI)
/Power/AGND: C13.2, C15.1, R6.1, R7.2, R9.2, R10.2, U3.37 (AGND)
/Power/PGOOD: R17.1, U3.1 (PGD), U6.19 (GPIO11/TOUCH11/ADC2_CH0/FSPID/FSPIIO5/S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)
/Power/PMB_ALRT: J3.8, R3.2, U3.6 (SMB_ALRT)
/Power/PMB_SCL: J3.9, R2.2, U3.3 (PMB_CLK)
/Power/PMB_SDA: J3.10, R1.2, U3.2 (PMB_DATA)
/Power/SW: C22.1, C23.2, L2.1, U3.8 (SW), U3.9 (SW), U3.10 (SW), U3.11 (SW), U3.12 (SW)
/RO: TP7.1, U5.3 (A1), U12.7 (RO)
/SCL: J5.3, R2.1, R78.1, U6.25 (GPIO48/SPICLK_N/SUBSPICLK_N_DIFF), U7.2 (SCL), U8.2 (SCL), U9.2 (SMCLK)
/SDA: J5.4, R1.1, R79.2, U6.24 (GPIO47/SPICLK_P/SUBSPICLK_P_DIFF), U7.1 (SDA), U8.1 (SDA), U9.1 (SMDATA)
/SMB_ALRT: R3.1, TP10.1, U6.21 (GPIO13/TOUCH13/ADC2_CH2/FSPIQ/FSPIIO7/S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)
/VDD: C26.1, C27.1, C28.1, C29.1, C30.1, C120.2, C124.1, C130.2, C132.2, C134.1, C137.1, C140.1, C141.2, C143.1, C151.1, L2.2, R16.1, R19.2, R57.1, R61.1, R70.1, TP5.1, TP69.1, U22.29 (VDD), U25.29 (VDD)
/VDD1: C52.2, C56.1, C60.2, C62.2, C63.1, C65.1, C68.1, C71.2, C72.1, C79.1, C81.2, C82.1, C83.2, C84.1, C87.2, C88.2, C89.2, C92.2, C93.1, C95.1, C96.2, C97.2, C98.1, C99.2, C101.2, C102.2, C104.2, C106.2, C110.2, C113.2, C114.2, C160.2, C161.2, R31.2, R34.2, R42.2, R46.1, R47.2, R51.2, R74.1, TP18.1, TP68.1, U12.29 (VDD), U13.29 (VDD), U16.2 (GND), U17.2 (GND), U18.4 (VSS), U18.12 (PLL_VSS), U18.17 (VSS), U18.18 (PIN_MODE), U18.25 (VSS), U18.30 (VSS), U19.2 (GND), U20.4 (VSS), U20.12 (PLL_VSS), U20.17 (VSS), U20.18 (PIN_MODE), U20.25 (VSS), U20.30 (VSS)
/VDD2: C86.2, C90.1, C93.2, C95.2, C97.1, C99.1, C101.1, C105.2, C107.1, C115.1, C117.2, C118.2, C121.1, C122.1, C123.2, C125.2, C126.2, C128.2, C130.1, C131.2, C132.1, C133.1, C134.2, C136.2, C137.2, C139.2, C140.2, C142.2, C146.2, C149.2, C150.2, C162.2, C163.2, R29.2, R35.2, R43.1, R48.1, R56.2, R60.2, R68.1, R69.2, R73.2, TP64.1, TP65.1, TP67.1, U18.29 (VDD), U20.29 (VDD), U22.4 (VSS), U22.12 (PLL_VSS), U22.17 (VSS), U22.25 (VSS), U22.30 (VSS), U23.2 (GND), U24.2 (GND), U25.4 (VSS), U25.12 (PLL_VSS), U25.17 (VSS), U25.25 (VSS), U25.30 (VSS), U26.2 (GND)
/VIN: C1.1, C2.1, C3.1, C4.1, C6.2, C7.1, C8.1, C9.1, C10.1, C14.1, C16.1, C41.1, C42.1, C43.1, C44.1, C154.1, J1.1 (+V), J8.2, J9.2, R8.1, R13.1, TP73.1, U1.4 (EN), U1.5 (VIN), U3.21 (PVIN), U3.22 (PVIN), U3.23 (PVIN), U3.24 (PVIN), U3.25 (PVIN)
GND: C1.2, C2.2, C3.2, C4.2, C6.1, C7.2, C8.2, C9.2, C10.2, C11.2, C14.2, C16.2, C17.2, C18.2, C19.2, C20.2, C21.2, C25.2, C26.2, C27.2, C28.2, C29.2, C30.2, C31.2, C32.2, C33.2, C34.1, C35.2, C36.2, C37.2, C38.2, C39.2, C40.2, C41.2, C42.2, C43.2, C44.2, C45.1, C47.2, C48.2, C50.1, C51.1, C53.2, C54.2, C55.2, C58.2, C60.1, C61.2, C62.1, C63.2, C64.1, C65.2, C67.2, C68.2, C70.2, C73.2, C74.2, C76.2, C78.2, C111.1, C112.1, C147.1, C148.1, C151.2, C152.2, C153.2, C154.2, H1.1, H2.1, J1.2 (GND), J3.6, J4.4, J5.1, J6.2, J7.A1 (GND), J7.A12 (GND), J7.B1 (GND), J7.B12 (GND), J7.S1 (SHIELD), J8.1, J9.1, R12.2, R14.2, R15.2, R20.1, R21.1, R22.1, R23.1, R28.1, R30.1, R32.1, R33.1, R52.1, SW1.1, SW2.1, TP6.1, TP19.1, TP21.1, TP66.1, TP74.1, U1.2 (GND), U2.2 (GND), U3.13 (PGND), U3.14 (PGND), U3.15 (PGND), U3.16 (PGND), U3.17 (PGND), U3.18 (PGND), U3.19 (PGND), U3.20 (PGND), U3.41 (PAD), U4.2 (GND), U5.2 (DIR2), U5.7 (DIR3), U5.10 (GND), U6.1 (GND), U6.40 (GND), U6.41 (GND), U7.4 (GND), U7.5 (A2), U7.7 (A0), U8.4 (GND), U8.5 (A2), U9.4 (GND), U10.2 (GND), U11.2 (GND), U12.4 (VSS), U12.12 (PLL_VSS), U12.17 (VSS), U12.25 (VSS), U12.30 (VSS), U13.4 (VSS), U13.12 (PLL_VSS), U13.17 (VSS), U13.25 (VSS), U13.30 (VSS), U14.2 (GND), U15.11 (V-), U21.11 (V-)
unnamed: C22.2, R14.1
unnamed: J6.3, U6.32 (MTCK/GPIO39/CLK_OUT3/SUBSPICS1)
unnamed: J6.4, U6.33 (MTDO/GPIO40/CLK_OUT2)
unnamed: J6.5, U6.34 (MTDI/GPIO41/CLK_OUT1)
unnamed: J6.6, U6.35 (MTMS/GPIO42)
unnamed: J7.A5 (CC1), R22.2
unnamed: J7.B5 (CC2), R23.2
unnamed: J7.A4 (VBUS), J7.A9 (VBUS), J7.B4 (VBUS), J7.B9 (VBUS), TP32.1
unnamed: R54.1, R55.2, U15.14
unnamed: R76.1, R77.2, U21.14
unnamed: C12.2, U1.1 (CB)
unnamed: R11.2, R12.1, U1.3 (FB)
unnamed: C12.1, L1.1, U1.6 (SW)
unnamed: TP1.1, U3.31 (ADRSEL)
unnamed: C15.2, R13.2, U3.26 (AVIN)
unnamed: C23.1, U3.7 (BOOT)
unnamed: C5.1, R4.1, R5.1, U3.4 (BP1V5)
unnamed: C5.2, U3.5 (DRTN)
unnamed: C13.1, R8.2, R9.1, U3.27 (EN/UVLO)
unnamed: C24.2, R15.1, U3.34 (GOSNS)
unnamed: R5.2, R10.1, U3.32 (MSEL1)
unnamed: R6.2, U3.29 (MSEL2)
unnamed: C17.1, U3.28 (VDD5)
unnamed: C24.1, R16.2, U3.33 (VOSNS)
unnamed: R4.2, R7.1, U3.30 (VSEL)
unnamed: TP11.1, U5.6 (A4)
unnamed: TP22.1, U5.11 (B4)
unnamed: TP23.1, U5.8 (DIR4)
unnamed: R21.2, U5.9 (OE)
unnamed: TP12.1, U6.4 (GPIO4/TOUCH4/ADC1_CH3)
unnamed: TP13.1, U6.5 (GPIO5/TOUCH5/ADC1_CH4)
unnamed: TP14.1, U6.6 (GPIO6/TOUCH6/ADC1_CH5)
unnamed: TP15.1, U6.7 (GPIO7/TOUCH7/ADC1_CH6)
unnamed: TP16.1, U6.12 (GPIO8/TOUCH8/ADC1_CH7/SUBSPICS1)
unnamed: TP17.1, U6.17 (GPIO9/TOUCH9/ADC1_CH8/FSPIHD/SUBSPIHD)
unnamed: J7.A7 (D-), J7.B7 (D-), U6.13 (GPIO19/U1RTS/ADC2_CH8/CLK_OUT2/USB_D-)
unnamed: J7.A6 (D+), J7.B6 (D+), U6.14 (GPIO20/U1CTS/ADC2_CH9/CLK_OUT1/USB_D+)
unnamed: TP30.1, U6.31 (GPIO38/FSPIWP/SUBSPIWP)
unnamed: TP29.1, U6.30 (SPIDQS/GPIO37/FSPIQ/SUBSPIQ)
unnamed: TP27.1, U6.28 (SPIIO6/GPIO35/FSPID/SUBSPID)
unnamed: TP28.1, U6.29 (SPIIO7/GPIO36/FSPICLK/SUBSPICLK)
unnamed: C152.1, U10.4 (BP)
unnamed: C153.1, U11.4 (BP)
unnamed: TP33.1, U12.10 (ADDR0)
unnamed: TP34.1, U12.11 (ADDR1)
unnamed: U12.23 (BO), U13.6 (BI)
unnamed: U12.21 (CLKO), U13.8 (CLKI)
unnamed: U12.20 (CO), U13.9 (CI)
unnamed: TP37.1, U12.19 (INV_CLKO)
unnamed: R33.2, U12.24 (NRSTO), U13.5 (NRSTI)
unnamed: U12.22 (RI), U13.7 (RO)
unnamed: C49.2, C52.1, U12.1 (VDD1_0)
unnamed: C56.2, C57.1, C69.2, C71.1, U12.28 (VDD1_1), U13.1 (VDD1_0)
unnamed: C46.2, C49.1, U12.2 (VDD2_0)
unnamed: C57.2, C59.1, C66.2, C69.1, U12.27 (VDD2_1), U13.2 (VDD2_0)
unnamed: C45.2, C46.1, U12.3 (VDD3_0)
unnamed: C59.2, C61.1, C64.2, C66.1, U12.26 (VDD3_1), U13.3 (VDD3_0)
unnamed: TP38.1, U13.10 (ADDR0)
unnamed: TP39.1, U13.11 (ADDR1)
unnamed: TP40.1, U13.21 (CLKO)
unnamed: TP41.1, U13.19 (INV_CLKO)
unnamed: C72.2, C75.1, U13.28 (VDD1_1)
unnamed: C75.2, C77.1, U13.27 (VDD2_1)
unnamed: C77.2, C78.1, U13.26 (VDD3_1)
unnamed: R35.1, R36.2, U15.3 (+)
unnamed: R34.1, R37.2, U15.2 (-)
unnamed: R43.2, R44.2, U15.5 (+)
unnamed: R42.1, R45.2, U15.6 (-)
unnamed: R48.2, R49.2, U15.10 (+)
unnamed: R47.1, R50.2, U15.9 (-)
unnamed: R52.2, R53.2, U15.12 (+)
unnamed: R51.1, R54.2, U15.13 (-)
unnamed: C161.1, U16.4 (BP)
unnamed: C160.1, U17.4 (BP)
unnamed: TP43.1, U18.10 (ADDR0)
unnamed: TP44.1, U18.11 (ADDR1)
unnamed: U18.21 (BI), U20.8 (BO)
unnamed: U18.24 (CI), U20.5 (CO)
unnamed: U18.23 (CLKI), U20.6 (CLKO)
unnamed: TP42.1, U18.6 (CLKO)
unnamed: TP47.1, U18.19 (INV_CLKO)
unnamed: R46.2, U18.20 (NRSTI), U20.9 (NRSTO)
unnamed: U18.22 (RO), U20.7 (RI)
unnamed: C79.2, C80.1, U18.3 (VDD1_0)
unnamed: C94.2, C96.1, C98.2, C100.1, U18.26 (VDD1_1), U20.3 (VDD1_0)
unnamed: C80.2, C85.1, U18.2 (VDD2_0)
unnamed: C91.2, C94.1, C100.2, C103.1, U18.27 (VDD2_1), U20.2 (VDD2_0)
unnamed: C85.2, C86.1, U18.1 (VDD3_0)
unnamed: C90.2, C91.1, C103.2, C105.1, U18.28 (VDD3_1), U20.1 (VDD3_0)
unnamed: TP48.1, U20.10 (ADDR0)
unnamed: TP49.1, U20.11 (ADDR1)
unnamed: TP50.1, U20.19 (INV_CLKO)
unnamed: C109.2, C114.1, U20.26 (VDD1_1)
unnamed: C108.2, C109.1, U20.27 (VDD2_1)
unnamed: C107.2, C108.1, U20.28 (VDD3_1)
unnamed: R57.2, R58.2, U21.3 (+)
unnamed: R56.1, R59.2, U21.2 (-)
unnamed: R61.2, R62.2, U21.5 (+)
unnamed: R60.1, R67.2, U21.6 (-)
unnamed: R70.2, R71.2, U21.10 (+)
unnamed: R69.1, R72.2, U21.9 (-)
unnamed: R74.2, R75.2, U21.12 (+)
unnamed: R73.1, R76.2, U21.13 (-)
unnamed: TP51.1, U22.10 (ADDR0)
unnamed: TP52.1, U22.11 (ADDR1)
unnamed: U22.23 (BO), U25.6 (BI)
unnamed: U22.21 (CLKO), U25.8 (CLKI)
unnamed: U22.20 (CO), U25.9 (CI)
unnamed: TP53.1, U22.19 (INV_CLKO)
unnamed: R68.2, U22.24 (NRSTO), U25.5 (NRSTI)
unnamed: U22.22 (RI), U25.7 (RO)
unnamed: C119.2, C120.1, U22.1 (VDD1_0)
unnamed: C124.2, C127.1, C138.2, C141.1, U22.28 (VDD1_1), U25.1 (VDD1_0)
unnamed: C116.2, C119.1, U22.2 (VDD2_0)
unnamed: C127.2, C129.1, C135.2, C138.1, U22.27 (VDD2_1), U25.2 (VDD2_0)
unnamed: C115.2, C116.1, U22.3 (VDD3_0)
unnamed: C129.2, C131.1, C133.2, C135.1, U22.26 (VDD3_1), U25.3 (VDD3_0)
unnamed: C162.1, U23.4 (BP)
unnamed: C163.1, U24.4 (BP)
unnamed: TP56.1, U25.10 (ADDR0)
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

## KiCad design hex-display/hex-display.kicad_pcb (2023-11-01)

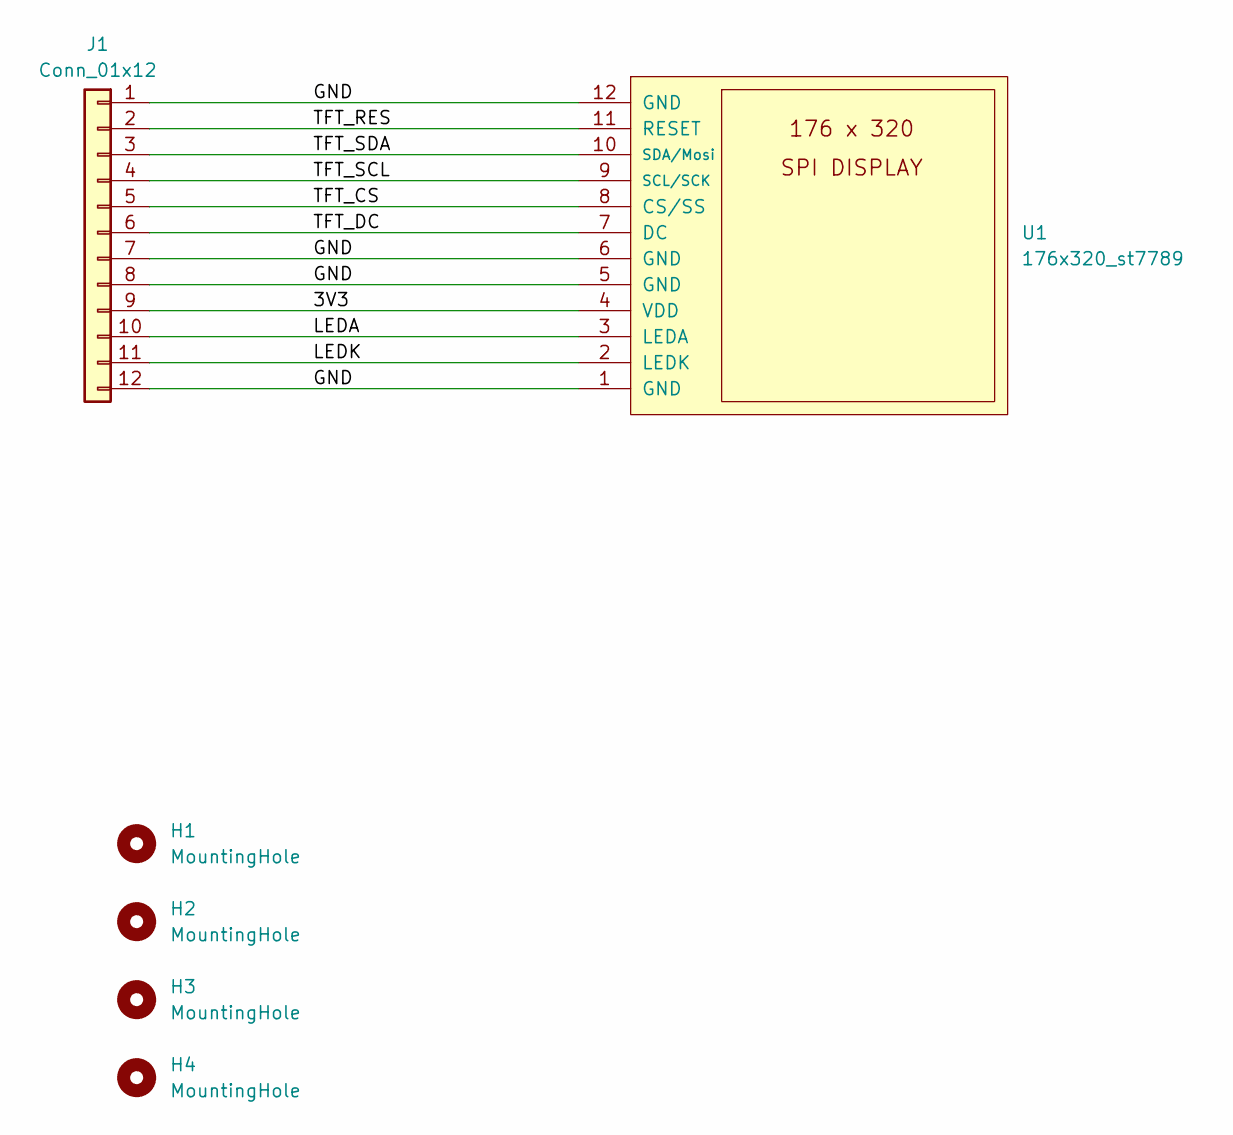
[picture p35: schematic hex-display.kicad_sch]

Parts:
H1, H2, H3, H4: MountingHole; 4mm_mounting
J1: Conn_01x12; JST_GH_BM12B-GHS-TBT_1x12-1MP_P1.25mm_Vertical
U1: 176x320_st7789; ST7789-176x320

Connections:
/3V3: J1.9, U1.4 (VDD)
/GND: J1.1, J1.7, J1.8, J1.12, U1.1 (GND), U1.5 (GND), U1.6 (GND), U1.12 (GND)
/LEDA: J1.10, U1.3 (LEDA)
/LEDK: J1.11, U1.2 (LEDK)
/TFT_CS: J1.5, U1.8 (CS/SS)
/TFT_DC: J1.6, U1.7 (DC)
/TFT_RES: J1.2, U1.11 (RESET)
/TFT_SCL: J1.4, U1.9 (SCL/SCK)
/TFT_SDA: J1.3, U1.10 (SDA/Mosi)

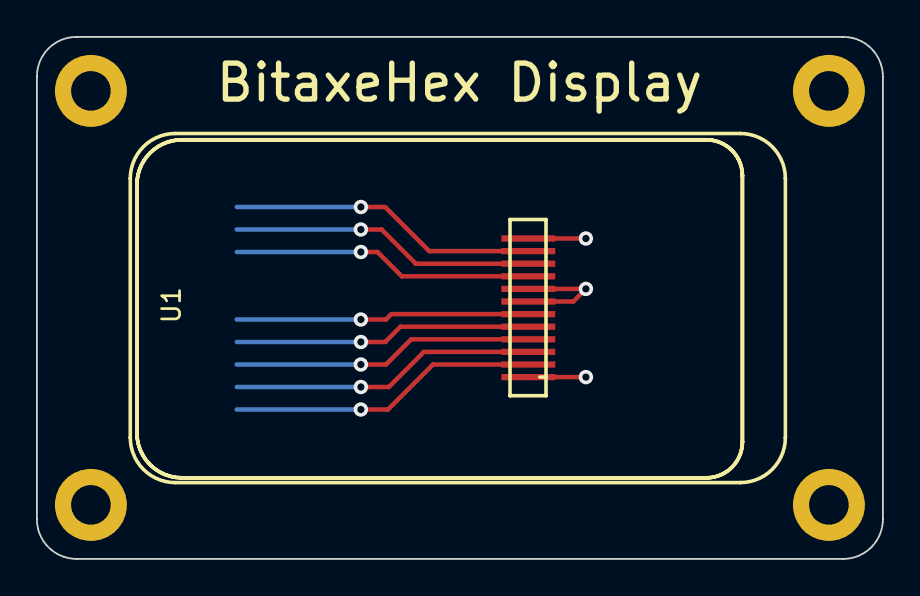
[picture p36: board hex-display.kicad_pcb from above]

Board: 2 copper layers, 47.0 x 29.0 mm, 6 parts (1 on the bottom side), 9 nets.

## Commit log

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2023-09-01 added DK and PARTNO for the fan controller and temp sensors
    [fan.kicad_sch]
2023-09-11 moved all custom symbols and footprints to the bitaxe library
    [bitaxeUltraHex.kicad_pcb, bitaxeUltraHex.kicad_sch, bm1366-1.kicad_sch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]
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2023-09-12 flip center asic pads
    [bitaxeUltraHex.kicad_pcb]
2023-09-14 Replace reference voltage regulators with new one
    [bitaxeUltraHex.kicad_pcb, bitaxeUltraHex.kicad_sch, bm1366-1.kicad_sch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]
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2023-09-15 changed USB connector to USB C. updated display.
    [bitaxeUltraHex.kicad_pcb, bitaxeUltraHex.kicad_sch, esp32.kicad_sch]
2023-09-15 added enclosure edge cuts. added heatsink outline. changed the two middle voltage domain ASICs to mode 0 so the data lines can snake through all 6 chips.
    [bitaxeUltraHex.kicad_pcb, bm1366-1.kicad_sch, bm1366-2.kicad_sch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]
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2023-09-24 add 1v8 LDO and consolidate voltage level translators
    [bitaxeUltraHex.kicad_sch, bm1366-1.kicad_sch, esp32.kicad_sch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]
2023-09-25 Resolved all unconnected pins, re-annotated, reviewed for layout
    [bitaxeUltraHex.kicad_sch, bm1366-1.kicad_sch, bm1366-2.kicad_sch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]
2023-09-27 replace Q5 with BSS123
    [bm1366-1.kicad_sch, bm1366-3.kicad_sch, esp32.kicad_sch]
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2023-09-29 fixed part numbers and footprints on the buck reg FETs
    [bitaxeUltraHex.kicad_pcb, power.kicad_sch]
2023-09-30 add some power planes and do some comms routing
    [bitaxeUltraHex.kicad_pcb, bm1366-1.kicad_sch]
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2023-10-01 add screw terminals, replace OLED display with optional connector
    [bitaxeUltraHex.kicad_pcb, bitaxeUltraHex.kicad_sch, esp32.kicad_sch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]
2023-10-02 major rework of the power supply section
    [bitaxeUltraHex.kicad_pcb, bitaxeUltraHex.kicad_sch, power.kicad_sch]
2023-10-03 add 3D model of screw terminal to footprint
    [7770-ScrewTerminal.step, bitaxeUltraHex.kicad_pcb]
2023-10-04 Revert "More parts placement"
    This reverts commit 19c08c982123baf7c8f78aef6401739b38439525.
    [bitaxeUltraHex.kicad_pcb, esp32.kicad_sch]
2023-10-04 more parts placement, switch to ESP32 with external antenna
    [bitaxeUltraHex.kicad_pcb, esp32.kicad_sch]
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2023-10-09 Routing of front end ESP32, power supply, fan controller, level translator, and programming connector
    [bitaxeUltraHex.kicad_pcb, esp32.kicad_sch]
2023-10-10 shuffle resistors on RI/RO, more routing on ASICs
    [bitaxeUltraHex.kicad_pcb, bitaxeUltraHex.kicad_sch, bm1366-1.kicad_sch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]
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2023-10-13 add oscillators, large bypass caps, start routing reference voltages
    [bitaxeUltraHex.kicad_pcb, bm1366-1.kicad_sch, bm1366-2.kicad_sch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]
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2023-10-16 added some models and regenerated the board render
    [EVQ-9P701P.stp, bitaxeUltraHex.kicad_pcb, bm1366.STP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]
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2023-10-17 Add ESP32 testpoints, fix all DRC errors
    [bitaxeUltraHex.kicad_pcb, bm1366-1.kicad_sch, bm1366-2.kicad_sch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]
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2023-10-19 switched PWR_EN to GPIO10 so that we can match this up better with ultra-v1.2
    [bitaxeUltraHex.kicad_pcb, bitaxeUltraHex.kicad_sch, esp32.kicad_sch]
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2023-10-22 re added mounting holes and heatsink mounting holes.
    [bitaxeUltraHex.kicad_pcb, bitaxeUltraHex.kicad_sch]
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2023-10-22 added BOM, schematic PDF, position file and candidate gerbers
    [bitaxeUltraHex BOM.xlsx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]
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2023-10-23 rename project file to "bitaxeHex". remove old gerbers
    [bitaxeHex.kicad_pcb, bitaxeHex.kicad_sch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]
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2023-10-23 link heatsink to schematic and re-link heatsink mounting holes :P
    [bitaxeHex.kicad_pcb, bitaxeHex.kicad_sch, bm1366-1.kicad_sch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]
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2023-10-24 fix D1 part numbers
    [bitaxeHex BOM.xlsx, bitaxeHex.kicad_pcb, bitaxeUltraHex BOM.xlsx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]
2023-10-24 U10,U11 BOM fix
    [bitaxeHex BOM.xlsx]
2023-10-24 a little less paste on the BM1366 power pads
    [bitaxeHex.kicad_pcb]
2023-10-25 sorting out new info on the BM1366 pinouts
    [bm1366-1.kicad_sch, bm1366-2.kicad_sch, bm1366-3.kicad_sch]
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2023-11-01 combine stencils into the main gerber directory and zip file. Add readme file to gerbers
    [bitaxeHex-B_Stencil.gbr, bitaxeHex-F_Stencil.gbr]
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2023-11-01 fix footprint on U3, generate new gerbers
    [bitaxeHex-B_Cu.gbr, bitaxeHex-B_Mask.gbr, bitaxeHex-B_Paste.gbr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]
2023-11-03 fix copper power plane to ASIC to cover more vias
    [bitaxeHex-B_Cu.gbr, bitaxeHex-B_Mask.gbr, bitaxeHex-B_Paste.gbr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]
2023-11-03 add pcb design for power plane fix
    [bitaxeHex.kicad_pcb]
2023-11-03 Fix some part numbers in the BOM
    [bitaxeHex.kicad_pcb, bitaxeHex.xlsx, bm1366-1.kicad_sch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]
2023-11-03 Fix BOM to reflect part number changes
    [bitaxeHex BOM.xlsx, bitaxeHex.xlsx]
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2023-11-05 add note to specify resistor value for 1.8V reference voltage
    [bm1366-1.kicad_sch, bm1366-2.kicad_sch, bm1366-3.kicad_sch]
2023-11-06 updated 1V2 to 1V8 and updated the BOM
    [bitaxeHex BOM.xlsx, bm1366-1.kicad_sch, bm1366-2.kicad_sch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]
2023-11-09 Fix package for C15, C20, C21, C22 on schematic and on BOM. PCB footprints were already correct
    [bitaxeHex BOM.xlsx, power.kicad_sch]
2023-11-10 change R5 to DNP on schematic and BOM
    [bitaxeHex BOM.xlsx, power.kicad_sch]
2023-11-10 change 1 ohm power resistors to 2 watt parts, changed schematic and BOM
    [bitaxeHex BOM.xlsx, bm1366-1.kicad_sch, bm1366-2.kicad_sch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]
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2023-11-20 fix mounting holes size/spacing, add pullup to PWR_EN signal
    [bitaxeHex.kicad_pcb, esp32.kicad_sch, power.kicad_sch]
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2023-12-06 replace TPS40305 buck regulator circuit with LM27402
    [bitaxeHex.kicad_pcb, power.kicad_sch]
2023-12-07 finish schematic for power supply section, add part numbers and footprints
    [esp32.kicad_sch, power.kicad_sch]
2023-12-08 Create footprints for new MOSFETS, start on new power supply
    [bitaxeHex.kicad_pcb, power.kicad_sch]
2023-12-09 remove old 5V power supply, prepare footprints for new 5V buck supply, switch fans to 12V
    [IND_4030-WE-MAPI_WRE.step, bitaxeHex.kicad_pcb, bitaxeHex.kicad_sch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]
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2023-12-11 finish parts placement for new power supply designs
    [bitaxeHex.kicad_pcb]
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2023-12-17 Fix level translator negative input
    [bitaxeHex.kicad_pcb, bm1366-2.kicad_sch, bm1366-3.kicad_sch]
2023-12-17 Finished routing, generate gerbers, edit new BOM for v301
    [bitaxeHex-300-BOM.xlsx, bitaxeHex-301-BOM.xlsx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]
2023-12-18 fix LM27402 footprint
    [RUM0016A.stp, bitaxeHex.kicad_pcb, power.kicad_sch]
2023-12-18 fix warnings on H3 and H4 mounting holes
    [bitaxeHex.kicad_pcb, bitaxeHex.kicad_sch, power.kicad_sch]
2023-12-18 added oscillator 3d
    [3225-oscillator.step, bitaxeHex.kicad_pcb]
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2023-12-18 update resistor values for VDD sample divider on schematic and BOM
    [bitaxeHex-301-BOM.xlsx, esp32.kicad_sch]
2023-12-18 fix notes regarding VDD_SAMPLE voltage
    [esp32.kicad_sch]
2023-12-19 Extend pads on U4 for easier soldering, generate renders of front and back
    [bitaxeHex.kicad_pcb]
2023-12-19 Move USB-C connector away from ESP32 to make room for chunky cables
    [bitaxeHex.kicad_pcb, bitaxeHex.kicad_sch]
2023-12-19 add updated BOM and new gerber files for v301
    [bitaxeHex-301-BOM.xlsx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]
2023-12-19 fix rotation of 3D models of power MOSFETs
    [bitaxeHex.kicad_pcb]
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2023-12-23 Fix DK partnumber for 402K resistor
    [bm1366-1.kicad_sch, bm1366-2.kicad_sch, bm1366-3.kicad_sch]
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2023-12-29 first draft of new power supply schematic using TPS546D24
    [bitaxeHex.kicad_sch, bm1366-1.kicad_sch, bm1366-2.kicad_sch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]
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2024-01-07 increase size of copper planes, generate final BOM
    [bitaxeHex-302-BOM.xlsx, bitaxeHex.kicad_pcb, bm1366-1.kicad_sch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]
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2024-01-08 via organizing on In1. removed islands from In1 and In2
    [bitaxeHex.kicad_pcb]
2024-01-08 eliminate more traces on In1, expand copper pour a little more
    [bitaxeHex.kicad_pcb]
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2024-01-08 fix DRC errors, generate new gerbers
    [bitaxeHex-B_Cu.gbr, bitaxeHex-B_Mask.gbr, bitaxeHex-B_Paste.gbr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]
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2024-02-13 fix notes about dedicated oscillator components
    [bm1366-2.kicad_sch, bm1366-3.kicad_sch]
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2024-03-03 Add mounting holes, remove some caps and power resistors
    [bitaxeHex.kicad_pcb, bitaxeHex.kicad_sch, bm1366-1.kicad_sch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]
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2024-03-23 remove old display connector and add BAP, remove USB 5V supply, cleanup routing
    [TL3340AF160QG.step, bitaxeHex.kicad_pcb, esp32.kicad_sch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]
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2024-03-25 changed trace/space to 8mil. changed default via to 0.3/0.5mm. fixed all DRC errors
    [bitaxeHex-B_Cu.gbr, bitaxeHex-B_Mask.gbr, bitaxeHex-B_Paste.gbr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]
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2024-05-20 swap out electrolytic output capacitor, add XT30 power connector
    [bitaxeHex.kicad_pcb, bitaxeHex.kicad_sch, bm1366-1.kicad_sch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]
2024-05-24 fix OP-AMP power supply, connect to GND,+5V
    [bitaxeHex.kicad_pcb, bitaxeHex.kicad_sch, bm1366-1.kicad_sch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]
2024-05-24 swap adjustable LDOs for fixed voltage LDOs
    [bitaxeHex.kicad_pcb, bm1366-1.kicad_sch, bm1366-2.kicad_sch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]
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2024-05-25 connect RESET signal in parallel across domains
    [bitaxeHex.kicad_pcb, bm1366-1.kicad_sch, bm1366-2.kicad_sch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]
2024-05-25 revert parallel reset modification back to serial passthrough
    [bitaxeHex.kicad_pcb, bm1366-1.kicad_sch, bm1366-2.kicad_sch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]
2024-05-27 update inductor silkscreen to include line which indicates start of winding orientation
    [bitaxeHex.kicad_pcb]
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2024-06-09 Clean up DRC errors vor v304
    [bitaxeHex.kicad_pcb, bm1366-1.kicad_sch, bm1366-2.kicad_sch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]
2024-06-11 fix regulator input caps
    [bitaxeHex.kicad_pcb, power.kicad_sch]
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2024-07-02 fix airwires from Issue #43
    [bitaxeHex.kicad_pcb]
